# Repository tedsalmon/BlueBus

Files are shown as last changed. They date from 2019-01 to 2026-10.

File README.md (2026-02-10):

View this project on [CADLAB.io](https://cadlab.io/project/1479).

# BlueBus

BlueBus is a Bluetooth interface module for BMW vehicles equipped with the I-Bus. It emulates a CD changer on the I-Bus to provide seamless Bluetooth audio, hands-free telephony, and comfort feature integration while maintaining full compatibility with original vehicle systems.

## Supported Vehicles

BlueBus is compatible with BMW vehicles using the I-Bus architecture:

| Platform | Models | Years |
|---|---|---|
| E38 | 7 Series | 1994-2001 |
| E39 | 5 Series | 1995-2004 |
| E46 | 3 Series | 1997-2006 |
| E52 | Z8 | 2000-2003 |
| E53 | X5 | 1999-2006 |
| E83 | X3 | 2003-2010 |
| E85 | Z4 | 2003-2008 |
| E86 | Z4 | 2005-2008 |
| R50/R52/R53 | MINI | 2000-2006 |

## Features

### Bluetooth Audio
* A2DP streaming with high-quality audio output over AAC
* AVRCP metadata display (artist, title, album) on vehicle screens
* Full playback control via vehicle buttons

### Hands-Free Telephony
* HFP (Hands-Free Profile) with factory microphone integration
* Caller ID display on vehicle screen
* Answer/end calls via vehicle controls
* Telephone LED control (Red = Device Disconnected, Green = Connected)
* Voice recognition support via Siri / Google Assistant
* Emulation of OE telephone system (Minus the Menus, for now)

### Vehicle Integration
* Native DSP compatibility (analog and S/PDIF inputs)
* On-Board Computer data display (coolant temp, ambient temp, oil temp)
* GPS time synchronization for vehicles with factory Nav
* Park Distance Control integration

### Comfort Features
* Auto-lock at configurable speed threshold
* Auto-unlock on ignition off
* Comfort turn signals (Tap to signal)
* Parking lamp control

### System
* Firmware upgradable via USB
* Multi-language support (9 languages)
* Up to 8 paired Bluetooth devices

## Supported Display Units

| Unit | Description | Display |
|---|---|---|
| BMBT | Board Monitor (Navigation) | Full graphical menus |
| MID | Multi-Information Display | 24-character single line |
| CD53 | Business CD Radio | 11-character single line |
| MIR | Multi-Information Radio | Single line display |

## Hardware

### Core Components
| Component | Description |
|---|---|
| PIC24FJ1024GA606 | 16-bit MCU @ 16MHz, 1MB Flash |
| BM83 | Microchip Bluetooth 5.0 Module |
| Melexis TH3122.4 | I-Bus Transceiver |

### Audio Chain
| Component | Description |
|---|---|
| PCM5122 | Line-Level DAC, 2.1V RMS, 113 dB SNR |
| DIT4096 | S/PDIF Encoder |
| PAM8406 | 5W Class-D/Class-AB Amplifier |

### Interfaces
| Component | Description |
|---|---|
| FT231XS | USB to UART (firmware updates) |

## Configuration

Settings are stored in EEPROM and can be configured through the vehicle display menus. Categories include:

* **Audio** - DAC gain, DSP input source, volume offsets
* **Telephony** - HFP mode, microphone gain, volume
* **Comfort** - Auto-lock speed, blinker count, lighting options
* **UI** - Language, temperature units, display preferences
* **Navigation** - Auto-zoom, map display mode

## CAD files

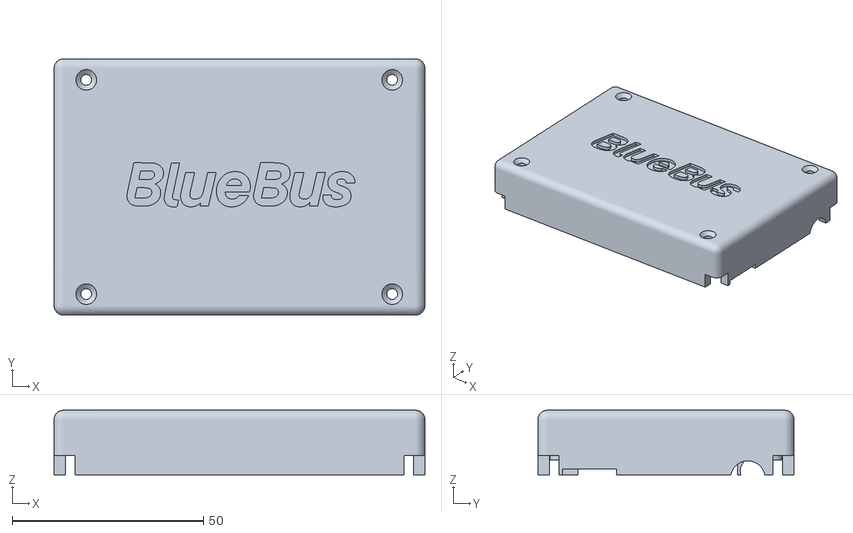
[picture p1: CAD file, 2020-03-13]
enclosure/hw1_v1/BlueBus_Top.stl
97.0 x 67.0 x 16.9

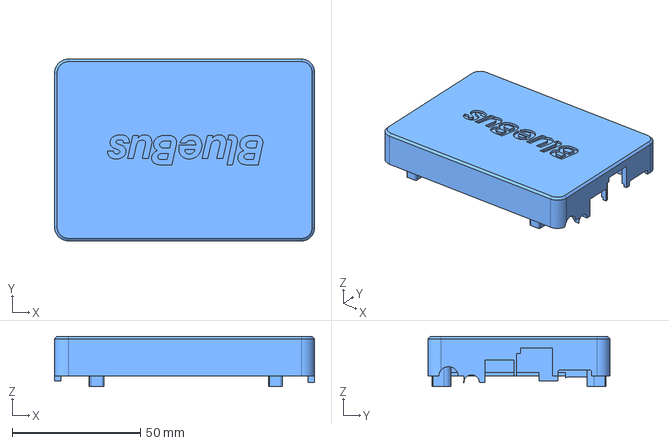
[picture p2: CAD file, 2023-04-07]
enclosure/hw2_v3/BlueBus v3 Top.step
101.5 x 71.0 x 19.7 mm

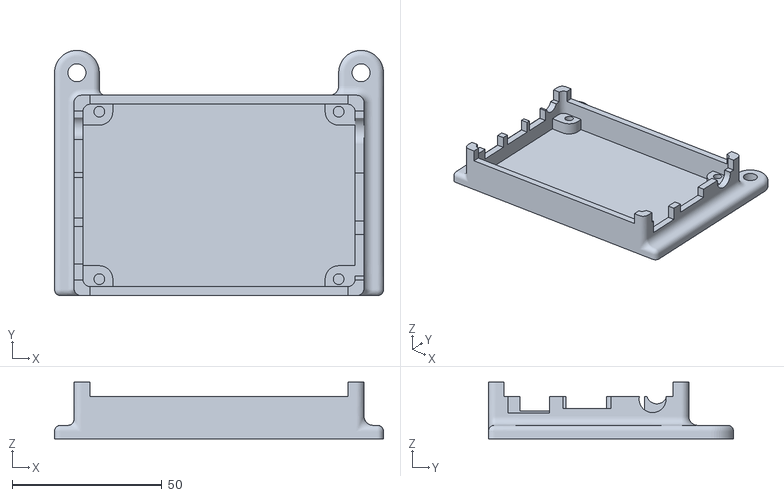
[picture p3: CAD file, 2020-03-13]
enclosure/hw1_v1/BlueBus_Bottom.stl
110.0 x 82.0 x 18.9

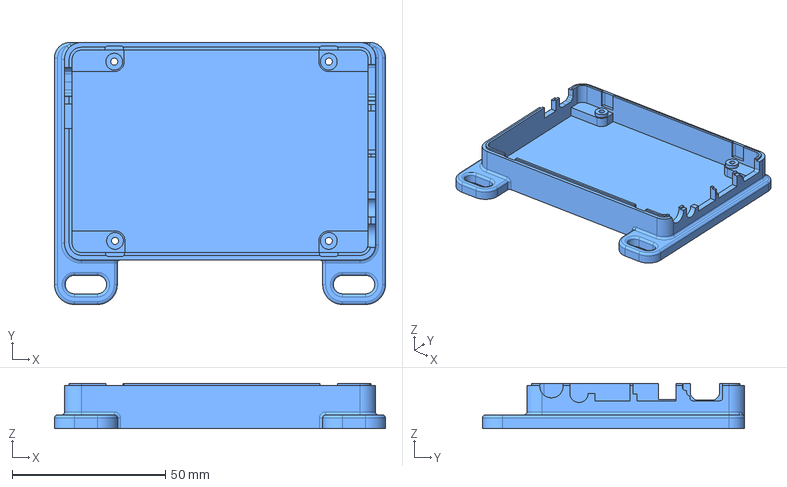
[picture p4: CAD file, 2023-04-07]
enclosure/hw2_v3/BlueBus v3 Bottom.step
108.0 x 85.5 x 14.8 mm

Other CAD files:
enclosure/hw2_v3/BlueBus v3 Bottom.stl
enclosure/hw2_v3/BlueBus v3 Top.stl

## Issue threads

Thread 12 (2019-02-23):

Clear "Track" from C43 based nav units

tedsalmon, 2019-02-23:

tedsalmon, 2019-04-02:
This was fixed in 45bc7327c35bebcffc25bb4a61e0422613abcdb5

Closed 2019-04-02.

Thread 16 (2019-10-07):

Feature Request : Door Unlock/Lock Comfort Entry

mykekfz, 2019-10-07:
Hello Ted,

How bad will power consumption be if we were to search for paired devices every 2 secs?

I'm thinking of a comfort entry feature where if the module detects a paired device, it send the message to unlock the door the opposite happens when paired devices are not within range.

let me know what you think.

Mike

harryberlin, 2019-10-07:
Did you have tried to unlock with ibus message the car, after secure lock?

tedsalmon, 2019-10-09:
Hey Mike (@mykekfz ),

Power consumption of the unit at idle is about 50mA. It could theoretically be used to lock / unlock the car, but people like myself, who have an attached garage might run into issues as the car would constantly lock/unlock as the phone comes into proximity with the vehicle.

Futhermore, the module is designed to power off with the rest of the car and wake up after the reception of the next IBus message. This is to prevent the module from flattening your battery over time.

@harryberlin ,

I'm sorry, but I haven't actually done any testing with the Unlock/Lock IBus message(s), so I can't answer your question :(

Thanks!
-Ted

mykekfz, 2019-10-10:
Hello Ted,

Will using the command "RSSI" be helpful with scaling the proximity of the connected device?
as for battery draw, i don't think it will be an issue since the draw is so minuscule doubt it will be an issue. You can always notify the user about the consequences of this feature if they were to activate it.

@harryberlin i dont see why it will not work since the command to unlock (key press from remote) its also sent through the but i could be wrong.

@Ted is there a way/command i can use to send RAW bus message for testing?

Regards,
Mike

tedsalmon, 2019-10-11:
@mykekfz (Mike),

That might work, but I feel like it may lead to some wonky results as different cars will have the BlueBus installed in different locations which will lead to different signal strengths at different distances. Still, a very good idea!

Let me digest it a bit and see what I can come up with.

I will send you a firmware that will allow you to send messages directly to the IBus

Thanks!
-Ted

ShonkyCH, 2019-10-11:
50mA is quite high for a car although may not seem like it's that much. It's certainly not "miniscule".

BMW maximum spec is 30mA. Most are in to 30-50mA range. So an extra 50mA (assuming the worst case 30mA) is 2-3x that in total.

tedsalmon, 2019-10-11:
@ShonkyCH,

You're right and I forgot to touch on that aspect. I did the math on this for an E46 a while back and the draw would flatten the battery in about a month, which is why I decided to implement "sleep" mode where the BlueBus goes to sleep 60 seconds after the last IBus message and wakes up on the next message.

Daily driven cars would have no problem with this type of drain, but any cars that sit for more than a few days may experience issues.

Thanks!
-Ted

harryberlin, 2019-10-11:
in my case (e39), the gm don't processes diagnistic actions, if the car is secure locked.

Tomcatex, 2019-12-12:
Hello Ted,

Just had an idea and I stumbled upon this thread.
About comfort locking, can you add a feature to unlock the car, if it has been previously locked, when the key is pulled out?
My E39 locks automatically when speed is about 20km/h. But it does not unlock when stopped.
Can you add something so that car unlocks (VW-group has this) when key is pulled out?

Thanks

tedsalmon, 2019-12-17:
@Tomcatex,

Sorry for the delayed response. This should be pretty easy to implement, honestly.

Since the car has just been turned off, the GM should still listen for diagnostic commands.

Thanks!
-Ted

mykekfz, 2019-12-23:
ca

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

Cant this be done via coding with NCSexpert?

tedsalmon, 2019-12-23:
@mykekfz,

Yes, on some vehicles the GM will allow you to code that. I'm not ready to code the GM via the BlueBus just yet, so having an option for it makes sense still :)

Thanks!
-Ted

mykekfz, 2019-12-23:
I was just thinking of MCU available space.

If a feature is available via simple coding, I don't see the point of it adding to the bluebus.

On the flip side not everyone knows how to use ncsexpert.

tedsalmon, 2019-12-23:
@mykekfz,

I'm not too worried about MCU space just yet -- I have 94% ROM remaining as it is :smile:

It would be nice to allow the BlueBus to simply code the option in the GM, rather than using Diagnostic commands.

harryberlin, 2019-12-23:
it is pobble to lock the car by speed from ibus. so you don't coding.
but one point there are different messages between e46 and e39, old and new models.

tedsalmon, 2019-12-23:
> it is possible to lock the car by speed from ibus. so you don't need coding.
> but one point, there are different messages between e46 and e39, old and new models.

I noticed this as well -- looks like the E46 takes `0x97 0x01` to unlock, while the E39 takes `0x00 0x0B` to unlock. Similar differences exist in terms of the LCM bulb diagnostic messages.

Tomcatex, 2020-01-15:
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

I have NCS. Is there a specific line for this? Can yo post any more info?
I tried to find it, no luck.

E39 '02 Euro 525d, LCM III.

harryberlin, 2020-01-15:
on e39 you have to log the kbus for groundmodul

tedsalmon, 2020-02-12:
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

For what it's worth, the above diagnostics messages are all that's available. In my E46, it appears that the EWS "key out"/"immobilized" message is what prevents the GM5 from processing any further messages. I have yet to test out artificially notifying the car that the EWS is no longer immobilized and then trying to run diagnostics.

tedsalmon, 2020-05-12:
FWIW, The BlueBus now supports comfort locks and unlock, but they are not done as OP requested due to limitations with diagnostic messages. I also can't perform diagnostics on the GM after the EWS has been armed (key removed), so there's that.

Thanks!
-Ted

Closed 2020-05-12.

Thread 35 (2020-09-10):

BlueBus display not redrawing

rsporsche, 2020-09-10:
I have a German delivered 1999 E39 M5 with Business Audio (tape) and MID.

I've noticed that the MID display is very quickly overwritten and the BlueBus is not redrawing.

Example: If I click the 'Settings' button for BlueBus, I see 'Settings HFP: On' displayed and the menu updates with Back, Edit, <, >, etc. But this is quickly replaced by the CD changer display and menu, i.e. 'CD 1-01' and '*1, 2, 3, 4, etc.'. My understanding is that the BlueBus would see that the display had been redrawn by the RAD or IKE and immediately redraw it's own text but that is not happening.

I have attached a log file, demonstrating this.

The firmware version is 1.1.14, I noticed that there is a 1.1.16, should I upgrade?

Note that I have also had some other issues such as BlueBus responding to button presses when it should not (e.g. when changing bass/treble/etc.) and a few times the radio has 'lost' the BlueBus and I can only select radio or tape. I don't know whether these issues are related so I will create separate issues when I have been able to captures logs.

The attached log file was created with 'bt', 'sys' and 'ibus' on but I had to unplug the USB and cycle the ignition after setting those initially and I don't know whether that would have affected these settings. I assume by the volume of ibus messages that it did not.

[[Com COM3] (2020-09-09_160349).log](https://github.com/tedsalmon/BlueBus/files/5204500/Com.COM3.2020-09-09_160349.log)

tedsalmon, 2020-09-11:
@rsporsche,

This is directly related to #2, but I will keep it open nonetheless. The issue is that the MID doesn't like how quickly the BlueBus writes the UI again, so some things are missed at times.

However, I am working on hijacking the UI by emulating the factory TEL module. The MID lends itself wholly available to the TEL and prevents other modules (DSP, RAD) from writing to it while the TEL view is active. This would allow me to ignore the tug-of-war with the RAD.

I'll have more on this soon.

Thanks!
-Ted

harryberlin, 2020-09-11:
test in my case: MID without phone option/button does not handle the phone messages.

tedsalmon, 2020-09-11:
@harryberlin,

Can you try issuing this frame on the I-Bus?

`C8 04 C0 27 02 41`

The display should blank out and accept messages from the TEL.

Thanks!
-Ted

tedsalmon, 2020-09-11:
@harryberlin,

If that doesn't work, also issue these messages:

```
C8 04 BF 02 31 40
C8 04 C0 02 30 3E
```

Then issue:
```C8 04 C0 27 02 41```

harryberlin, 2020-09-11:
will take some time. because, MID is not connected at the moment.

rsporsche, 2020-09-11:
>
> The issue is that the MID doesn't like how quickly the BlueBus writes the UI again, so some things are missed at times.
>

Based on the log file it looks as though the BlueBus isn't issuing the ibus commands to redraw the UI though?

I'm assuming that the lines marked [SELF] are commands sent by the BlueBus and the leading number on each line is uptime in milliseconds?

Btw, I have some experience in software development, also with embedded systems, and would be happy to help with this project particularly as related to the MID interface if possible. The only drawback is that the only device I have to test on is the one in my car.

tedsalmon, 2020-09-11:
@harryberlin,

No worries, I appreciate you testing. Please note that I have updated the frame as I gave the XOR checksum in decimal rather than octal :(

@rsporsche,

That happens too, because the BlueBus tries to differentiate its own menu writes from that of the RAD, which means looking at the nuances of the way the RAD writes to the screen -- another reason to move into a bespoke UI mode.

The `[SELF]` messages are frames sent by the BlueBus and you're correct about the timestamp.

Are you based in the U.S.? I have a boneyard of BlueBus prototypes and units that failed due to the recall issue, and I can definitely spare one of those :).

-Ted

rsporsche, 2020-09-11:
I wondered if it would be an option to keep track of the commands that were issued by the BlueBus to update the MID and redraw if a MID display command is seen that doesn't match that 'known' set?

Maybe the TEL idea works better though.

I'm in Germany unfortunately. I wasn't thinking so much of the BlueBus but more the radio/MID. I guess I would also need the IKE?

Is it possible to 'brick' the BlueBus?

tedsalmon, 2020-09-11:
@rsporsche,

This isn't as easy as it sounds because I have to wait until the RAD is done "speaking" in order to override the MID display again, otherwise things are liable to not write out consistently. That means "knowing" when the RAD is done speaking. This is why I want to move to bespoke UI mode :smile:

You only need a RAD/MID for a bench setup. The IKE is icing on the cake (I have a 540i IKE, but I don't use it with the MID).

It is not possible to brick the BlueBus. The bootloader lives in the first 0x1800 addresses of memory and has been protected against accidental writes. See: https://github.com/tedsalmon/BlueBus/blob/master/firmware/bootloader/lib/protocol.c#L74

tedsalmon, 2020-09-11:
@rsporsche,

Can you please try: https://t3ddftw.s3.us-east-2.amazonaws.com/BlueBus/firmware/bluebus_1_1_15_mid_tel_ui.hex

You will need to use the `Audio` button to exit the BlueBus UI. Any subsequent presses of the 1 - 6 buttons will force the MID to enter "BlueBus" mode again.

Text scrolling is still a bit off, but it should at least stay pinned to the MID.

Thanks!
-Ted

rsporsche, 2020-09-24:
Thanks Ted, just installed the new firmware today.

First impressions are that the Bluebus menu works now but it's still responding to button presses when I think it shouldn't.

Example: I press the TONE button by the tape deck and it shows me options for bass/treble/etc. but if I click one of those it immediately switch back to the BlueBus.
Same if I press the BC button on the MID and try selecting any of the options such as CONS/RANGE/etc.

I logged the output while pressing the TONE, AUDIO, and BC buttons ten times. Looks like there is a message for the BC and AUDIO buttons that could be detected but nothing that I can see for the TONE button, presumably it's part of the radio so the radio only writes to the display.

I'm wondering if it would be possible to detect when these buttons are pressed and switch out of the BlueBus menu mode until the AUDIO button is pressed again?

Also, the MODE button is effectively lost when entering the BlueBus menu. I guess this is what you mean by "You will need to use the Audio button to exist the BlueBus UI"? I think it would be possible for the BlueBus to handle the mode button press though?

tedsalmon, 2020-09-24:
@rsporsche,

This firmware should fix those issues: https://t3ddftw.s3.us-east-2.amazonaws.com/BlueBus/firmware/bluebus_1_1_15_1.hex

On the MODE button issue, it is technically possible, but ultimately difficult to emulate the MODE button press. The new firmware places the MID in TEL mode, so the RAD stops listening to commands / button presses from the MID (and the MID stops addressing the RAD). I would have to give up TEL UI mode, then emulate the MID mode button press, and this can be clumsy depending on the amount of bus traffic at the time.

Thanks!
-Ted

rsporsche, 2020-09-25:
Thanks Ted,

So far it looks like a big improvement. I think it's at a point where I could live with it pretty happily.

Come to think of it, while it would be nice to retain the MODE button, I don't use the radio or tape so it's not really a problem.

I had been thinking I could create a device to isolate the radio on a second IBUS network and selectively relay messages, but not worth the effort at this point and wouldn't work as well with the 'TEL' GUI.

tedsalmon, 2020-09-28:
@rsporsche,

I'm going to mark this as resolved :). Here's the latest binary: https://t3ddftw.s3.us-east-2.amazonaws.com/BlueBus/firmware/bluebus_1_1_15_3.hex

This was resolved in 48396c9

Thanks!
-Ted

rsporsche, 2020-10-02:
Thanks Ted, I'll check out the latest version.
I noticed that the MID display seems to switch off when ending a call now but I'll log a new bug report for that if it still happens with the latest firmware.

tedsalmon, 2020-10-02:
@rsporsche,

This isn't a bug moreso than it is a lack of a feature. I tell the car that a call is active and the MID automatically blanks out because it expects the phone system to write something about the call to the screen, and I have yet to add that.

Thanks!
-Ted

harryberlin, 2020-10-03:
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

The message is working. The others had no effect.

Closed 2020-09-28.

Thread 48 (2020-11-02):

CD43 Support

E39NLA, 2020-11-02:
Enhancement request - are there any plans to support the CD43 head unit with bluebus? This would provide an obvious upgrade path to bluebus for E32/34/36 fans I would think. I believe this the only single-DIN style head unit out there with ibus support (the C33 and C43 cassette head units are "m-bus" I believe).

tedsalmon, 2020-11-02:
@E39NLA -

Thanks! The CD43 is already supported and I have a couple customers using a BlueBus in an E36 / E36 Z3.

Thanks!
-Ted

E39NLA, 2020-11-02:
Ah. Then I might have a technical glitch here. I have a CD43 in my E34 with a late E36 CD changer harness (that is, the 3pin ibus with 6pin audio connectors) spliced in to the radio harness. The ibus wire from the 3pin connector is run directly to Pin 7 at the back of the CD43. Pressing "CD" just gives me NO DISC. Bluebus shows the green indicator light for a few minutes then seems to power down on it's own. I've already verified all wiring is good (continuity OK).

Will note I am using a "generic" CD43 (i.e. the one Rover Group made under license from BMW) but everything I've read online assures me that the non-BMW CD43's support ibus. I have bench tested it by hooking it to a spare E38 MID I have and they do talk to each other.

tedsalmon, 2020-11-02:
@E39NLA

Try the following command in the BlueBus terminal:

`set ign alwayson`

That should allow it to work :smile:
-Ted

E39NLA, 2020-11-02:
Will give that a shot! Will that have any impact on bluebus use in my E39? Right now I only have one unit which I am intending to share between my two cars.

tedsalmon, 2020-11-02:
@E39NLA,

Yes, it will make it so the BlueBus connects and starts playing any time the E39 is woken up (unlocked, door open, etc). This isn't a problem with the E34 because the CD43 doesn't come to life without the key in the ignition.

Thanks!
-Ted

E39NLA, 2020-11-02:
Ah. So I take it that the bluebus is normally looking for a "wake" message from the ibus connection, and this configuration option tells it to ignore and turn on whenever 12V is applied.

tedsalmon, 2020-11-02:
@E39NLA,

The BlueBus expects the IKE/KOMBI to broadcast the ignition status, at which point the value determines the state of the BlueBus. Since the E31/2/4/6 aren't I/K-Bus cars, this data is unavailable. Setting `ign alwayson` tells the BlueBus to broadcast the ignition on status to itself as soon as it wakes up.

 See: https://github.com/tedsalmon/BlueBus/blob/master/firmware/application/handler.c#L238

-Ted

E39NLA, 2020-11-02:
Terminal is just giving me a "Command Not Found" error when inputting SET IGN ALWAYSON. Updated the firmware to 1.1.16

tedsalmon, 2020-11-02:
@E39NLA,

Oops, try:

`set ign alwayson on`

Similarly, to toggle it back off:

`set ign alwayson off`

See: https://github.com/tedsalmon/BlueBus/blob/master/firmware/application/ui/cli.c#L472

Thanks!
-Ted

E39NLA, 2020-11-02:
Okay, getting closer. Accepted the command and when installed in my E34 it would pair to my phone. But the CD43 doesn't want to talk to it still. "NO DISC" like before.

tedsalmon, 2020-11-02:
@E39NLA.

Do you have a laptop you can plug into the unit while it's in the car? I would like to see if you're getting any I-Bus traffic when you issue the command: `set log ibus on`

Thanks!
-Ted

E39NLA, 2020-11-02:
Yes I'll give that a shot.

E39NLA, 2020-11-02:
Ok, got it all plugged into my laptop in the car. Entered the log ibus command.

tedsalmon, 2020-11-02:
> Ok, got it all plugged into my laptop in the car. Entered the log ibus command.

Can you run the command "get ibus"? It should return something...

E39NLA, 2020-11-02:
Get ibus just returns "OK"

tedsalmon, 2020-11-02:
> Get ibus just returns "OK"

You have an issue with the I-Bus, then.

Either theres a continuity issue, or you need to pull the I-Bus up to 12v through a 10k resistor.

Thanks!
-Ted

E39NLA, 2020-11-03:
Just checked the voltages at my ibus connector. Red (batt) is 11.99v, yellow (ibus or Pin 7) is 11.50v. Is the wire order correct at the connector?
![Uploading 20201102_185615.jpg…]()

tedsalmon, 2020-11-03:
@E39NLA

That looks fine, and the voltages are good. Can you run "reboot" before you run `get ibus`?

Make sure the radio is on, too.

Thanks!
-Ted

E39NLA, 2020-11-03:
Same as before. Get ibus yields only "OK." Rebooted both with and without the radio on.

tedsalmon, 2020-11-03:
@E39NLA,

And as a sanity check, everything works well in the E39 still?

Do you have an OE CD Changer to test on the E34?

Thanks!
-Ted

E39NLA, 2020-11-03:
Sadly I tossed out my E39 cd changer after I got the bluebus (it never worked anyways). May be able to borrow one from a friend in a few days.

Bluebus still works fine in the E39, no issues.

tedsalmon, 2020-11-03:
> Sadly I tossed out my E39 cd changer after I got the bluebus (it never worked anyways). May be able to borrow one from a friend in a few days.
>
> Bluebus still works fine in the E39, no issues.

With `set log ibus on`, when you issue the `get ibus` command, are you seeing the frame come back in the buffer? You should if the line is "good".

E39NLA, 2020-11-03:
Found this old cd changer simulator I used to use for aux input. Plugged it in and the CD43 would talk to it. Played off my phone just fine (3.5mm jack) with clear sound.

So I guess the ibus on the CD43 is working?

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

tedsalmon, 2020-11-03:
@E39NLA

Are you sure that's a CD43? I don't know them well enough to tell from the images, but what I do see is that your box is an M-Bus emulator, rather than I-Bus, which suggests the radio speaks with the CDC over M-Bus and not I-Bus...

Thanks!
-Ted

E39NLA, 2020-11-03:
Positive. I know the label says M-bus but that I believe is referring to the other side of the box, which is the DIN-8 connector used for Alpine CD changers. If you google the model (ABWM35) you'll see it was designed for I-bus BWM's. This box works in my E39 too, so I know it's an I-bus device.

tedsalmon, 2020-11-03:
> Positive. I know the label says M-bus but that I believe is referring to the other side of the box, which is the DIN-8 connector used for Alpine CD changers. If you google the model (ABWM35) you'll see it was designed for I-bus BWM's. This box works in my E39 too, so I know it's an I-bus device.

Are you based in the US? The only thing I can think of is that the BlueBus doesn't have enough of a pull up to 12v on the IBus line, so I can make a patch cable with a built in pull up.

Apart from that, I've got nothing, especially considering the BlueBus works fine in your E39.

-Ted

mykekfz, 2020-11-03:
OP what is the part number on the CD43?

there are 2 version of the CD43 mBUS version and IBus version.

E39NLA, 2020-11-06:
PN is 7640263342.

Ted: yes, I'm in Northern NJ.

E39NLA, 2020-11-08:
As an added test: have a donor E39 CD changer that I plugged into the CD43. Worked without issue.

tedsalmon, 2020-11-09:
@E39NLA

Do you happen to have a 10k ohm through-hole resistor laying around?

-Ted

E39NLA, 2020-11-11:
No, but I can certainly get my hands on one. How would I wire that in?

tedsalmon, 2020-11-11:
> No, but I can certainly get my hands on one. How would I wire that in?
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
E39NLA, 2020-11-12:
Couldn't I do the same by bridging the leads on the 3pin connector (I assume from iBus to ground)? I would prefer to keep modifications to car side if I can do it that way.

tedsalmon, 2020-11-12:
> Couldn't I do the same by bridging the leads on the 3pin connector (I assume from iBus to ground)? I would prefer to keep modifications to car side if I can do it that way.

Sure. You're bridging 12+ to I-Bus, btw :). This is a temporary test, too, so don't solder anything.

E39NLA, 2020-11-26:
Finally found time to try this and it seems to have done the trick! But I'm only getting a basic CD changer readout on the CD43. Am I supposed to be seeing more?

I guess I'll solder in the resister permanently on the E34 side?

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

tedsalmon, 2020-11-26:
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

Please don't solder anything! I can make you an adapter if you give me two or three weeks :).

The TH3122.4 is just a bit more sensitive to a weak pull-up on the I-Bus, it seems.

tedsalmon, 2020-11-26:
@E39NLA

I forgot to add, you will need to issue these commands to get a UI on this car. It won't be set automatically because the BlueBus expects a "full" I-Bus car so it can query the Light Module for the VIN and then determine if it needs to rethink the UI.
```
set ui 1
reboot
```

Thanks!
-Ted

E39NLA, 2020-11-26:
Gotcha. Will that cause any issues swapping from the E34 to the E39?

Will shoot you an email 👍

E39NLA, 2020-11-28:
So I've got it installed with a permanent 10kOhm bridging 12V to Ibus. Working good so far! I do however have a few minor issues:

1. Noise/interference from right channel that increases with engine rpm.

2. After entering "set ui 1" I got track readout on the CD43 but the next track/prev track became buggy (had to hit it twice in quick suggestion for it to register). Hitting the radio preset buttons doesn't seem to do anything.

3. With TTY connected im getting a lot of [DEBUG] messages. Will post log. Is this normal?

E39NLA, 2020-11-28:
[bluebus.log](https://github.com/tedsalmon/BlueBus/files/5610192/bluebus.log)

Log here. I also noticed that the bluebus appears to be on all the time (green LED). E34's don't really got to sleep like the later cars, so is there any way to specify an auto shutdown (or perhaps a new CD43-type profile that includes that? Just a thought).

tedsalmon, 2020-11-28:
@E39NLA

The BlueBus is set to go to sleep after 61 seconds with no I-Bus traffic. Since the E34 doesn't include ignition status or any other IKE traffic on the I-Bus, it is impossible to make the BlueBus sleep after some time without coding in the ability for it to shut off on you mid-drive.

I'll check the log a little later -- thanks for that!
-Ted

E39NLA, 2020-11-28:
Wouldn't it be possible to have bluebus go to sleep after 61 second of no phone paired/bluetooth communication?

LMK if you need more logs pulled with different circumstances/setup.

tedsalmon, 2020-11-29:
> Wouldn't it be possible to have bluebus go to sleep after 61 second of no phone paired/bluetooth communication?
>
> LMK if you need more logs pulled with different circumstances/setup.

@E39NLA

Sure, but I don't particularly like that idea as if there is still I-Bus traffic at the time, there's a good chance the unit won't be able to shut itself off as it is bus traffic triggered.

Can I get a log (enable I-Bus logging and sys logging, please) of you leaving the car off for two minutes?

I'd you're unfamiliar these are the logging commands you need to run:

```
set log sys on
set log ibus on
```

Thanks!
-Ted

blehn, 2022-08-28:
@E39NLA Did you ever get your BlueBus working reliably with the CD43?

tedsalmon, 2022-10-06:
@blehn I don't know about @E39NLA but I do have a few users running it on the CD43 successfully.

Closing this as I believe we should be golden.

-Ted

SecT0uch, 2024-01-23:
I have the same issue, my Bluebus won't switch off.

It seems there is still ibus traffic with the car off and key out:
```
# get pwroff
Auto-Power Off: On
OK
# set log ibus on
OK
# [450007] DEBUG: IBus: RX[6]: 18 04 FF 02 01 E0 [SELF]
[471007] DEBUG: IBus: RX[6]: 18 04 FF 02 01 E0 [SELF]
[492007] DEBUG: IBus: RX[6]: 18 04 FF 02 01 E0 [SELF]
[513007] DEBUG: IBus: RX[6]: 18 04 FF 02 01 E0 [SELF]
[534006] DEBUG: IBus: RX[6]: 18 04 FF 02 01 E0 [SELF]
[555007] DEBUG: IBus: RX[6]: 18 04 FF 02 01 E0 [SELF]
[576006] DEBUG: IBus: RX[6]: 18 04 FF 02 01 E0 [SELF]
[597007] DEBUG: IBus: RX[6]: 18 04 FF 02 01 E0 [SELF]
[618007] DEBUG: IBus: RX[6]: 18 04 FF 02 01 E0 [SELF]
[639007] DEBUG: IBus: RX[6]: 18 04 FF 02 01 E0 [SELF]
set log ibus off
OK
```

Could it be related to the alarm system ?

Z3 coupé (E36)
BMW Business CD RDS
Model: BP0273
Made by Blaupunkt

tedsalmon, 2024-01-23:
@SecT0uch

Try:

`set ign alwayson on`

SecT0uch, 2024-01-24:
Unfortunately, the Bluebus still stays on

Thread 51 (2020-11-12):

Comfort Blinkers cause dash brightness adjustment to stop

calmelb, 2020-11-12:
Whenever comfort blinkers are on (and only when those are specifically blinking) the dash brightness control and the headlight level adjustment control are no longer controllable for a period of time after the last blink.

However if the blink is only once or its set to the second detent (so fixed on) then it functions as normal.

Running 1.1.16 on an E46 Pre-LCI with the Blaupunkt Head Unit (Car has no auto-headlights and no Xenons)

piersholt, 2020-11-12:
**_Challenge accepted._**

tedsalmon, 2020-11-12:
@calmelb,

For clarity, @piersholt previously did some _serious_ refactoring of the comfort blinkers code. In that, he moved away from terminating LM diagnostics to simply shutting down all bulbs activated by diagnostics in order to avoid throwing the LM into limbo  in certain use cases. Leaving the LM in diagnostics mode is what's causing this issue. It clears up after 15 seconds as that is the timeout for diagnostics on LSZs.

Thanks!
-Ted

piersholt, 2020-11-13:
It's somewhat obfuscated unless you dive into the light module object files, but it's the inputs that are being activated, or more specifically, the voltage for the various input switches. An example of the blinker switch voltages:

```
STAT SWITCH BLK SHORT ON GROUND   0-1v
STAT SWITCH BLK LEFT ON           1-2.5v
STAT SWITCH BLK RIGHT ON          2.5-4v
STAT SWITCH BLK SERENITY          4-5v
```

Whenever a switch voltage is set, any additional input from the "real" switch will cause the switch to end up in limbo as Ted pointed out. In order to prevent this, the switch voltage needs to be reset. In this case, the blinker switch voltage is set to `0`.

There's a catch that isn't apparent in the functionality - the voltage of any potentiometers is transposed into the activation command. Given there's no "off position" (or positions, at all for that matter), if the voltage doesn't match the "real" switch voltage, then any vehicle functions controlled by potentiometers will change accordingly - manual vertical headlight aim (HVAC), automatic headlight beam throw adjustment (LWR), instrument backlighting (58G) etc...

I didn't consider the potentiometers as they are "set and forget" for me.

_I'll tinker..._

calmelb, 2020-11-13:
@tedsalmon Thanks for the explanation! Love how complex this all is

@piersholt I only happened to note as only once it reset the instrument backlighting to the lowest level and then I realised I couldn't adjust. Is also a set and forget for me but I thought I would at least file a bug. Is very fascinating how it all works (as someone who has had an interest in electronics and now a gaining interest in how cars communicate over the -BUS) to be fair

piersholt, 2020-11-13:
@calmelb

> I only happened to note as only once it reset the instrument backlighting to the lowest level and then I realised I couldn't adjust. Is also a set and forget for me but I thought I would at least file a bug.

It's certainly helpful feedback. Thanks for being constructive ☺️

> Is very fascinating how it all works (as someone who has had an interest in electronics and now a gaining interest in how cars communicate over the -BUS) to be fair

That's how it began for me, and I'd guess, for Ted too!

piersholt, 2020-12-16:
I had a chance to test this yesterday, and I was able to replicate the behaviour.

I tinkered with a possible viable solution, but I'll do some further testing.

JananasCzech, 2023-02-27:
Hi guys, i think that a have same issue like @calmelb
I will test turn off comfort blinkers when i get my car from repair shop :D
Brightness start switching from max setting to min setting 6 months ago and i cannot find whats wrong.
I try change Licht module but nothing change. Thanks for thread ! :)
I will write update when i got a time.

piersholt, 2023-03-11:
@JananasCzech this is a _very_ specific issue. You'll only encounter this if you're manually adjusting the instrument backlighting via the dial within about 20 seconds of the comfort blinkers being active.

JananasCzech, 2023-03-23:
@piersholt ok thanks for the info,
How to correctly get from this issue?
unplug battery in car? unplug blueBus?

I changed the setting for comfort blinkers to 8 and after a few days to 5 and then to 4 (originally from 3) and it seems that it is working fine right now.

so far i have seen this problem occur only once in the last 3 weeks. Anyway, an improvement.

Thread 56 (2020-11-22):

BMW Z4 Coupe - unlock rear hatch

maupineda81, 2020-11-22:
As per the title, could it be possible to also unlock the rear hatch in the BMW z4 coupe along with the side doors when powering the car off?

tabor-a, 2020-11-23:
And the E46 Touring rear window and door.

tedsalmon, 2020-11-23:
Just so no one's hearts are broken, this all depends on the EDIBAS API and the original developers thinking ahead to make a diagnostic test for these locks 😁

tedsalmon, 2020-11-23:
Alright @maupineda81 and @tabor-a

Since y'all want the feature, you're now in charge of helping to make sure that what I found is the correct command :smile:  --

`3F 00 00 0C 63 01 00`

This is listed as the `MERHK` job -> `Motor Entriegeln Heckklappe`. The door locks are currently actuated with the `MER` job, so  I suspect this is what we want.

Please follow this process: https://github.com/tedsalmon/BlueBus/wiki/Accessing-the-Terminal

Then, with the trunk locked and the ignition in position 1, run this command:

`send ibus 3F 00 00 0C 63 01 00`

Thanks!
-Ted

maupineda81, 2020-11-25:
I ted, I have run the command, all I get is an OK message

********************
~~~~~~~~~~~~~~~~~~~~~~~~~
BlueBus Firmware: 1.1.16
Try HELP or ?
~~~~~~~~~~~~~~~~~~~~~~~~~
# send ibus 3F 00 00 0C 63 01 00
OK
#
********************

but no physical change.

tedsalmon, 2020-11-25:
@maupineda81

Thanks for testing -- I wonder if BMW considers it a "tailgate".

Please try:

```
send ibus 3F 00 00 0C 95 01 00
```

Thanks!
-Ted

maupineda81, 2020-11-25:
Same result. let me see if I can find a command in Tool32

maupineda81, 2020-11-26:
Hello Ted, I was able to find the central locking command in tools32... it is under ZKE5_S12.

I am attaching two files, one that has the command definition and the run of it, where you can see the HEX instruction (Central Locking Command.txt)

I am also attaching the GM5 module table, it is in german, but I will look into the jobs available.

Let me know if this works, or is useful. Without knowing how the current implementation works, calling the central locking switch may not be ideal, as if the car was open when switching the car off, it will close the doors, so I think the right way of doing it is by calling status, and only if close, the open.
[CentralLockingCommand-Z4.txt](https://github.com/tedsalmon/BlueBus/files/5600019/CentralLockingCommand-Z4.txt)
[GM5Table-Z4.txt](https://github.com/tedsalmon/BlueBus/files/5600020/GM5Table-Z4.txt)

tedsalmon, 2020-11-26:
@maupineda81

Thanks for finding this! Try this:

```
3F 00 00 0C 03 01 00
``

In any case, I do track the central locking status. I will have a better look at all of this over the weekend.

Thanks!
-Ted

maupineda81, 2020-11-26:
it worked!!!

maupineda81, 2020-11-26:
After seeing the commands in GM5, would it be possible for the BB to fold the mirrors when turning the car off, and unfold at ignition in position 1? Just a thought.

BTW, I tried running the command from toolset32 but did not work, I may not be using the string correctly and ran out of time. I i usually do it in ISTA+ and then read the log file, that is how I found the unlocking commands.

tedsalmon, 2020-11-26:
Looks like unlocking tailgate is `3F 00 00 0C 02 01 00`, now that I look at the list of jobs again. When the BlueBus usually unlocks the doors, does the gas filler also unlock?

Mirror folding is covered in #24 ;).

Thanks!
-Ted

maupineda81, 2020-11-26:
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

Hi Ted, no, it does not, just the doors, with the command you gave me yesterday evening (3F 00 00 0C 03 01 00), it did. It unlock the hatch and the gas filler cap.

tabor-a, 2020-11-26:
> When the BlueBus usually unlocks the doors, does the gas filler also unlock?
The fuel filler door unlocks when the driver door is unlocked from the key fob and remains unlocked until the driver door is locked again.

arrdem, 2023-05-19:
Verified

```
send ibus 3F 00 00 0C 63 01 00
```

as a working trunk unlock on my e85m

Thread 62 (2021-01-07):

Static/scratching noise heard from speakers

bimmerluvr, 2021-01-07:
I recently received my Bluebus and connected it as per youtube videos. I have discovered a few issues.

First, there is a static noise present while the head unit is powered on and the source is set to "Bluetooth" and not playing audio as well as during playback. The noise is subtle while the engine is off and much louder with the engine running.

Today, I removed the rear panel again just to double-check all the connections. Everything looks good.  I noticed the ibus/power  cables were routed close to the audio/remote wire of an aftermarket amp I have installed. Thinking there may be some interference, I routed the cables away from the others. Tested again. No change.

Below are a couple of videos that show the issue while the key is in position I and II:

https://youtu.be/STgPINLZzVc

https://youtu.be/DT2ywxvu06I

Second, I opted for the TCU emulator cable. The BMW OE mic does not pick up any audio. The party on the receiving end only hears static. I really do not know how to troubleshoot here since it appears to be plug and play.

Third, I tried to upgrade the firmware on my unit and the firmware tool will not connect. I tried several times with two different USB cables with no luck.

Thank you in advance for your help!

calmelb, 2021-01-07:
With the second part, do you actually have a microphone installed in your roof (for all non convertibles)? Take a torch/ flashlight and shine it into the little grill and see if there’s something there.

Otherwise if it’s there take the panel down and look to make sure it’s properly connected in case it’s come loose.

With the third issue, you may have been unlucky with 2 cables that don’t have the data connections on it, try and find one that’s used for mobile phone syncing or similar to make sure it actually has the required data pins

tedsalmon, 2021-01-10:
@bimmerluvr

>First, there is a static noise present while the head unit is powered on and the source is set to "Bluetooth" and not playing audio as well as during playback. The noise is subtle while the engine is off and much louder with the engine running.

The noise from the video is inherent to the system. Every car using analog audio has this noise present, but it's not the BlueBus's fault -- it's the I/K-Bus bleeding impulse noise (when the line gets pulled low to transfer a byte)  into the line level audio input from the CD Changer. To verify, unplug the six pin audio connector from the BlueBus and you'll note that the noise gets way worse. I recommend you max the volume on your phone and you'll never need to crank the volume high enough to hear this. If this car has Nav, you might be able to fix it with some creative wire routing.

>Second, I opted for the TCU emulator cable. The BMW OE mic does not pick up any audio. The party on the receiving end only hears static. I really do not know how to troubleshoot here since it appears to be plug and play.

If @calmelb 's suggestion is not true and you do have a microphone, then there may a licensing issue with the BlueBus (very unusual but it's just a software issue).

In terms of not being able to update the BlueBus firmware, if you're using Windows then you may need to ensure the FTDI VCP Driver is installed and Windows is recognizing it as a COM port. It could also be that the BlueBus case is getting int he way, so you may need to crack it open slightly.

Thanks!
-Ted

bimmerluvr, 2021-01-11:
Thank you for your responses thus far.

@calmelb My car did not come equipped with a factory microphone. I purchased one on eBay as per the recommendation on the  Bluebus forum thread. Interestingly, my mic was delivered with the original pigtail still attached. The one I received only had 2 cables whereas the same connector in my car has 4 cables. If in fact there is a software issue, is there a way to overcome this?

@tedsalmon Based on your explanation, I now understand the noise is normal. I did briefly disconnect the six pin audio connector the other day and can confirm the noise got way worse. I always max the volume on the phone also. I do not have factory nav so that's that. End of discussion.

I will confirm the correct driver is installed on my laptop and open the box if necessary. I will then try to connect again.

Bluebus is a wonderful product! I love being able to add features such as the multiple turn signal flashing, it is one reasons why I made this purchase. I thought I could also "code" automatic door unlocking as well but I do not see that setting. Is that a current or future setting? I am fairly confident I read or saw it on a video somewhere!

tabor-a, 2021-01-11:
> the same connector in my car has 4 cables

Sounds like that might not be the microphone connector?  The microphone connector should be a black 3-pin connector.  Other connectors in the area could include the white HomeLink wiring connector. Take a look at this video:
https://www.youtube.com/watch?v=63ZTz_p0veA

bimmerluvr, 2021-01-11:
I still have the pigtail from the mic I received. I will compare the connectors but they both seem to be identical.

bimmerluvr, 2021-01-12:
@tabor-a I was able to confirm there are 3 leads in the connector on my car, not 4 as previously stated. The pigtail that came with the mic does have 2 leads. The connectors are similar just with different color wiring. I did dig around for additional cables and found the Homelink cable but nothing else similar that actually plugs into the microphone.

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

tedsalmon, 2021-01-12:
@bimmerluvr

Can I get the part number from the microphone? What year is your E46? Are you using the 54-pin adapter or SES adapter (One is black and the other is blue)?

> I thought I could also "code" automatic door unlocking as well but I do not see that setting. I am fairly confident I read or saw it on a video somewhere!

Yes, this is just not available through the UI yet. Please see #46 for that :).

Thanks!
-Ted

piersholt, 2021-01-12:
@bimmerluvr @tedsalmon

I'd guess this microphone is from an E38 or early E39 given there's no shield.

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

tedsalmon, 2021-01-13:
@bimmerluvr

If @piersholt is correct, and he usually is, then the part number ends in 810 (IIRC) and it does not work with the BlueBus.

Thanks!
-Ted

bimmerluvr, 2021-01-13:
@piersholt

Thank you for providing the diagram and additional information.

@tedsalmon

Sure enough, the PN for the mic I have does end in 810. Interesting because I am usually very diligent with my research and I recall reading that the mic ending in 810 was the one to get.

My car is MY 2005. I believe the connector is black (I'd have to double-check).

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

tedsalmon, 2021-01-13:
@bimmerluvr

Weird, I've never seen that part come up in the forum conversations. Here are the part numbers known to work: 84318380338, 84318380319 and 84316938762.

Thanks!
-Ted

bimmerluvr, 2021-01-13:
@tedsalmon

Thanks for your help in troubleshooting so far and confirming the part numbers. I'll report back once I get the correct one installed.

tedsalmon, 2021-01-13:
@bimmerluvr

Great! Let me know when you're good to go so I can close the ticket :smile:

Thanks!
-Ted

piersholt, 2021-01-13:
> Thank you for providing the diagram and additional information.

No problem! 😊

> I didn't know the 810 part even existed until pretty late in the game when I encountered a customer with it. That's why it was never in the forum posts.

To be fair @tedsalmon, the 810 is pretty darn obscure. I couldn't even find a vehicle with it in the parts catalogue before @bimmerluvr provided the PN! It was [US only, and limited to early E38, and E39](http://bmwfans.info/parts-catalog/84318352810).

> Here are the part numbers known to work: 84318380338, 84318380319 and 84316938762.

@tedsalmon I checked my touring and I have PN [84 31 8 374 075](http://bmwfans.info/parts-catalog/84318374075/) which is a three pin shielded greenback like it's replacement [84 31 8 380 319](http://bmwfans.info/parts-catalog/84318380319/).

Might that be another option for @bimmerluvr? (I don't think 075 has come up before? Maybe I'm the guinea pig?)

bimmerluvr, 2021-01-17:
Gentlemen,

I settled on PN 84316938762. It is the most readily available on eBay and least expensive. I Will chime in once it arrives. Thanks again!

tedsalmon, 2021-01-17:
@piersholt

If you are able to test PN 84 31 8 374 075, I would very much appreciate that! I haven't run into the part, but knowing if it's compatible is important :)

Sounds good, @bimmerluvr !

-Ted

bimmerluvr, 2021-01-24:
Update: I received the mic ending in 762 and connected it last night. It works!!!

Thank you to all who contributed to this thread and helping me reach a solution.

tedsalmon, 2021-01-24:
Great to hear, @bimmerluvr !

Closed 2021-01-24.

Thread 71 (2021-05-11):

Handsfree Speaker Connection

mbt28, 2021-05-11:
Hi,

How is the handsfree speaker which is located under the steering wheel works? Is CD53 unit driving it? Or bluebus itself drives it with and external connector?

I have standard speakers with cd53, I have handsfree speaker but waiting for retrofitting.

Thanks,

piersholt, 2021-05-12:
If you could specify which model and year the vehicle is, that would be a great help. There's a multitude of telephone configurations between years, models, options etc.

tedsalmon, 2021-05-12:
@mbt28,

I'll take a wild guess that you're talking about an early (1999 - 2001) E46, right? If so, the speaker under the steering column is directly driven by the BlueBus, and the BlueBus has an amplifier dedicated to this. The TELNF+/- signal lines route from the telephone connector to the speaker in question on these cars. The same is applicable to E38, E39, E52 and E53 models that came without DSP the amplifier, except those cars received dual cone front door speakers, one cone was driven for media audio, and the other was driven for telephony by the TCU.

In later E46, all E8x cars and DSP Amplifier equipped cars, the BlueBus pushes call audio through the same TELNF+/- line, but it is routed to the Radio or the DSP depending on chassis. From there, the respective units drive the front door speakers.

-Ted

tedsalmon, 2022-06-29:
Closing this issue due to lack of response. I think we've given all the necessary information anyways :)

mbt28, 2022-11-04:
Hi Ted,

Sorry for late response, due to some issues I had to left my car in garage for a long time.

I have this head unit: Alpine, Model CD53, Part Number 65. 12-6 919 072

The car itself from 2002/01, no phone and cd changer prewiring exist. I ordered bluetooth antenna and bluetooth bracket for behind the rear seat mounting. Does my head unit have phone input or should I use the handsfree speaker? I will do the wiring from glovebox to bluetooth unit via 54pin connector.

Closed 2022-06-29.

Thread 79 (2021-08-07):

No sound on both ends while making BT phonecall

Marb06, 2021-08-07:
Two E38s build date 1999+

One E38 with the Motorola phone system where the antenna amplifier is next to the TCU. TCU housing is plastic. Partnumber on TCU module: 84216916565
The other E38 with the (Siemens?) black ''BMW'' wired phone with UTP cable and connector. Black metal TCU module with coax connection on the side. Partnumber on TCU module: 84116911042

Connected the DB25 connector to the car and Bluebus.

Everything else seems to work fine. Calls can be answered or stopped with buttons on steeringwheel or buttons on the 16:9 or 4:3 screen.  Number/name display works.
I can hear some very light crackling/change over in the front speakers when the call is made and when the call is answered and call is ended. There is no sound at all from both ends. Also no ringing/dialing sound.

Smarthphones: Iphone 11 and Huawei Mate 20 Pro

BT music streaming no problems at all. Works like a charm.

Other question:

Telephone function via main menu does not work? (The telephone menu where you can also make an emergency call) I can't enter telephone numbers or go in the phonebook. I gave the Bluebus permission to use the contacts and contactlist from my smartphone

Edit: Both cars have DSP.

tedsalmon, 2021-08-10:
Howdy!

Some units did not receive the CVC license, which results in zero call audio on both ends.

Fortunately I have a tool for this: https://github.com/tedsalmon/BlueBus/wiki/Clear-Voice-Capture

If the tool says "Working" for more than thirty seconds, close it out and try it in the car again.

Yes, the telephone menu is largely unimplemented. Displaying your contacts on the screen is not necessarily as easy as it sounds, unfortunately.

Thanks!
-Ted

Dashdot66, 2021-08-10:
Just tried on one of the two E38 mentioned above and it now works. Noticed however that when receiving a call no ring signal indicating the incoming call is heard. The screen does show the incoming call without the phone number, once the call is accepted the name (from my address book) of the caller is displayed.

tedsalmon, 2021-08-12:
@Dashdot66

The default configuration is to play the ringtone in-band, so that's weird. Can you follow this process: https://github.com/tedsalmon/BlueBus/wiki/Accessing-the-Terminal

Then run this command: `restore`

You'll need to pair your phone and BlueBus again after that.

Thanks!
-Ted

Dashdot66, 2021-08-13:
That solved it. Not sure what combination of settings caused that.

Thanks,
André

Closed 2021-09-03.

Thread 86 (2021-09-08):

Microphone not picking up my voice

nicjansma, 2021-09-08:
This may or may not be related to https://github.com/tedsalmon/BlueBus/issues/78, but I figured I'd open a separate issue in case it's a different cause.

I have a 2002 M3 (mfr date 11/2001).

I installed BlueBus last week, and the Bluetooth functionality is working great.  I can hear music from my phone through the car audio.

When I place a call, I can hear the other end of the line, but they can't hear me.  I've tried calling my wife, as well as an "echo" telephone number that should repeat what I say.  Neither pickup my voice.

I had to purchase and install a microphone for behind the mirror.  It's part number 84318380338 from ECS tuning.  I also purchased the Bluebus SES TCU Adapter ES#4158580 from there as well.

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

I'm not sure if it's related, but one note is that the microphone connection didn't perfectly match the car's pre-wired harness.  On the microphone, it has the little "stair pattern" (on the right side):

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

On the wire harness, there's an additional "downward edge" that extended out.  It wouldn't fit in the harness because of that extra edge.  In this picture, you can see some deformed plastic on the edge where I took a knife to cut that part out.  It now fits fine.

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

I've confirmed the harness delivers power and ground.

Is there anything I can debug here?

bcagnoni, 2021-09-08:
Hello Nic,

when I first installed the BB I had an audio issue. Both myself and the other side couldn't hear anything. I followd the procedure to apply the CVC license and this made the trick.

https://github.com/tedsalmon/BlueBus/wiki/Clear-Voice-Capture

Cheers,
Battista

Sent with [ProtonMail](https://protonmail.com/) Secure Email.

‐‐‐‐‐‐‐ Original Message ‐‐‐‐‐‐‐
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

tabor-a, 2021-09-09:
> I'm not sure if it's related, but one note is that the microphone connection didn't perfectly match the car's pre-wired harness. On the microphone, it has the little "stair pattern" (on the right side):

Are you sure that's the microphone wiring and not something else?

tedsalmon, 2021-09-09:
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

Hello @nicjansma!

One important thing to note about these cars is that every connector is color matched to the harness plug and the different key-ways are used to prevent things from being plugged in incorrectly at the factory. In your case as @tabor-a suggested, you have found the homelink connector and that's why it's not working. You need to dig around for the black 3-pin connector.

Thanks,
-Ted

nicjansma, 2021-09-09:
Thank you everyone!

After a lot of searching I finally found the proper black connector microphone cable tucked further into the headliner.  It fits great!  Thanks for the tip.

Unfortunately... my voice is still not being heard by whoever I call.  I can hear the other end's voice no problem through the car speakers.

@bcagnoni mentions with their issue that _both_ sides couldn't hear any audio, so I'm not sure if my issue (where only _my_ mic doesn't work) is related to Clear-Voice-Capture, but I tried to run this: https://github.com/tedsalmon/BlueBus/wiki/Clear-Voice-Capture

It connects find, says _Serial No: NNNN_.  Then when I do run _Apply cVc_, it gets stuck on _Waiting_ and never completes.  I've tried running it multiple times, resetting the BlueBlue in between/etc.  It never seems to complete.  I'm using MacOSX and have tried multiple USB cables.

I'm able to separately terminal into the unit and can see the terminal interface OK.

Are there any debug logs I can enable to figure out if the mic is really picking up my voice?

Or is there a way to tell if CVC already works and is licensed?

tabor-a, 2021-09-09:
Just a guess, but perhaps plugging the HomeLink wiring into the microphone did it in?

tedsalmon, 2021-09-09:
@nicjansma -
> Unfortunately... my voice is still not being heard by whoever I call. I can hear the other end's voice no problem through the car speakers.
As @tabor-a mentioned it's possible that supplying 12v on the ground pin caused issues for the FETs on the microphone.

Can you share pictures of how the BlueBus is wired to the telephone connector in the car?

> Or is there a way to tell if CVC already works and is licensed?
It's unlikely that this is your issue as you're able to hear the other side. Nonetheless, you can check:

```
set log bt on
bt license
set log bt off
```

nicjansma, 2021-09-22:
Picture of the car wiring:

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

Here's the license output:

```
~~~~~~~~~~~~~~~~~~~~~~~~~
BlueBus Firmware: 1.1.18
Try HELP or ?
~~~~~~~~~~~~~~~~~~~~~~~~~
# [79555] DEBUG: IBus: RX[7]: 5B 05 80 83 00 08 55
...
set log bt on
OK
bt license
[101850] DEBUG: BT: Send Command 'LICENSE'
OK
# [101870] DEBUG: BT: APTX=
[101881] DEBUG: BT: CVC=3A6B CB90 A9BF FC81 0000
[101885] DEBUG: BT: OK
...
set log bt off
OK
```

So the car's mic cable isn't powered?  Yeah I could see how the homelink might've fried it.

If the license stuff above looks OK, I'll just order another mic.

nicjansma, 2021-10-18:
I picked up another mic from ECS, and unfortunately the other side of the call still can't hear me.

Does the above license stuff look OK?

Is there anything else I can check?  I looked at a couple fuses but didn't see anything obviously blown.

tedsalmon, 2021-11-06:
@nicjansma - Sorry for the lag! The ones in the headliner though! They are connected, though.

-Ted

nicjansma, 2021-11-10:
Thanks @tedsalmon!  As far as I can tell, there is no voltage coming from the headliner mic wires.

I'm trying to determine if that goes through a fuse that might be blown, but haven't found it yet.

tedsalmon, 2021-11-14:
@nicjansma

It should be directly wired to the BlueBus. Any change you can pull the BlueBus from the case and test voltage (with everything connected) at the two microphone pins? You'll see them labeled once you flip the PCB upside down. You should also test from the bottom side of the PCB.

Thanks!
-Ted

nicjansma, 2021-11-28:
@tedsalmon really appreciate you debugging this with me.

I pulled the case off the BlueBus and tested the voltage when everything else was plugged in.  Mic+ and Mic- read ~11V.

However, when I try to read voltage at the mic's wire in the headrest, I never see any voltage across any of the pins.

Is there anything in between the BlueBus and the mic wire in the headrest?  A fuse somewhere?  I looked at the E46 fuse list and didn't see anything about a microphone.

tedsalmon, 2021-11-28:
@nicjansma

Did you get the 54-pin adapter or the SES adapter?  The only "break" between the headliner and the BlueBus would be the SES connector, where if that's is missing it's jumper, the microphone circuit is broken.

I assume you tested with the adapter connected to the BlueBus, yeah?

-Ted

nicjansma, 2021-11-28:
I got the SES adapter https://www.ecstuning.com/b-bluebus-parts/bluebus-ses-tcu-adapter/ses-tcu-adapter~/

Correct, the SES adapter is connected, though I'll examine that end as well.

tedsalmon, 2021-11-28:
@nicjansma

Can you send pictures of how everything is connected?

Can I also have pictures of both ends of the SES cable so I can ensure the wires are routed correctly?

-Ted

nicjansma, 2022-05-16:
Sorry for the long delay in responding here, I had the car wrapped up for the winter months.

I debugged this a bit further last weekend.  To start, I ran a continuity test between the microphone's plug/wire in the headliner and the 6-wire coming out of the SES adapter.  I could not find any wires from the plug in the headliner that had continuity with any of the wires in the 6-wire from the SES adapter.

I also looked to see if there was any continuity between ground and any of the wires from the plug in the headliner (by testing against the cigarette plug, as well as against a bolt in the doorway) and could not find any.

So at this point, I'm thinking the plug in the headliner has a break in it somewhere between it and the SES adapter?  I looked at my Bentley manual but couldn't find any obvious wiring diagrams that showed any other junction points after the wire leaves the headliner.

I can get those pictures if you think it'll help, but I'm leaning towards the headliner wires just not being connected to the trunk?

Any ideas?

tedsalmon, 2022-06-29:
Closing issue due to lack of response. Shoot me an email if this is still a problem!

Closed 2022-06-29.

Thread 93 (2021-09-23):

No sound in calls, “squeaky sound with RPMs”

hribecek, 2021-09-23:
Hi,

First of all a huge thanks to Ted for making our cars a bit more contemporary with this great device. :)

I have 2 issues with BlueBus in my E39.

1) when I make a phone call neither me nor the other person hear anything, it is just silence.

2) when I listen to music, especially to some classical music which is usually recorded with a bit lower volume - and therefore I need to turn the volume in the car up - there is high pitched "squeaky noise" in the background which is intensifying with RPMs. On idle you can barely hear it, but above 3000RPM it starts to be quite annoying. If I turn the volume down, it reduces as well and it is only present when BlueBus is selected.

My car is EU (delivered new to Germany) 03/2001 530i. Delivered with wide screen MK3 navi, HiFi sound (not DSP) and handsfree for some Motorola phone with a connecter and bay in the armrest.

Before installing BlueBus I already exchanged my navi for MK4 and I had installed the BMW ULF module for Bluetooth handsfree. I also removed the armrest bay for the Motorola and since it also served as a connection unit between cables to the handsfree module in the boot and the mic in front I did connect the pins in those armrest connectors when installing the ULF. I do not remember the exact pins as I did that maybe 7 years ago, but the ULF calling worked fine (apart being a bit low volume from the speakers, which I believe is normal for cars without DSP).

Any suggestions would be very appreciated.

tedsalmon, 2021-09-24:
Hello @hribecek!

Your telephony issue sounds like you're missing the clear voice capture license. Can you follow this guide? https://github.com/tedsalmon/BlueBus/wiki/Clear-Voice-Capture

As per your RPM depends high frequency A/C voltage whine, that sounds like you'll need a ground loop isolator to overcome it. Can you shoot me an email about this? support@bluebus.dev

Thanks!
-Ted

hribecek, 2021-09-24:
Hello Ted.

thank you for your reply. I downloaded the CVC Tool and I will try it in the evening.

OK, I will write you an email in a moment.

Tomas

hribecek, 2021-09-24:
Hello Ted,

Just to let you know, the CVC tool helped, handsfree is now working! Thanks

Tomas

Closed 2021-11-14.

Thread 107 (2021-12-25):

E83 X3 - Conflict with factory(?) satellite radio

ryannoblett, 2021-12-25:
I have a 2007 X3 3.0si with factory(?) satellite radio (2006 build date). I installed the bluebus and disconnected the TCU, but I'm unable to locate a satellite radio module - it's not in the trunk area where I expected it. The bluebus sort of works, I can receive phone calls, and if I mess with the buttons for a bit, I can get into the menu (with glitches), but can't play music and only hear the satellite radio demo channel. Also, the comfort blinkers don't work, etc.

My assumption is that I need to remove or disable the satellite radio somehow. Is this correct?

If so, does anyone know where the satellite radio module is on this model? I've been unsuccessful in locating it. It's not in the driver side trunk area with the TCU and navigation DVD drive like it is on most other models. I also checked under the cargo floor area.

Thanks for your assistance.

tedsalmon, 2021-12-25:
@ryannoblett

Can you describe the menu "glitches"? This vehicle is equipped with Navigation, correct?

>My assumption is that I need to remove or disable the satellite radio somehow. Is this correct?
Not entirely. You can if you don't want it, or you could use the slave cable: https://www.ecstuning.com/b-genuine-bmw-parts/sirius-slave-cable/84110150526/?

Of course, you'd have to find the Sirius module first. I do believe it should be in the rear driver side electronics bay, along with the Navi and other modules.

Did you install the BlueBus in that area as well? Any pictures of how it's installed? Typically these cars had the CD Changer installed in the center console, which is why I'm asking.

It may also be easier to reach me by email: support@bluebus.dev

-Ted

ryannoblett, 2021-12-28:
Yes, it's got navigation. When I say glitches, sometimes the text in the bluebus menus get overwritten by other text I assume is from the satellite radio module. I wasn't able to capture that well, so I hope the description is good enough.

I did install the bluebus in the driver's side trunk area with the navigation drive and TCU. I'm attaching some pictures, and I'll link to a video trying to use the bluebus, but hearing the satellite radio instead.

Video: https://pics.deadface.org/phone/x3/bluebus/VID_20211227_194148.mp4

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

Thanks again for your help.

E39NLA, 2023-03-24:
Following this thread as I also have an E38 X3.

I think you may have the Bluebus connected wrong. According to TIS, an X3 with Sat, Nav, and DSP should use the 6-pin CD-SDARS connector. As Ted mentioned, the CD changer on these cars lived in the center console box, not the rear equipment compartment. You might find that connector there. See attached.
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

ryannoblett, 2023-03-24:
Thanks for sharing this info, turns out it's exactly what I needed. I pulled the tray out of my center console to find both an aftermarket Sirius satellite module and a Dice Mediabridge!
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
I'll get this stuff out and see what it takes to get the bluebus going.

ryannoblett, 2023-03-24:
So, partial success - the bluebus plays music perfectly when plugged into the CD changer connectors in the center console.
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
However, there is no way to connect it to the TCU adapter plug, which is in the trunk area. I think I will have to make an extension cable and run it back there to get Bluetooth calls working again. Unfortunately, even with the Sirius and dice Mediabridge disconnected, it still does not work correctly using the connectors I'm the trunk area.

ryannoblett, 2023-03-25:
Thanks Ted, switching that cable made it work in the rear and now it's fully functional.

Closed 2023-03-25.

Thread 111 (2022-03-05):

BlueBus Not Working, Undetectable by Computer

OneSwellFoop1, 2022-03-05:
I didn't drive my M3 for a couple of months as it's a weekend/summer vehicle and it was cold.  I experienced battery drain (possibly attributable to the BlueBus, but it's a 17 year old German car, so who knows) and had to remove the battery and charge it.  Upon reinstallation of the battery, my BlueBus did not work.

I attempted to connect it to my computer and neither of my computers will detect it as a USB device, despite trying two different machines and multiple USB cables.  Power light on the unit comes on.  It got quite cold in the trunk of my car during the winter, but never below mid 20's F, and there was no water intrusion or other environmental thing that might affect it.  Device was room temperature and had been for hours when I tried to connect it to a computer via USB.

tedsalmon, 2022-03-05:
Hello,

For what it’s worth, email is a better support medium for hardware issues :)

If the power light is coming on, then the unit isn’t dead. It’s likely you’re missing the drivers — can you see: https://github.com/tedsalmon/BlueBus/wiki/Accessing-the-Terminal#troubleshooting

When you plug it into the car, does the green light come on?

Did you try unplugging it and plugging it back in before fully removing it?

-Ted

tedsalmon, 2022-10-08:
Closing this due to lack of response. If it's still an issue, shoot me an email -- support@bluebus.dev

Closed 2022-10-08.

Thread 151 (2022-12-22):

Question: Best way to sniff the canbus? And contribute?

Quattro20v, 2022-12-22:
Hello, apologies if posting in the wrong spot. What is the best/easiest way to sniff the canbus? I found this article https://www.instructables.com/CAN-Bus-Sniffing-and-Broadcasting-with-Arduino/ is this the best way, or is there a better way? Would INPA be of any help?

Essentially I am new to programming with cars and would like to start off with implementing some features. For example the fog lights to turn on when I come back home at night and open the door. I've tried digging online for information on what binary value would trigger fog lights when given to LCM but did not find any documentation. So my only guess is to extract it by sniffing.

Is there anything I should be concerned in breaking on the car?

I assume the best way to develop is to just write code, compile and plug into the car to test, rinse and repeat?

Also any useful resources would be helpful, if available.

piersholt, 2022-12-23:
BlueBus does not connect to, or interface with CAN bus. BMWs of this era have multiple buses, all of which serve different purposes. BlueBus deals exclusively with the K-Bus and I-Bus (which compared to CAN, are significantly simpler.)

**Body [Karosserie] Bus (K-Bus)**
> K-Bus was added to the E38 along with the I-Bus. Models without Navigation or IKE will use the K-Bus only. Both of these bus systems are technically identical, the only difference is their use by model.

**Instrument Bus (I-Bus)**
> I-Bus was introduced on the E31 as the information bus. The E31 version of the I-Bus was used for body electronics and driver information systems. With the introduction of the E38, the I-Bus is now referred to as the instrument bus.

Based on your question, it sounds like this is a burgeoning curiosity? If that's the case, I think this project is likely to overwhelm you, and as such, probably not the best place to start.

I'd recommend starting with getting diagnostics up and running. INPA is a good place to start. I'd recommend the BMW forums to learn more about this, as it'd been covered at length.

Following that, I'd then look at [NavCoder](http://www.navcoder.com/), which will allow you to monitor bus traffic, and communicate with the modules via a UI.

Quattro20v, 2022-12-23:
Thank you for explaining this more. I think I was getting lost in all of the systems, from trying to learn online. It's a bit overwhelming learning a new subject from scratch.

I do have INPA set up, so looks like the NavCoder is the next step. I really appreciate you pointing me in the right direction, from reading about it, it looks like exactly what I was missing to be able to learn more I-bus and how all the systems work.

I do have a few years of software development experience, just nothing involving cars. I am eager to learn though, just need to put all the right pieces together to get a base (Which I think NavCoder will help immensely with!). Thanks again!

sleuth255, 2022-12-23:
You'll also need an I-Bus interface to go with NavCoder.  The software includes an electronic schematic for one that you could construct if you're handy with a soldering iron and have components laying around,  or you can purchase a usb adaptor from the author's company in Germany for ~$60.  I actually went this route myself and now have it permanently wired into my trunk.  It's 25 euros to fully unlock NavCoder and it can take a while to get your activation code back since the author doesn't check his requests very often.  The listed email addresses are also out of date.  HIs current email is jbsiegenthaler@gmail.com so you could ping him there if he doesn't see your activation request.

piersholt, 2022-12-24:
@Quattro20v Happy to help 😄

I'd also recommend searching for the following BMW documents. A few exact keyword searches should yield results on Google 😉

They'll give you an overview of the various bus systems- their purpose, how they function, how they interconnect etc. The first is more pertinent to the generation of vehicles that BlueBus applies to, but you may still like to read the second.

**1. Introduction to Bus Systems**
> 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

**2. Bus systems**
> 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

piersholt, 2022-12-24:
@Quattro20v ah! Yes @sleuth255 is quite right. A plug and play interface for I/K-Bus will be useful. However, you can still try NavCoder with your diagnostic interface. Also, unless it's since changed, you should be able to try NavCoder without a licence, it will just lack some features.

Quattro20v, 2022-12-24:
@sleuth255 Thanks, I'll order the interface so I can play around with it! From looking at it, it looks like it comes with a connector that then has ~4 wires. Is there a plug and play wire/connector option to purchase on top of that, to hook in instead of cd changer? I'd rather not do any splicing if I don't have to. Or what is the best route that you would recommend? I checked the installation documentation for the interface, but couldn't decide what the best option is for the purposes of connecting the car to a laptop

@piersholt Thanks I appreciate the resource drop, can't wait to absorb all this knowledge! 😄 It's pretty fascinating how all this works, I wish I started looking into this earlier!

sleuth255, 2022-12-24:
Yup, they also sell a harness that plugs into the CD changer if you don't want to splice that USB connector into the CD changer cable itself.  Its a bit tricky to locate so here's a link:
https://shop.ibus-app.de/i-bus-app/zubehoer/adapterkabel/196/adapter-fuer-resler-modul-zum-zwischenstecken-am-cd-wechsler/wechsler-vorbereitung

As @piersholt indicates, NavCoder will work without a license but stuff like LCM coding won't be active.

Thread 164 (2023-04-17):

Bluebus not switching off

dertimaushh, 2023-04-17:
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

Hi Ted,

I think I've found the root cause for my battery drainage. Bluebus isn't turning off.

Everything works fine expect the fact it will not switch off.

Tried FW 1.30 and 1.32 now.

Any thoughts?

Best regards,
Tim

tedsalmon, 2023-04-17:
@dertimaushh ,

Are you sure? With the keys out of the ignition and the doors closed, the LED on the BlueBus should go out within three to five minutes.

-Ted

dertimaushh, 2023-04-17:
Yes, after some days of quiescent current measurement - I can confirm it's never turning off.

tedsalmon, 2023-04-17:
@dertimaushh

But is the LED going out? How much current is it pulling?

have you tried running the restore command? Auto off is controlled by a configuration byte.

-Ted

dertimaushh, 2023-04-17:
~ 0,02-0,03A

Havn't tried any commands yet.

dertimaushh, 2023-04-17:
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

Now let's wait.

dertimaushh, 2023-04-17:
Success - restore solved the issue :-)

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

ShonkyCH, 2023-04-17:
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
If that's the total current measured (which it looks to be with the negative disconnected ie not the BlueBus alone) with the car asleep 20mA-30mA is well within spec (<40mA). For reference mine sits at about 19-20mA (with a sleeping BlueBus)

Seems like you've fixed a problem still.

Closed 2023-04-17.

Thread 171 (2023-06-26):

E39 - Can't Switch Audio Mode to Bluetooth

SmoglessPrune, 2023-06-26:
Hello,

I received my BlueBus a few weeks ago and I'm having issues getting it working with my '02 E39 M5. The car is wired for a CD changer but does not have one installed; it looks like the CD changer was forcefully removed by a previous owner because the connector on the 3 pin power was ripped off and I had to put a new end on it. My car does not have a phone so I only have the 3 pin power and 6 pin analog DSP cables connected to the BlueBus. The blue LED lights up and the radio works as normal, but when I hit the mode button I only get radio or tape, it wont switch the input to bluetooth. I tried updating firmware on the BlueBus and that was successful but the issue didn't change. Something seems to be stopping the BlueBus from communicating with the car, but I don't know if the issue is in the BlueBus, my radio, or the wiring from whatever happened to the original CD changer. Any troubleshooting advice would be much appreciated.

tedsalmon, 2023-06-26:
@SmoglessPrune,

Is the light on the unit on constantly when the ignition is on? A good test is to leave the ignition on and then check if the light is still on after 120 seconds.

P.S. Email is better for these types of support requests :smile:

-Ted

SmoglessPrune, 2023-06-26:
Thanks for the tip, I will send an email next time.

Yes, the light is on constantly with the ignition on. I left the ignition
on for 120 seconds and the light was still on solid

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

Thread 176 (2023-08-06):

Battery Drain after Bluetooth Call

jwreford, 2023-08-06:
Over the last six months or so I've experienced a few dead battery situations that seemed to have occurred since plugging in the BlueBus (replacing an Intravee). I can't say with 100% certainty yet but it seems like in some situations, after making a Bluetooth call, the BlueBus doesn't power down or is otherwise keeping the iBus active and other devices awake.  Yesterday at around midday I had received a call in the car, and today, around 5PM, my alarm went off because the battery was flat.

I'll try to reproduce the issue and use Navcoder and capture traffic. Are there any logs that I can pull off the BlueBus?

Version: 1.3.2

dertimaushh, 2023-08-06:
Try to restore the device. I had the same issue. Now all works fine.

BR,
Tim

tedsalmon, 2023-08-06:
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

That’s a decent enough edge case that I could see it causing a problem. I will double check that TEL MUTE and TEL On both get driven back to high and low respectively after ignition off.

-Ted

tedsalmon, 2023-08-06:
https://github.com/tedsalmon/BlueBus/blob/master/firmware/application/handler/handler_ibus.c#L685

So it’s definitely possible for MUTE to stay active with the ignition off given the right conditions, so I’ll just stuff another line to ensure mute is also low once the ignition off message is processed.

-Ted

jwreford, 2023-08-08:
Thank you kindly. I'll test and report back!

jwreford, 2023-08-09:
Sorry for the silly question, but the line you referenced, it's not the extra line you were going to add in is it?
Not at all trying to rush you, I'll just keep my eyes on it for when you do add it, and test then.

tedsalmon, 2023-08-09:
@jwreford - No — it would be:

`UtilsSetPinMode(UTILS_PIN_TEL_MUTE, 0);`

I’m on vacation, so it’ll be a week or so before I can add this

jwreford, 2023-08-10:
Oh! No worries, enjoy your break!
I'll have a go at building it locally and testing. Cheers!

mbt28, 2023-09-08:
I had the same issue recently, do you plan to release a new version?

tedsalmon, 2023-10-13:
Here you guys go -- try this: https://t3ddftw.s3.us-east-2.amazonaws.com/BlueBus/firmware/bluebus_1_3_3_rc27.hex

jwreford, 2023-10-28:
Thank you!! Testing now, will report back.

maarten-v, 2024-01-16:
@jwreford Did you test it? I'm still searching for a mystery problem on my car with battery drains, this could have something to do with it.

jwreford, 2024-01-16:
Sorry for the late reply. I thought I was experiencing the same issue after flashing however I think my DB connector was not fully plugged in because I reseated, resolving ann unrelated issue with the mic. That makes me think at some point during testing I loosened it.

I watched the BB logs over USB and made a few test calls, and it seemed to go to sleep correctly afterwards. I put a clamp meter over the main positive battery cable and watched the consumption drop below the sensitivity it could measure after 14 minutes (when the car goes to sleep). When I have some time I’ll also watch the ibus with navcoder to see if it goes quiet. Will report back.
But no dead battery so far.

maarten-v, 2024-01-16:
So you think a loose DB connector could have caused the drain?
What's the DB connector? Is that one of the connectors on the Bluebus?

jwreford, 2024-01-16:
The DB25 connector is the old-style phone module connector in my boot. Other cars might have that or the 54 pin. I don’t know for sure if that was the cause of my drain problem but it seems possible.
yes, BB was just me being lazy. I mean BlueBus.

Does your car go to sleep after 14 minutes (if you have an e39 or e46 at least)? One way to tell is take the key out and wait to see if the orange indicator next to the gear shifter (in the auto) goes out. If it doesn’t maybe something is keeping it awake. It might also be useful to try and watch the BlueBus logs to see what is happening.

maarten-v, 2024-01-16:
Ah ok thanks! Yes it's an E46, but it's very random. Sometimes I can leave the car for a week and it starts, next time i drive the car for an hour and the next day it's completely empty.
I'm pretty sure now with testing that if I unplug fuse 41 (for the radio, navigation, screen) I don't have a problem.
I'll try to keep an eye on the orange indicator, if I have one on the SMG.
And also pinpoint if it has anything to do with the Bluebus.

maarten-v, 2024-01-31:
My battery just randomly drained again while I had the Bluebus disconnected, so Bluebus is not to blame in my case.

jwreford, 2024-02-01:
Hey @tedsalmon, I've been testing for a few weeks and no drain issues so I think this is solved!

jwreford, 2024-03-04:
Hey again again @tedsalmon! Sorry for all the messages. The alarm went off today which happens when the battery drains low enough. I connected a jumpstarter to the battery to unlock the doors using the key to deactivate the alarm, and then disconnected the jumpstarter.

The Bluebus blue light was on, and so was the Nav. The video module was warm also so I'm guessing something was keeping the bus awake and everything powered on, which I measured previously draws about 4 amps.
I connected via USB and grabbed some logs (without rebooting) and saw messages like this, a few a second:

`[90519873] DEBUG: IBus: RX[17]: 68 0F 3B 21 62 01 40 69 76 65 72 73 61 72 79 20 6F [SELF]
[90519890] DEBUG: IBus: RX[8]: 68 06 3B A5 62 01 00 93 [SELF]
[90520372] DEBUG: IBus: RX[17]: 68 0F 3B 21 62 01 40 76 65 72 73 61 72 79 20 45 43 [SELF]
[90520389] DEBUG: IBus: RX[8]: 68 06 3B A5 62 01 00 93 [SELF]
[90520873] DEBUG: IBus: RX[17]: 68 0F 3B 21 62 01 40 65 72 73 61 72 79 20 45 64 51 [SELF]
[90520890] DEBUG: IBus: RX[8]: 68 06 3B A5 62 01 00 93 [SELF]
[90521372] DEBUG: IBus: RX[17]: 68 0F 3B 21 62 01 40 72 73 61 72 79 20 45 64 69 5D [SELF]
[90521389] DEBUG: IBus: RX[8]: 68 06 3B A5 62 01 00 93 [SELF]
[90521872] DEBUG: IBus: RX[17]: 68 0F 3B 21 62 01 40 73 61 72 79 20 45 64 69 74 5B [SELF]
[90521889] DEBUG: IBus: RX[8]: 68 06 3B A5 62 01 00 93 [SELF]
[90522373] DEBUG: IBus: RX[17]: 68 0F 3B 21 62 01 40 61 72 79 20 45 64 69 74 69 41 [SELF]
[90522390] DEBUG: IBus: RX[8]: 68 06 3B A5 62 01 00 93 [SELF]
[90522873] DEBUG: IBus: RX[17]: 68 0F 3B 21 62 01 40 72 79 20 45 64 69 74 69 6F 4F [SELF]
[90522890] DEBUG: IBus: RX[8]: 68 06 3B A5 62 01 00 93 [SELF]
[90523372] DEBUG: IBus: RX[17]: 68 0F 3B 21 62 01 40 79 20 45 64 69 74 69 6F 6E 53 [SELF]
[90523389] DEBUG: IBus: RX[8]: 68 06 3B A5 62 01 00 93 [SELF]
[90524872] DEBUG: IBus: RX[17]: 68 0F 3B 21 62 01 40 54 68 65 20 4D 61 6E 27 73 31 [SELF]
[90524889] DEBUG: IBus: RX[8]: 68 06 3B A5 62 01 00 93 [SELF]
[90527872] DEBUG: IBus: RX[17]: 68 0F 3B 21 62 01 40 68 65 20 4D 61 6E 27 73 20 45 [SELF]
[90527889] DEBUG: IBus: RX[8]: 68 06 3B A5 62 01 00 93 [SELF]
[90528373] DEBUG: IBus: RX[17]: 68 0F 3B 21 62 01 40 65 20 4D 61 6E 27 73 20 54 79 [SELF]
`

They continued for a few minutes until I rebooted. Then these more normal-looking logs:

`[0] DEBUG: PCM51XX Responded to Poll
[5] DEBUG: PCM51XX VOLL Set to 0x48
[9] DEBUG: PCM51XX VOLR Set to 0x48
[13] ERROR: UART[2]: GERR FERR
[18] ERROR: UART[1]: GERR PERR
~~~~~~~~~~~~~~~~~~~~~~~~~
BlueBus Firmware: 1.3.3
Try HELP or ?
~~~~~~~~~~~~~~~~~~~~~~~~~
# [564] DEBUG: BM83: RX: AA 00 03 30 00 00 CD
[571] DEBUG: BM83: TX: AA 00 02 14 30 BA
[577] DEBUG: BM83: TX: AA 00 03 02 00 51 AA
[584] DEBUG: BM83: TX: AA 00 03 02 00 52 A9
[606] DEBUG: BM83: RX: AA 00 03 2D 05 01 CA
[612] DEBUG: BM83: TX: AA 00 02 14 2D BD
[619] DEBUG: BM83: RX: AA 00 03 00 02 00 FB
[625] DEBUG: BM83: RX: AA 00 03 01 02 00 FA
[632] DEBUG: BM83: TX: AA 00 02 14 01 E9
[638] DEBUG: BT: Power On
[643] DEBUG: BM83: TX: AA 00 01 0E F1
[649] DEBUG: BM83: RX: AA 00 03 01 0F 00 ED
[656] DEBUG: BM83: TX: AA 00 02 14 01 E9
[662] DEBUG: BT: Standby On
[668] DEBUG: BM83: RX: AA 00 03 00 0E 00 EF
[674] DEBUG: BM83: RX: AA 00 10 1F 02 02 DB 49 E7 5B A2 90 01 A3 63 6B 7D C1 C4 C1
[684] DEBUG: BM83: TX: AA 00 02 14 1F CB
[692] DEBUG: Add PD: 1
[699] DEBUG: Handler: Not connecting to new device 0 1 0
[707] DEBUG: BT: Rewrite Pairing Profile
[714] DEBUG: Add PD: 0
[722] DEBUG: Handler: Not connecting to new device 0 1 0
[730] DEBUG: BT: Rewrite Pairing Profile
[739] DEBUG: Handler: Not connecting to new device 0 1 0
[747] DEBUG: IBus: RX[17]: 68 0F 3B A5 62 01 06 4E 6F 20 44 65 76 69 63 65 A5 [SELF]
[765] DEBUG: IBus: RX[5]: 68 03 80 01 EA [SELF]
[1014] DEBUG: IBus: RX[5]: 68 03 3B 01 51 [SELF]
[1025] DEBUG: IBus: RX[6]: 3B 04 68 02 40 15
[1034] INFO: GT Detected
[1264] DEBUG: IBus: RX[5]: 68 03 7F 01 15 [SELF]
[1275] DEBUG: IBus: RX[6]: 7F 04 68 02 40 51
[1284] INFO: NAV Detected
[1514] DEBUG: IBus: RX[5]: 68 03 C0 01 AA [SELF]
[1764] DEBUG: IBus: RX[5]: 68 03 ED 01 87 [SELF]
[1774] DEBUG: IBus: RX[6]: ED 04 68 02 00 83
[1782] INFO: VM Detected
[2014] DEBUG: IBus: RX[5]: 18 03 68 01 72 [SELF]
[2264] DEBUG: IBus: RX[5]: 80 03 D0 01 52 [SELF]
[2515] DEBUG: IBus: RX[6]: C8 04 FF 02 39 08 [SELF]
[2764] DEBUG: IBus: RX[5]: 18 03 80 10 8B [SELF]
`
Although maybe at this point the battery was so low that the nav wasn't able to start correctly and kept itself awake.

Looking at the set of logs pre-reboot with Navcoder they seem to be from RAD -> GT continuously scrolling the song title that was playing before I last turned the car off. I'm guessing this is Bluebus pretending to be the radio, sending them to the board nav's graphics driver to then display on the monitor.

Anyway, after rebooting the BB via the serial console, but not doing anything else, the song scrolling messages stopped.
Stating the obvious, but the ignition was off/key wasn't inserted, and had been since the day before.

The next time the issue happens, is there a command I can run to see what state it thinks the car is in (ignition, doors, etc)?

Hopefully that helps!
Josh.

tedsalmon, 2024-03-06:
@jwreford,

I'm sure it's not easy, but is there a chance you could grab a log while the ignition is on and then immediately after you turn it off? I'm wondering if perhaps your radio isn't sending the CD Changer "stop playing" message...

-Ted

jwreford, 2024-03-07:
Sure, no problem! Say tuned, I'll get some logs. Might take me a couple of days.

jwreford, 2024-03-07:
@tedsalmon
[iBUS-Logs-2.txt](https://github.com/tedsalmon/BlueBus/files/14522391/iBUS-Logs-2.txt)
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

Message 49072 looks like the stop message (ignore that I highlighted the wrong one in the screenshot)
I appreciate all the help you've given me so far! It's a pain troubleshooting something that only happens occasionally.

I'm going to stick a battery monitor on the battery and see if I can catch it the next time it starts dropping. Then I'll see what happens if I inject the RAD->CDC stop message myself.

dvc9mm-lgtm, 2025-08-17:
Hi all from Australia, I have been having the same issue with my E39 in regard to power draw while vehicle is switched off. I am not currently using Bluebus for telephone calls as I need to run the mic to the unit as Australian delivered E39's were not pre wired for the telephone option. I have also have to be very carefull when leaving the vehicle after turning it off as the head unit can remain on after ignition off. I checked firmware ver today which was 1.3.0 and have now updated to 1.3.4 to see if this helps at all. My main problem is my car is parked at the airport for 2 weeks at a time while I am away for work and come back to a dead battery. Bluebus was purchased in September 2022 as part of an ECS pre order from April 2022

tedsalmon, 2025-08-17:
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

Apologies for never seeing this! In this log, everything seemed to work fine -- the BlueBus works off the assumption that the radio will tell it when to stop playing (interacting), which it did at 49.207 seconds into the log. How have this fared in the past year?

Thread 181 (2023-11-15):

Whining or Ground Loop noise on calls and music

mbt28, 2023-11-15:
Hi Ted,

I have the V2 board with latest firmware. I hear the alternator noise from the speakers, I can even listen convertible servo sounds from speakers :) . This problem exists when I choose bluebus as a source, fm and others are fine.

How can I resolve this issue without attaching additional ground loop isolator? I think the board is okay but something wrong with my wiring.

Thanks

pyrophan, 2023-11-17:
Can confirm same issues with V2 on latest firmware in a 1999 e39 without DSP.

Only happens when the vehicle volume is turned up a lot. Usually turning up the Bluetooth source volume up allows use of a lower vehicle volume and avoids the issue.

tedsalmon, 2023-11-19:
@mbt28

What's the aversion to the ground loop isolator?

Typically, the root cause of this is issues with the rectifier diodes in the voltage regulator for the alternator, whence why the whine follows RPM. PWM from the throttle actuator can also introduce this noise.

In both cases, the GLI is the easiest fix :o

@pyrophan

This is pretty normal -- you're probably hearing I-Bus interference, which will sound like digital clicking noises, rather than a whine that follows RPM, right?

Thanks!
-Ted

mbt28, 2023-11-20:
Hi Ted,

But why I don't have it if I listen FM radio but only in Bluetooth mode? Even if I don't listen something I can hear the hissing noise from the speakers. I doubt I have a problem with my ground wiring. My ground is wired from chassis but there is also telephone audio input ground which is also wired to chassis on head unit stereo. Can the both ground connection from different part of the car cause the issue?

Regards,
Mehmet

StefPedro, 2023-11-24:
Hi, i have the same issue on my 1999 523i. I've had the issue on my Business CD (CD43) made by Blaupunkt, but have retrofitted original navigation with BM54 and HiFi (not DSP) and i hear clicking noises at high volumes, especially in quiet parts of songs.

tedsalmon, 2023-11-24:
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

The A/C whine is bleeding into the power input on the BlueBus, then getting piped back out the line level audio output -- this is why it doesn't exist in other audio modes. Different ground levels could cause issues, but the most likely answer is the rectifier diodes in the alternator's vreg. Can you expound on why a ground loop isolator isn't an option? It's the cheapest, easiest fix :)

tedsalmon, 2023-11-24:
> Hi, i have the same issue on my 1999 523i. I've had the issue on my Business CD (CD43) made by Blaupunkt, but have retrofitted original navigation with BM54 and HiFi (not DSP) and i hear clicking noises at high volumes, especially in quiet parts of songs.

Version 1 or Version 2 BlueBus? If you do not know, what color is the LED on the unit? Blue means it's a v2.

If it's a V1, you need to make sure that your phone volume is all the way on max while streaming.

However, what you're experiencing is normal, it just shouldn't be audible over road noise and the music itself while driving.

What you're hearing is impulsive interference from the I/K-Bus that is bleeding into the line level audio input from the CD Changer into the radio.

Thanks!
-Ted

StefPedro, 2023-11-24:
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

It is a V2. I was worried that I had something installed wrong, but if it's normal it's ok. When driving I don't hear it, only when stationary and listening loudly.

redssu, 2024-01-04:
Hey,

I also have the V2 board and I also hear the alternator whining, how can I connect a ground loop isolator to BlueBus to reduce the whining?

SecT0uch, 2024-01-29:
If anyone is interested here is how I managed to install a ground loop isolator:

I bought this model: [Europe](https://www.amazon.fr/dp/B00BBE59WS?psc=1&ref=ppx_yo2ov_dt_b_product_details)   [US](https://www.amazon.com/PAC-SNI-1-3-5-3-5-mm-Isolator/dp/B001EAQTRI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)

The case is glued together, but I managed to open it.

Do not trust the wiring color code inside, I tested with a mutimeter and here is the correct wiring:
- Yellow: Ground
- White: Right
- Red: Left

Then you can desold the wires, cut the cables of the adaper and sold them back-on the GLI.
Double check the corresponding wires with the help of this image:
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

The result should look like:
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
(Bluebus connector on the left side)

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

Manozco, 2025-08-09:
Hi guys,
Sorry to revive this (old) thread but I might need help regarding the whining issue.
I have a bluebus for a 528i E39 (1997 - EU) and it works quite well except that there is this whining noise sometimes.
I read the thread, and I bought this device on Amazon:

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

(It looks quite similar to the one shown in the previous message, except the soldering part because I have no soldering iron)

However, my issue stands with the connector on the BMW side, it looks like I have 5 cables connected in the Analog Audio part instead of 4 and I'm not sure what to do with the cable plugged on the pin 3:

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

What do you guys think of this ?

Thanks,
Manu

tedsalmon, 2025-08-09:
> What do you guys think of this ?
> Thanks, Manu

Pin 3 is a shield — I left it floating on the BlueBus, so you’re free to do the same.

Thanks!
-Ted

Manozco, 2025-08-09:
So I can just plug 1,2,4,5 and put some tape around the 3, right ?

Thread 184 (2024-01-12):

Install bootloader

leewi, 2024-01-12:
Hello,

Could somebody help me with how to install the bootloader on a just-assembled board?

Long story short, I've built a bluebus for myself :)
I've checked with USBview in windows, the device is connected and FT231X USB UART is recognized.
Tried Microchip's Unified Bootloader host app, but didn't succeed :(

I assume until the bootloader is not flashed, nothing will work, but I've run out of all my ideas on how to get it done.

Thank you in advance,
Levente

tedsalmon, 2024-01-12:
@leewi,

You need to flash it using a PICKIT and the Tag-Connect TC2030 6-pogo-pin header. You will also need to provision the BM83 Bluetooth module. https://t3ddftw.s3.us-east-2.amazonaws.com/BlueBus/BlueBus_Provisioning_1_3_2.zip

tedsalmon, 2024-01-28:
@leewi,

I believe the PIKit 3 and 4 will work fine. I do not know about the 2.

Thanks!
-Ted

pazi88, 2024-05-06:
I can confirm that PicKit2 doesn't work, even though it should work on PIC24's. PicKit3 works at least.

Chris6626, 2024-09-05:
> @leewi,
>
> You need to flash it using a PICKIT and the Tag-Connect TC2030 6-pogo-pin header. You will also need to provision the BM83 Bluetooth module. https://t3ddftw.s3.us-east-2.amazonaws.com/BlueBus/BlueBus_Provisioning_1_3_2.zip

Hi, im currently trying to set up a new BT module. How do I provision the module? Does it have to be removed and connected to the computer via UART? Or is it possible to flash it on the BlueBus while it's installed? Thanks!

Chris6626, 2024-09-06:
@tedsalmon
> You need to flash it using a PICKIT and the Tag-Connect TC2030 6-pogo-pin header. You will also need to provision the BM83 Bluetooth module. https://t3ddftw.s3.us-east-2.amazonaws.com/BlueBus/BlueBus_Provisioning_1_3_2.zip

Hi, im trying to provision my BT module, but always end up getting the Error "Failed to execute Script console_firmware_tool".

Heres what i did

-flashed bootloader with pickit3
-flashed Firmware 1.3.0.hex with Firmware Tool V1.4
-unplug USB, Switch to BOOT, Plug USB in, Led blinking
-execute bt_dfu.bat --> Error

Console communication via PuTTY is ok, but BOOTLOADER command does not set mcu to boot when switch is in APP mode.

Am i missing something here?

Thank you in advance!

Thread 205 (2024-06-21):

Screen black with e46

AdonisAAA, 2024-06-21:
Hello,
I've just built a bluebus for myself
And the BootLoader （V1.3 from GitHub） and firmware V1.3 （from Bluebus website） just successfully flashing
But the display screen of the car just turned into a black screen when Bluebus plug in
I just realized that I missed the configuration of the Bluetooth module, May I ask if this is the reason why the bluebus is not working, and if so, I just downloaded the BlueBus_Provisioning_1_3_2 form here, but I'm not sure how to flashing it in to the bluebus

tedsalmon, 2024-06-21:
Check the resistance from I/K-Bus to ground -- sounds like there's a short.

The missing Bluetooth config is not the reason for this, though.

AdonisAAA, 2024-06-23:
It's 80KΩ， looks this resistance is no problem, and the power LED lights up which means at least IBUS can turn on the power

AdonisAAA, 2024-06-23:
And I just run bt_test.bat in BlueBus_Provisioning, it gives me IBUS: ERROR, Does that mean chip TH3122 has some problem？

tedsalmon, 2024-06-23:
Does your TH3122.4 have “1936” written on it?

AdonisAAA, 2024-06-23:
I have 1935 on it

tedsalmon, 2024-06-23:
> I have 1935 on it

Right, I misremembered! Thats part of a bad batch of TH3122.4s — get an ELMOS 10026B instead. Your best bet is to desolder one from the sport steering wheel multi-function control board.

AdonisAAA, 2024-06-23:
Thank you so much, let me try to get a 10026B and try it

tedsalmon, 2024-07-23:
Closing this ticket :)

Closed 2024-07-23.

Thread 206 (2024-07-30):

Audio issues during phone call

archonauto, 2024-07-30:
Hardware 2.0 (serial 3743) Firmware 1.3.4, CD53 in 2003 Z4 (E85) with Carver audio. Mic gain set to 8db.

Having a couple of issues:

1) When call mode is set to "default", no audio plays through the speakers of the car during the call. Had this same issue on firmware 1.3.3, went away when I downgraded to 1.3.0, but returned when I updated to 1.3.4.  If I set call mode "TCU" or "No Mute", the call audio plays, but there are other issues that would prevent me from using them such as no ability to control the volume of the call audio and voice quality is terrible for the other person with many clicks and noise even when the car is parked inside a garage with the engine off. Voice quality is quite clear with no clicking noises for the other person when call mode is set to "default" but then I have no audio.
> Update to this: after tearing the car apart, tracing all the telephone wiring, and testing everything, it appears the bluebus isn’t outputting anything on the tel+ and tel- lines in default mode. Multimeter shows voltage output in “TCU” and “no mute” but reads 0 in default.

2) If call volume offset is set to 14 or 15 (in "default" call mode), the offset stays applied after the call ends and the music resumes at a much louder level. and the volume knob can't turn the volume all the way to zero because the offset is still applied. Turning the radio off and back on resets this. Doesn't seem to happen if the offset is set below 14.

3) the “3” button on the radio doesn’t seem to do anything in terms of answering calls, ending calls, or activating Siri by double-pressing it

archonauto, 2024-07-31:
After a bit of inspection on my car, it’s looking like issue 1 might not actually be a bluebus problem. I’ve been checking the wiring diagrams for the car and following the harness. The bluebus connects to the car’s 54-pin connector, which in turn feeds to the 12 pin phone prep connector in the car’s harness at the bulkhead. Looks like “tel mute”, “tel on”, “tel out +” and “tel out -“ should all run from that connector to the CD53 head unit but “tel mute” is the only one that seems to actually be at the head unit. Looks like I’ll have to run wires for the other 3 (or find the missing ones bundles somewhere in the dash?) and see what happens

tedsalmon, 2024-08-29:
@archonauto,

I think we got most of this solved over email, right? I definitely need to look at issue 3 still, though.

-Ted

archonauto, 2024-08-29:
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

Thanks Ted. I’ve been meaning to follow up with you for a while now so I just replied to the email again. The important bits (issue 1) seem to be sorted out now between the firmware you sent me and a 338 microphone. Issue 2 was still there but doesn’t actually affect me since I don’t run the volume offset high enough to trigger it. So it’s really just issue 3  and the comfort blinker glitches that still remain.

chicodorosario, 2024-12-11:
I have the same issue as mentioned above with issue 1. I installed my newly acquired OEM microphone and doing test calls and it's as mentioned above in default, TCU or even in no mute.

Please advise

tedsalmon, 2024-12-11:
> I have the same issue as mentioned above with issue 1. I installed my newly acquired OEM microphone and doing test calls and it's as mentioned above in default, TCU or even in no mute.
>
> Please advise

Can you shoot me an email, please? It's *so much* easier to keep track of issues there! It makes sense that "Default" call mode doesn't work for you though, as I recall you had the DSP amplifier in your Touring.

Thanks!
-Ted

Closed 2024-12-15.

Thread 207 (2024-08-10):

Volume button now replays the song

Water224, 2024-08-10:
I want to first say this product has been amazing and has made my e46 experience much better. I recently installed a e46 bmw sport steering wheel on my base 03 325xi. After the install, I realized that the button on the steering wheel to lower the volume will now cause the song to restart. Im not sure if this is because I installed a different steering wheel so wanted to ask if this has happened/been brought up before? Here is a link to the wheel I purchased if it helps

https://www.ebay.com/itm/186432473653?itemid=186432473653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

tedsalmon, 2024-08-29:
@Water224

Sorry for the lag! At first glance, it sounds like a problem with the MFL. Could you possibly replace the multi-function button circuitry? It's pretty easy to do once you remove the upper trim -- it's about 6 small screws if I recall correctly.

Thanks!
-Ted

tedsalmon, 2025-06-10:
Closing due to age.

Closed 2025-06-10.

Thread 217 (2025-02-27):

No sound during calls (static/crackling), microphone works.

lukagobovic, 2025-02-27:
HW Version 2.0, FW 1.3.4

2000 (Prod 1999/08/30) e39 540i with NAV MKII and DSP. Audio output works fine when playing music, google maps, youtube...... But when summoning Siri or entering a call, I have no sound, only crackling and loud static. The microphone works, and I the other end is able to hear me, but I have nothing from my end.

I have the DB25 adapter (DIY), dug around and made sure there is no SES connector. I have reflashed the firmware, performed the BM83 update, done a restore command, and changed every single setting in the call menu (Gain, Offset, TCU and No Mute). I am unsure what else I can do, except for trying to see if the adapter is bad, or if something on the board itself is fried.

I have once head a brief phone ringing tone, for a split second before it went away again.

Also want to double check, do the late '99 prod models come with the blue 26 pin connector somehow? I was almost certain it was not there but....

Any help would be greatly appreciated!

lukagobovic, 2025-02-28:
UPDATE:

Self closing this issue as I found the problem, with help of Ted through emails.

Issue 1: Pin 31 and 30 of the MCU were bridged via a solder ball, which can cause problems with MCU_TEL signals. Removed solder bridge with flux and wick.

Issue 2: Capacitor C49, which is on the output line of the DAC and the input of the telephone amplifier was partially tomb stoned, leading to an open circuit on the input line and no audio signal. Resoldering the capacitor to the board fixed the issue, now have sound output in a call.

If you're having these issues, and are capable of soldering, have a look at the schematic and look for connection problems like this on the board!

Closed 2025-02-28.

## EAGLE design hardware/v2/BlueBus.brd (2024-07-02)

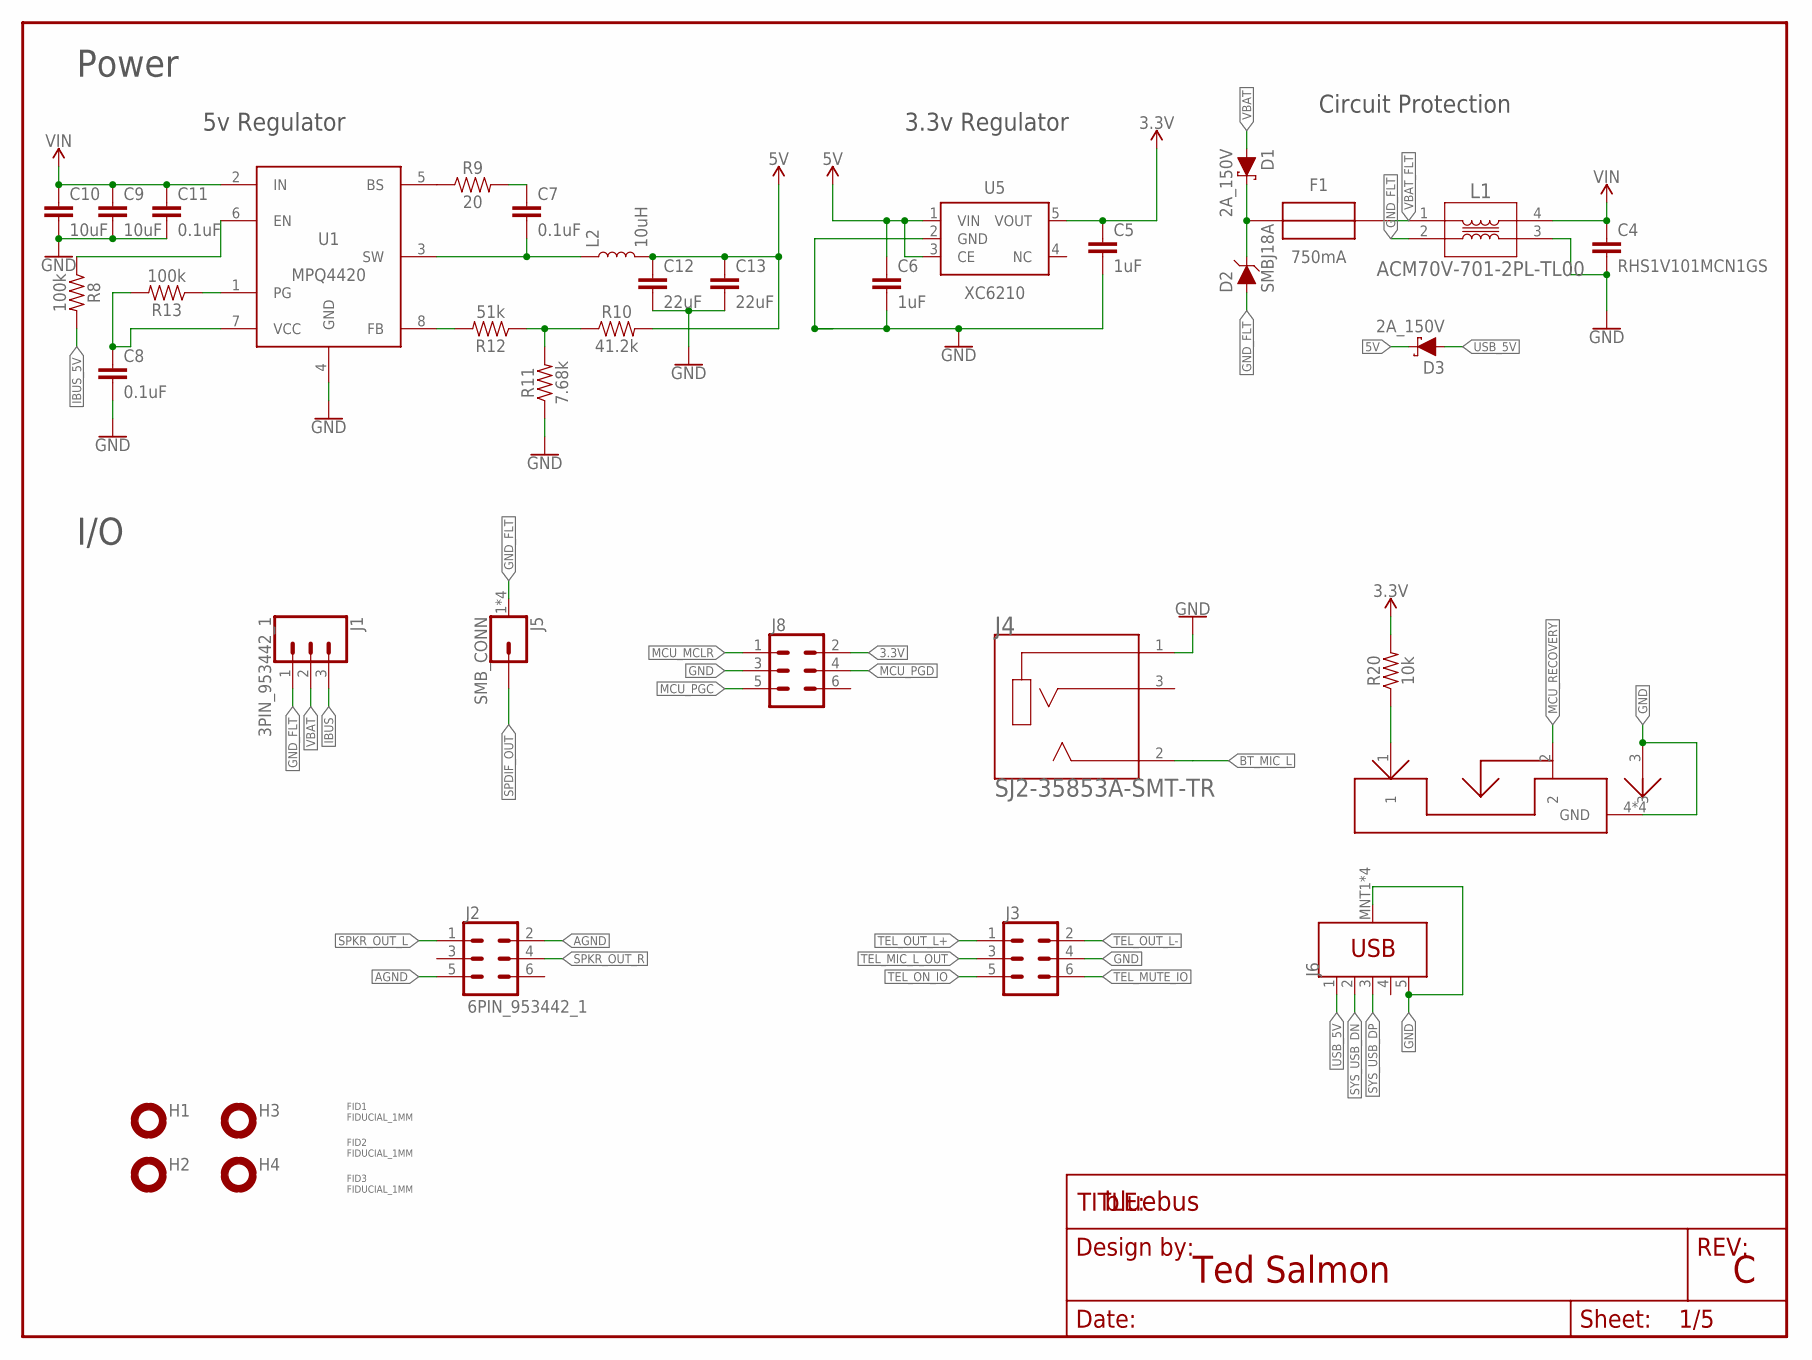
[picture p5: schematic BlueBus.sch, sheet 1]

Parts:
C4: RHS1V101MCN1GS
C5, C6: 1uF; 0603
C7, C8, C11: 0.1uF; 0603
C9, C10: 10uF; 1206
C12, C13: 22uF; 0805
D1, D3: 2A_150V; SOD123FL-2
D2: SMBJ18A; DO-214AA
F1: 750mA; LITTLEFUSE
FID1, FID2, FID3: FIDUCIAL_1MM
FRAME1: FRAME-LETTER; DUMMY
H1, H2, H3, H4: 2,5-HOLE; 2.5-HOLE
J1: 3PIN_953442_1; TE_MQS_3PIN
J2: 6PIN_953442_1; TE_MQS_6PIN
J3: 6PIN_5_103166_1; TE_AMPMODU_6_PIN
J4: SJ2-35853A-SMT-TR; CUI_SJ2_35853A_SMT_TR
J5: SMB_CONN; MOLEX_SMB
J6: USB3080-30-01-A
J7: PCM12SMTR
J8: TC2030NL; TC2030-NL
L1: ACM70V-701-2PL-TL00
L2: 10uH; MPL-SE5040
R8, R13: 100k; 0603
R9: 20; 0603
R10: 41.2k; 0603
R11: 7.68k; 0603
R12: 51k; 0603
R20: 10k; 0603
U1: MPQ4420; TSOT23-8
U5: XC6210; SOT23-5

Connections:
3.3V: C5.1, J8.2, R20.2, U5.5 (VOUT); also elsewhere on the board
5V: C6.1, C12.1, C13.1, D3.C, L2.2, R10.2, U5.1 (VIN), U5.3 (CE); also elsewhere on the board
5VREG_BS: R9.1, U1.5 (BS)
5VREG_BS_CAP: C7.1, R9.2
5VREG_EN: R8.1, U1.6 (EN)
5VREG_FB: R12.2, U1.8 (FB)
5VREG_FB_T: R10.1, R11.2, R12.1
5VREG_PG: R13.1, U1.1 (PG)
5VREG_SW: C7.2, L2.1, U1.3 (SW)
5VREG_VCC: C8.1, R13.2, U1.7 (VCC)
AGND: J2.2, J2.5; also elsewhere on the board
BT_MIC_L: J4.2 (TIP); also elsewhere on the board
GND: C4.2, C5.2, C6.2, C8.2, C9.2, C10.2, C11.2, C12.2, C13.2, J3.4, J4.1 (SLEEVE), J6.5 (GND), J6.MNT1 (SHIELD), J6.MNT2 (SHIELD), J6.MNT3 (SHIELD), J6.MNT4 (SHIELD), J7.3, J7.4 (GND), J7.5 (GND), J7.6 (GND), J7.7 (GND), J8.3, L1.3, R11.1, U1.4 (GND), U5.2 (GND); also elsewhere on the board
GND_FLT: D2.A, J1.1, J5.1 (GND), J5.2 (GND), J5.3 (GND), J5.4 (GND), L1.2
IBUS: J1.3; also elsewhere on the board
IBUS_5V: R8.2; also elsewhere on the board
MCU_MCLR: J8.1; also elsewhere on the board
MCU_PGC: J8.5; also elsewhere on the board
MCU_PGD: J8.4; also elsewhere on the board
MCU_RECOVERY: J7.2; also elsewhere on the board
RECOVERY_ON: J7.1, R20.1
SPDIF_OUT: J5.P$1 (1); also elsewhere on the board
SPKR_OUT_L: J2.1; also elsewhere on the board
SPKR_OUT_R: J2.4; also elsewhere on the board
SYS_USB_DN: J6.2 (D-); also elsewhere on the board
SYS_USB_DP: J6.3 (D+); also elsewhere on the board
TEL_MIC_L_OUT: J3.3; also elsewhere on the board
TEL_MUTE_IO: J3.6; also elsewhere on the board
TEL_ON_IO: J3.5; also elsewhere on the board
TEL_OUT_L+: J3.1; also elsewhere on the board
TEL_OUT_L-: J3.2; also elsewhere on the board
USB_5V: D3.A, J6.1 (VBUS)
VBAT: D1.A, J1.2
VBAT_DIODE: D1.C, D2.C, F1.IN (OUT)
VBAT_FLT: F1.OUT (IN), L1.1
VIN: C4.1, C9.1, C10.1, C11.1, L1.4, U1.2 (IN); also elsewhere on the board

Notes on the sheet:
Ted Salmon
Power
I/O
3.3v Regulator
5v Regulator
Circuit Protection

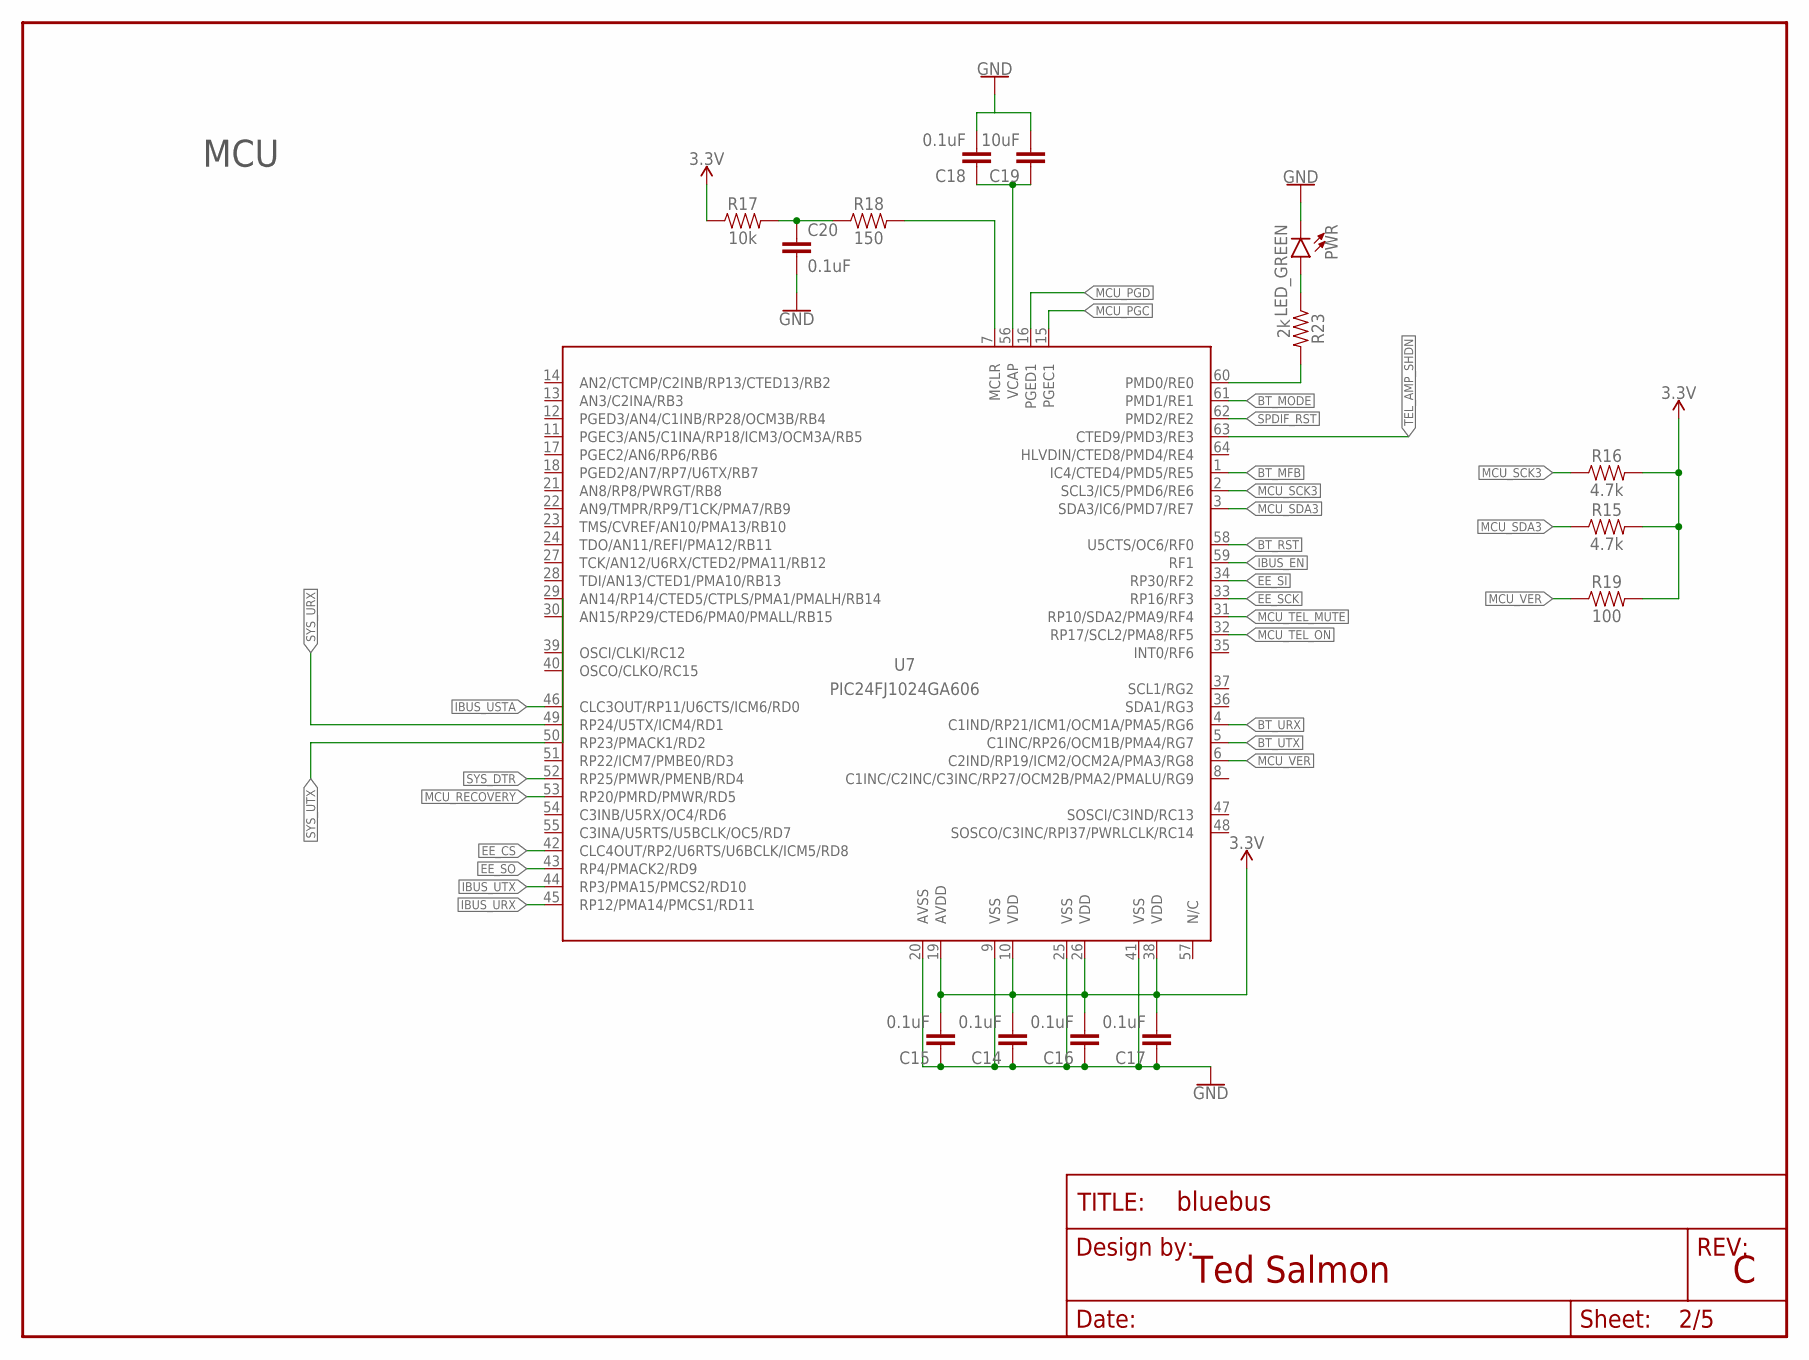
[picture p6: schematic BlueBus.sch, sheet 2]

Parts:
C14, C15, C16, C17, C18, C20: 0.1uF; 0603
C19: 10uF; 0603
FRAME2: FRAME-LETTER; DUMMY
PWR: LED_GREEN; LED-0805
R15, R16: 4.7k; 0603
R17: 10k; 0603
R18: 150; 0603
R19: 100; 0603
R23: 2k; 0603
U7: PIC24FJ1024GA606; TQFP64

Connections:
3.3V: C14.2, C15.2, C16.2, C17.2, R15.2, R16.2, R17.1, R19.2, U7.10 (VDD), U7.19 (AVDD), U7.26 (VDD), U7.38 (VDD); also elsewhere on the board
BT_MFB: U7.1 (IC4/CTED4/PMD5/RE5); also elsewhere on the board
BT_MODE: U7.61 (PMD1/RE1); also elsewhere on the board
BT_RST: U7.58 (U5CTS/OC6/RF0); also elsewhere on the board
BT_URX: U7.4 (C1IND/RP21/ICM1/OCM1A/PMA5/RG6); also elsewhere on the board
BT_UTX: U7.5 (C1INC/RP26/OCM1B/PMA4/RG7); also elsewhere on the board
EE_CS: U7.42 (CLC4OUT/RP2/U6RTS/U6BCLK/ICM5/RD8); also elsewhere on the board
EE_SCK: U7.33 (RP16/RF3); also elsewhere on the board
EE_SI: U7.34 (RP30/RF2); also elsewhere on the board
EE_SO: U7.43 (RP4/PMACK2/RD9); also elsewhere on the board
GND: C14.1, C15.1, C16.1, C17.1, C18.2, C19.2, C20.2, PWR.- (C), U7.9 (VSS), U7.20 (AVSS), U7.25 (VSS), U7.41 (VSS); also elsewhere on the board
IBUS_EN: U7.59 (RF1); also elsewhere on the board
IBUS_URX: U7.45 (RP12/PMA14/PMCS1/RD11); also elsewhere on the board
IBUS_USTA: U7.46 (CLC3OUT/RP11/U6CTS/ICM6/RD0); also elsewhere on the board
IBUS_UTX: U7.44 (RP3/PMA15/PMCS2/RD10); also elsewhere on the board
MCU_MCLR: R18.2, U7.7 (MCLR); also elsewhere on the board
MCU_MCLR_RES: C20.1, R17.2, R18.1
MCU_ON_LED: R23.2, U7.60 (PMD0/RE0)
MCU_ON_LED_RES: PWR.+ (A), R23.1
MCU_PGC: U7.15 (PGEC1); also elsewhere on the board
MCU_PGD: U7.16 (PGED1); also elsewhere on the board
MCU_RECOVERY: U7.53 (RP20/PMRD/PMWR/RD5); also elsewhere on the board
MCU_SCK3: R16.1, U7.2 (SCL3/IC5/PMD6/RE6); also elsewhere on the board
MCU_SDA3: R15.1, U7.3 (SDA3/IC6/PMD7/RE7); also elsewhere on the board
MCU_TEL_MUTE: U7.31 (RP10/SDA2/PMA9/RF4); also elsewhere on the board
MCU_TEL_ON: U7.32 (RP17/SCL2/PMA8/RF5); also elsewhere on the board
MCU_VCAP: C18.1, C19.1, U7.56 (VCAP)
MCU_VER: R19.1, U7.6 (C2IND/RP19/ICM2/OCM2A/PMA3/RG8)
SPDIF_RST: U7.62 (PMD2/RE2); also elsewhere on the board
SYS_DTR: U7.52 (RP25/PMWR/PMENB/RD4); also elsewhere on the board
SYS_URX: U7.49 (RP24/U5TX/ICM4/RD1); also elsewhere on the board
SYS_UTX: U7.50 (RP23/PMACK1/RD2); also elsewhere on the board
TEL_AMP_SHDN: U7.63 (CTED9/PMD3/RE3); also elsewhere on the board

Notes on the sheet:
Ted Salmon
MCU

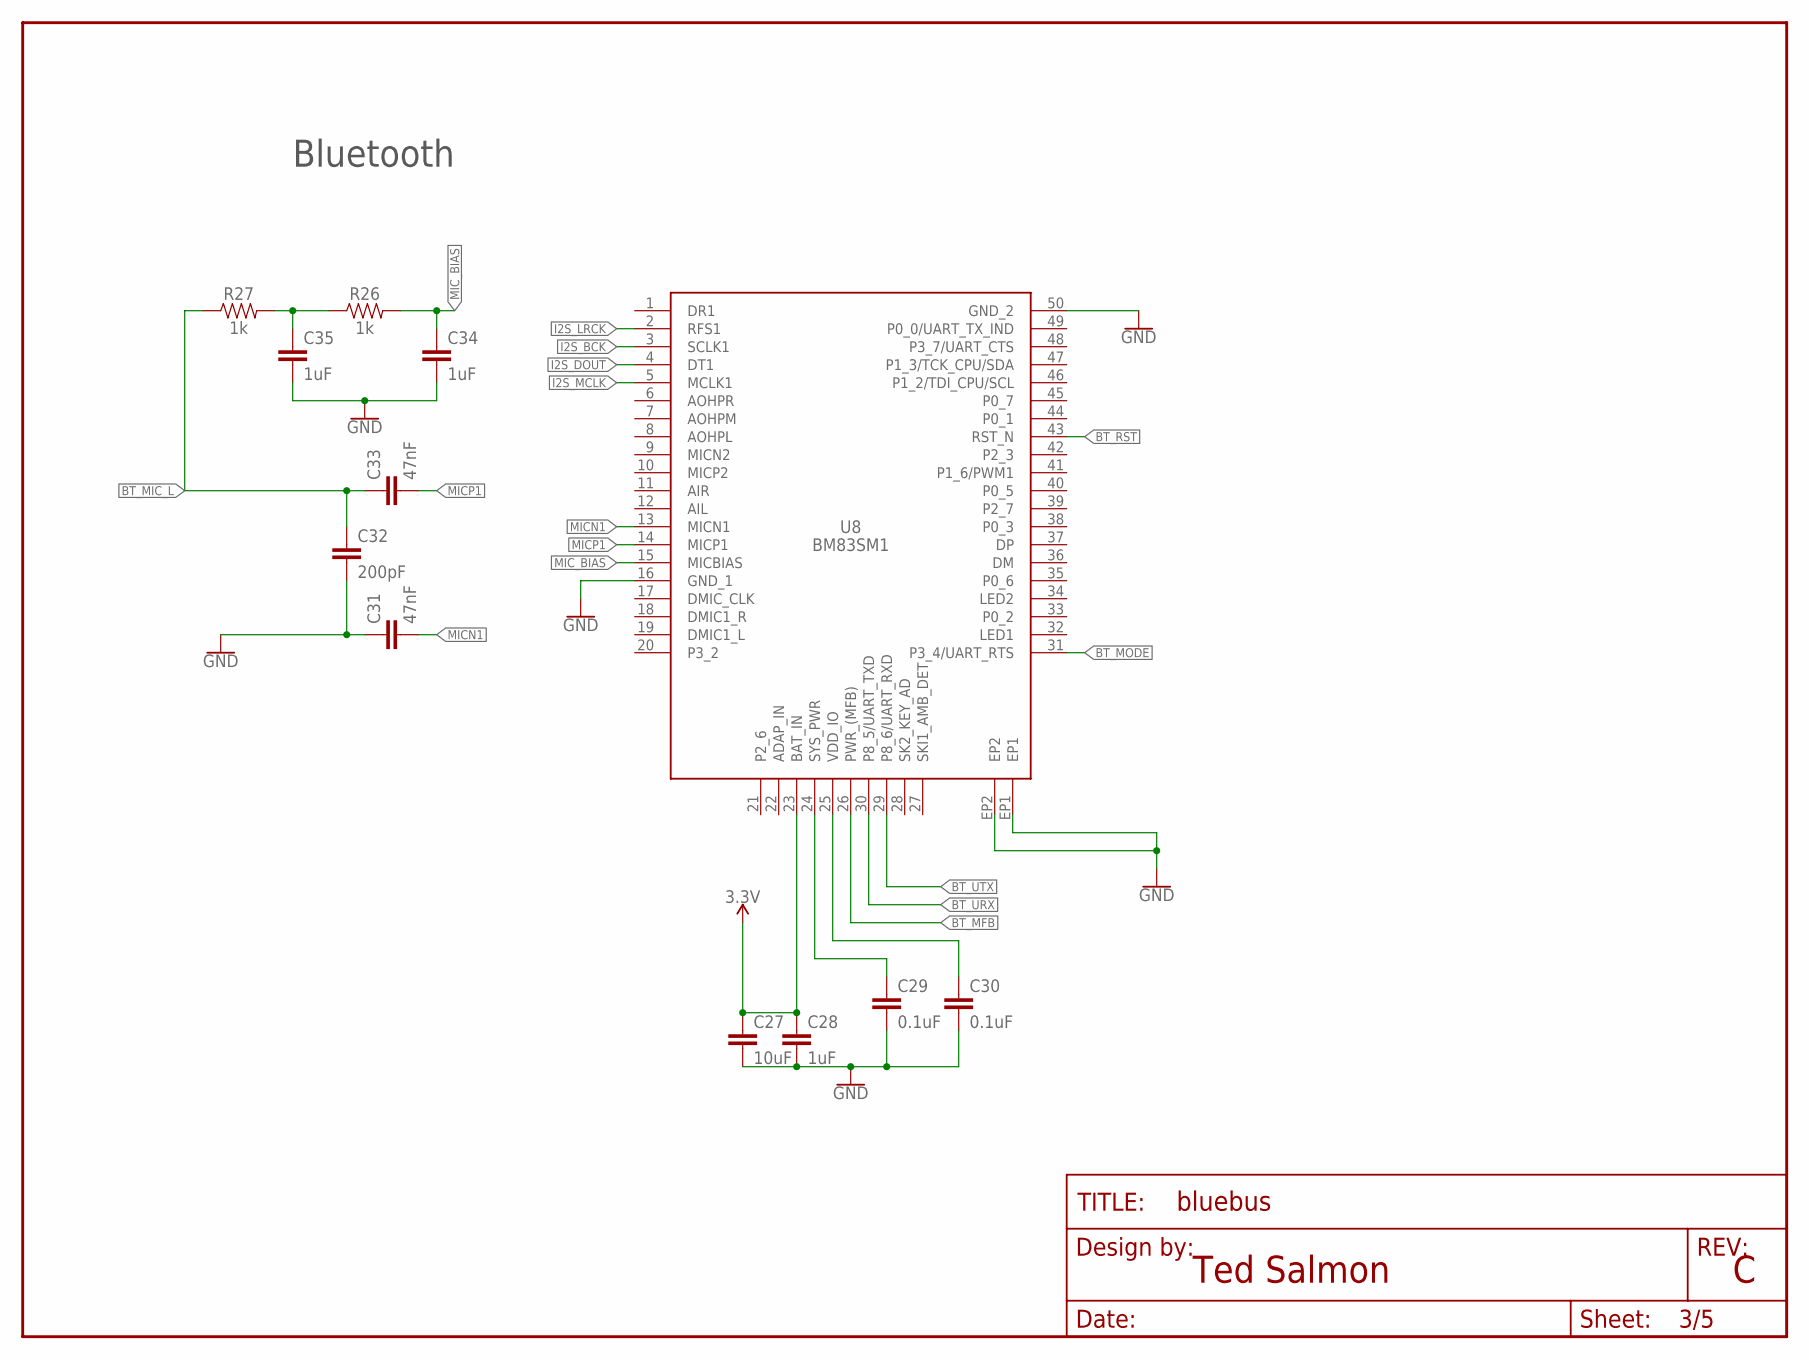
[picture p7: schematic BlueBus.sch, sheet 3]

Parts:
C27: 10uF; 0603
C28, C34, C35: 1uF; 0603
C29, C30: 0.1uF; 0603
C31, C33: 47nF; 0603
C32: 200pF; 0603
FRAME4: FRAME-LETTER; DUMMY
R26, R27: 1k; 0603
U8: BM83SM1

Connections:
3.3V: C27.1, C28.1, U8.23 (BAT_IN); also elsewhere on the board
BT_MFB: U8.26 (PWR_(MFB)); also elsewhere on the board
BT_MIC_L: C32.1, C33.1, R27.1; also elsewhere on the board
BT_MODE: U8.31 (P3_4/UART_RTS); also elsewhere on the board
BT_RST: U8.43 (RST_N); also elsewhere on the board
BT_SYS_PWR: C29.1, U8.24 (SYS_PWR)
BT_URX: U8.30 (P8_5/UART_TXD); also elsewhere on the board
BT_UTX: U8.29 (P8_6/UART_RXD); also elsewhere on the board
BT_VDD_IO: C30.1, U8.25 (VDD_IO)
GND: C27.2, C28.2, C29.2, C30.2, C31.1, C32.2, C34.2, C35.2, U8.16 (GND_1), U8.50 (GND_2), U8.EP1, U8.EP2; also elsewhere on the board
I2S_BCK: U8.3 (SCLK1); also elsewhere on the board
I2S_DOUT: U8.4 (DT1); also elsewhere on the board
I2S_LRCK: U8.2 (RFS1); also elsewhere on the board
I2S_MCLK: U8.5 (MCLK1); also elsewhere on the board
MICN1: C31.2, U8.13 (MICN1)
MICP1: C33.2, U8.14 (MICP1)
MICP1_RES: C35.1, R26.1, R27.2
MIC_BIAS: C34.1, R26.2, U8.15 (MICBIAS)

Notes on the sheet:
Bluetooth
Ted Salmon

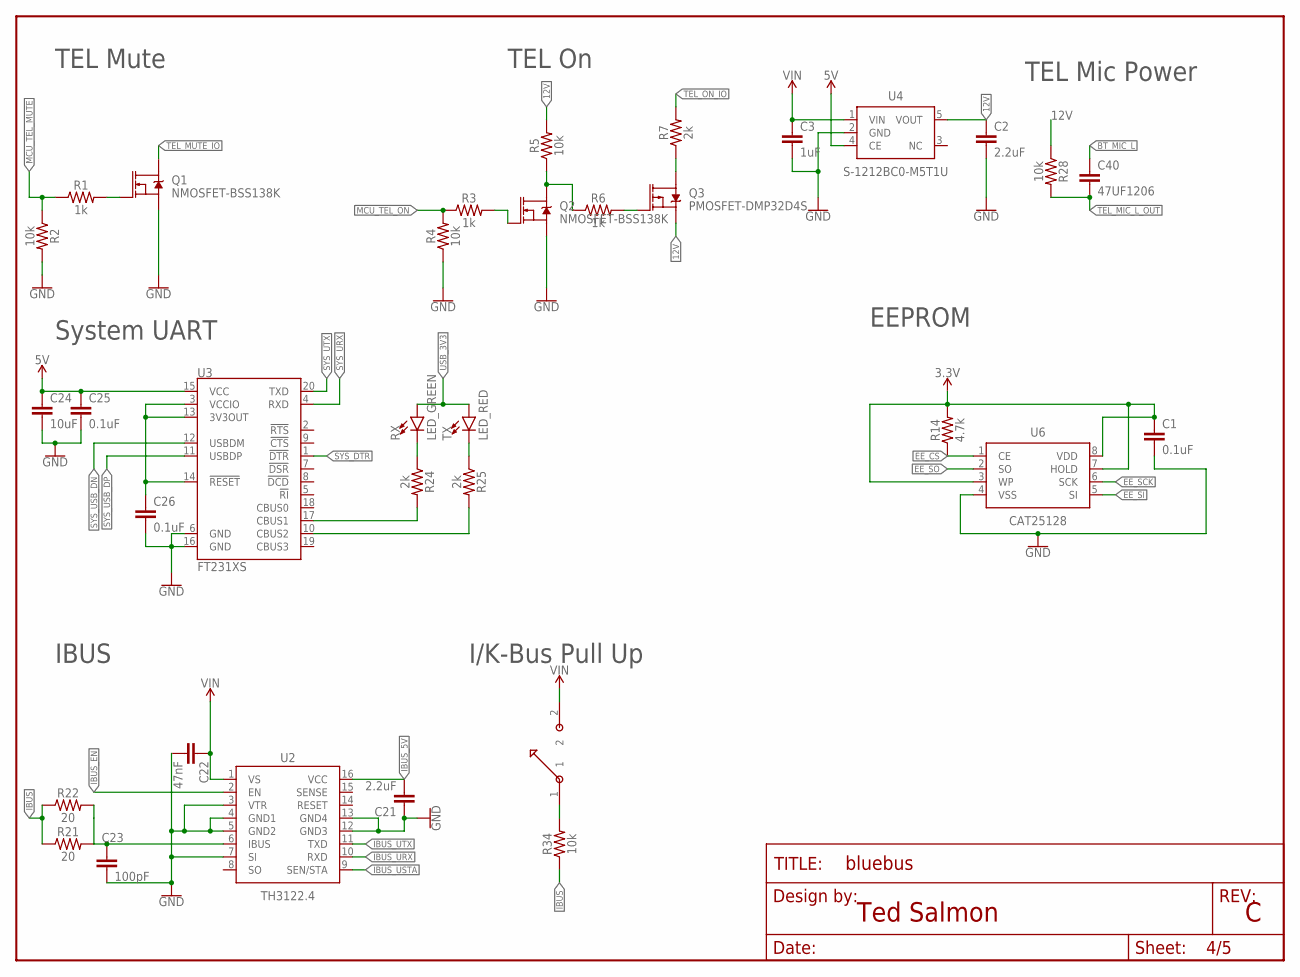
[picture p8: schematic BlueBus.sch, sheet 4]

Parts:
C1, C25, C26: 0.1uF; 0603
C2, C21: 2.2uF; 0603
C3: 1uF; 0603
C22: 47nF; 0603
C23: 100pF; 0603
C24: 10uF; 0603
C40: 47UF1206; 1206
FRAME3: FRAME-LETTER; DUMMY
Q1, Q2: NMOSFET-BSS138K; SOT-23
Q3: PMOSFET-DMP32D4S; SOT-23
R1, R3, R6: 1k; 0603
R2, R4, R5, R28, R34: 10k; 0603
R7, R24, R25: 2k; 0603
R14: 4.7k; 0603
R21, R22: 20; 0603
RX: LED_GREEN; LED-0805
SW1: CHS-01TA1
TX: LED_RED; LED-0805
U2: TH3122.4; SOIC16DF
U3: FT231XS; SSOP20_L
U4: S-1212BC0-M5T1U; SOT23-5
U6: CAT25128; TSSOP-8

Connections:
3.3V: C1.1, R14.2, U6.3 (WP), U6.7 (HOLD), U6.8 (VDD); also elsewhere on the board
5V: C24.1, C25.1, U3.15 (VCC), U4.4 (CE); also elsewhere on the board
12V: C2.1, Q3.2 (S), R5.2, R28.1, U4.5 (VOUT)
BT_MIC_L: C40.1; also elsewhere on the board
EE_CS: R14.1, U6.1 (CE); also elsewhere on the board
EE_SCK: U6.6 (SCK); also elsewhere on the board
EE_SI: U6.5 (SI); also elsewhere on the board
EE_SO: U6.2 (SO); also elsewhere on the board
GND: C1.2, C2.2, C3.2, C21.1, C22.2, C23.2, C24.2, C25.2, C26.2, Q1.2 (S), Q2.2 (S), R2.2, R4.1, U2.3 (VTR), U2.4 (GND1), U2.5 (GND2), U2.7 (SI), U2.12 (GND3), U2.13 (GND4), U3.6 (GND), U3.16 (GND), U4.2 (GND), U6.4 (VSS); also elsewhere on the board
IBUS: R21.1, R22.1, R34.1; also elsewhere on the board
IBUS_5V: C21.2, U2.16 (VCC); also elsewhere on the board
IBUS_EN: U2.2 (EN); also elsewhere on the board
IBUS_FILT: C23.1, R21.2, R22.2, U2.6 (IBUS)
IBUS_PU: R34.2, SW1.1
IBUS_URX: U2.10 (RXD); also elsewhere on the board
IBUS_USTA: U2.9 (SEN/STA); also elsewhere on the board
IBUS_UTX: U2.11 (TXD); also elsewhere on the board
MCU_TEL_MUTE: R1.1, R2.1; also elsewhere on the board
MCU_TEL_MUTE_RES: Q1.1 (G), R1.2
MCU_TEL_ON: R3.1, R4.2; also elsewhere on the board
MCU_TEL_ON_NRES: Q2.1 (G), R3.2
SYS_DTR: U3.1 (!DTR); also elsewhere on the board
SYS_RX_LED: R24.2, U3.17 (CBUS1)
SYS_RX_LED_RES: R24.1, RX.- (C)
SYS_TX_LED: R25.2, U3.10 (CBUS2)
SYS_TX_LED_RES: R25.1, TX.- (C)
SYS_URX: U3.4 (RXD); also elsewhere on the board
SYS_USB_DN: U3.12 (USBDM); also elsewhere on the board
SYS_USB_DP: U3.11 (USBDP); also elsewhere on the board
SYS_UTX: U3.20 (TXD); also elsewhere on the board
TEL_MIC_L_OUT: C40.2, R28.2; also elsewhere on the board
TEL_MUTE_IO: Q1.3 (D); also elsewhere on the board
TEL_ON: Q3.3 (D), R7.1
TEL_ON_IO: R7.2; also elsewhere on the board
TEL_ON_P: Q2.3 (D), R5.1, R6.1
TEL_ON_P_RES: Q3.1 (G), R6.2
USB_3V3: C26.1, RX.+ (A), TX.+ (A), U3.3 (VCCIO), U3.13 (3V3OUT), U3.14 (!RESET)
VIN: C3.1, C22.1, SW1.2, U2.1 (VS), U4.1 (VIN); also elsewhere on the board

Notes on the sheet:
Ted Salmon
IBUS
EEPROM
TEL On
TEL Mute
TEL Mic Power
System UART
I/K-Bus Pull Up

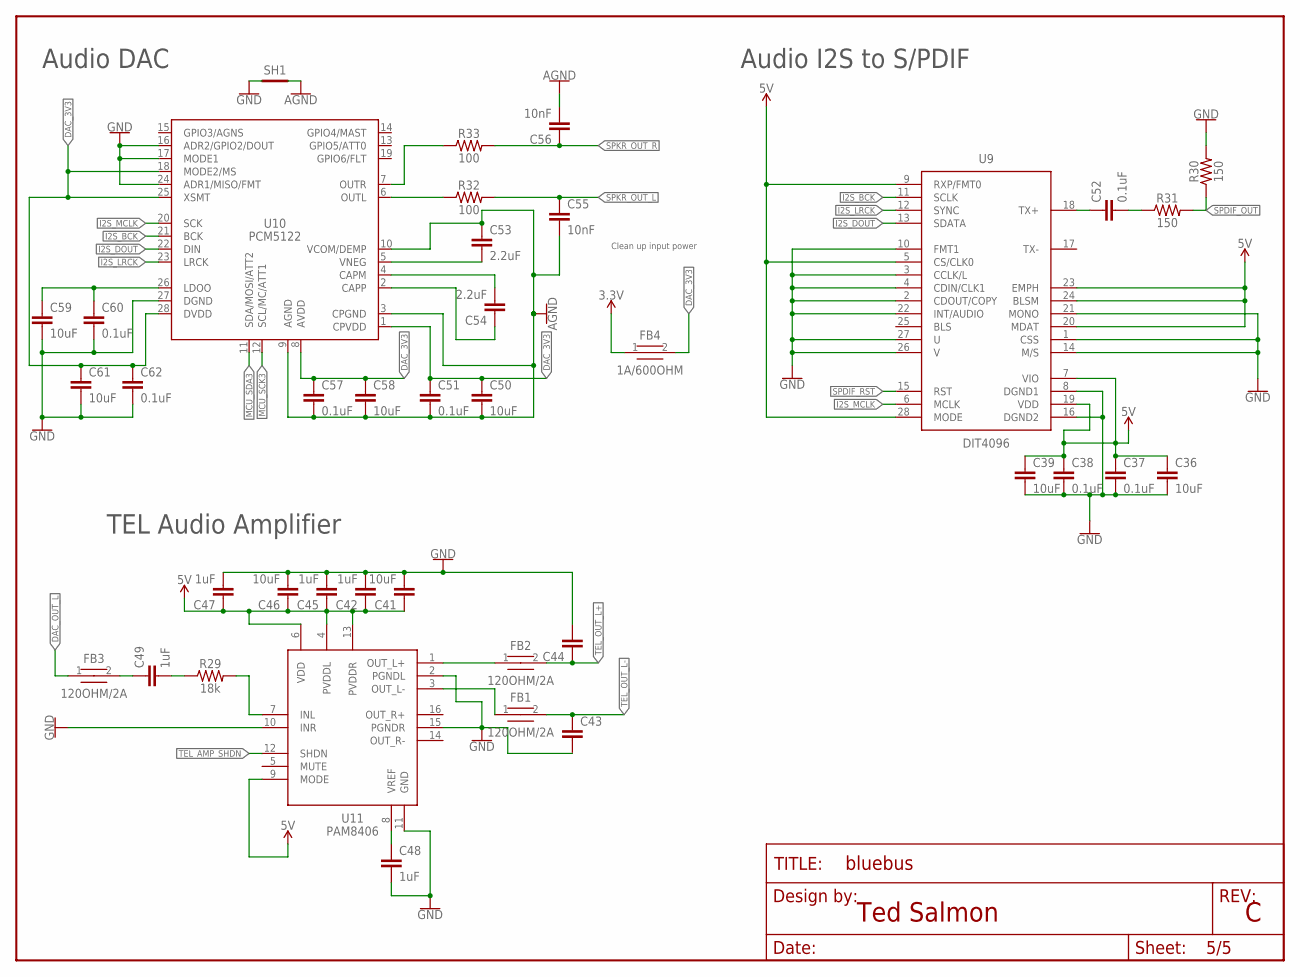
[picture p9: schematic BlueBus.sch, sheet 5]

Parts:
C36, C39, C41, C46, C50, C58, C59, C61: 10uF; 0603
C37, C38, C51, C52, C57, C60, C62: 0.1uF; 0603
C42, C45, C47, C48, C49: 1uF; 0603
C43, C44: 200pF; 0603
C53, C54: 2.2uF; 0603
C55, C56: 10nF; 0603
FB1, FB2, FB3: 120OHM/2A; 0603
FB4: 1A/600OHM; 0603
FRAME5: FRAME-LETTER; DUMMY
R29: 18k; 0603
R30, R31: 150; 0603
R32, R33: 100; 0603
SH1: SHORTT5; SHORT_TOP-50
U9: DIT4096; TSSOP28
U10: PCM5122; TSSOP28
U11: PAM8406; SOP-16

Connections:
3.3V: FB4.1; also elsewhere on the board
5V: C36.1, C37.1, C38.1, C39.1, C41.1, C42.1, C45.1, C46.1, C47.1, U9.5 (CS/CLK0), U9.7 (VIO), U9.9 (RXP/FMT0), U9.19 (VDD), U9.20 (MDAT), U9.23 (EMPH), U9.24 (BLSM), U9.28 (MODE), U11.4 (PVDDL), U11.6 (VDD), U11.9 (MODE), U11.13 (PVDDR); also elsewhere on the board
AGND: C50.2, C51.2, C53.1, C55.2, C56.2, C57.2, C58.2, SH1.2, U10.3 (CPGND), U10.9 (AGND), U10.10 (VCOM/DEMP); also elsewhere on the board
DAC_3V3: C50.1, C51.1, C57.1, C58.1, C61.1, C62.1, FB4.2, U10.1 (CPVDD), U10.8 (AVDD), U10.18 (MODE2/MS), U10.25 (XSMT), U10.28 (DVDD)
DAC_CAPM: C54.2, U10.4 (CAPM)
DAC_CAPP: C54.1, U10.2 (CAPP)
DAC_LDOO: C59.1, C60.1, U10.26 (LDOO)
DAC_OUT_L: FB3.1, R32.1, U10.6 (OUTL)
DAC_OUT_R: R33.1, U10.7 (OUTR)
DAC_VNEG: C53.2, U10.5 (VNEG)
GND: C36.2, C37.2, C38.2, C39.2, C41.2, C42.2, C43.2, C44.2, C45.2, C46.2, C47.2, C48.2, C59.2, C60.2, C61.2, C62.2, R30.2, SH1.1, U9.1 (CSS), U9.2 (CDOUT/COPY), U9.3 (CCLK/L), U9.4 (CDIN/CLK1), U9.8 (DGND1), U9.10 (FMT1), U9.14 (M/S), U9.16 (DGND2), U9.21 (MONO), U9.22 (INT/AUDIO), U9.26 (V), U9.27 (U), U10.16 (ADR2/GPIO2/DOUT), U10.17 (MODE1), U10.24 (ADR1/MISO/FMT), U10.27 (DGND), U11.2 (PGNDL), U11.10 (INR), U11.11 (GND), U11.15 (PGNDR); also elsewhere on the board
I2S_BCK: U9.11 (SCLK), U10.21 (BCK); also elsewhere on the board
I2S_DOUT: U9.13 (SDATA), U10.22 (DIN); also elsewhere on the board
I2S_LRCK: U9.12 (SYNC), U10.23 (LRCK); also elsewhere on the board
I2S_MCLK: U9.6 (MCLK), U10.20 (SCK); also elsewhere on the board
MCU_SCK3: U10.12 (SCL/MC/ATT1); also elsewhere on the board
MCU_SDA3: U10.11 (SDA/MOSI/ATT2); also elsewhere on the board
SPDIF_OUT: R30.1, R31.2; also elsewhere on the board
SPDIF_RST: U9.15 (RST); also elsewhere on the board
SPDIF_TX_FLT: C52.1, U9.18 (TX+)
SPDIF_TX_RES: C52.2, R31.1
SPKR_OUT_L: C55.1, R32.2; also elsewhere on the board
SPKR_OUT_R: C56.1, R33.2; also elsewhere on the board
TEL_AMP_IN: C49.1, FB3.2
TEL_AMP_INL: R29.2, U11.7 (INL)
TEL_AMP_INL_CAP_RES: C49.2, R29.1
TEL_AMP_OUT_L+: FB2.1, U11.1 (OUT_L+)
TEL_AMP_OUT_L-: FB1.1, U11.3 (OUT_L-)
TEL_AMP_SHDN: U11.12 (SHDN); also elsewhere on the board
TEL_AMP_VREF: C48.1, U11.8 (VREF)
TEL_OUT_L+: C44.1, FB2.2; also elsewhere on the board
TEL_OUT_L-: C43.1, FB1.2; also elsewhere on the board

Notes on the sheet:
Audio DAC
Audio I2S to S/PDIF
TEL Audio Amplifier
Ted Salmon
Clean up input power

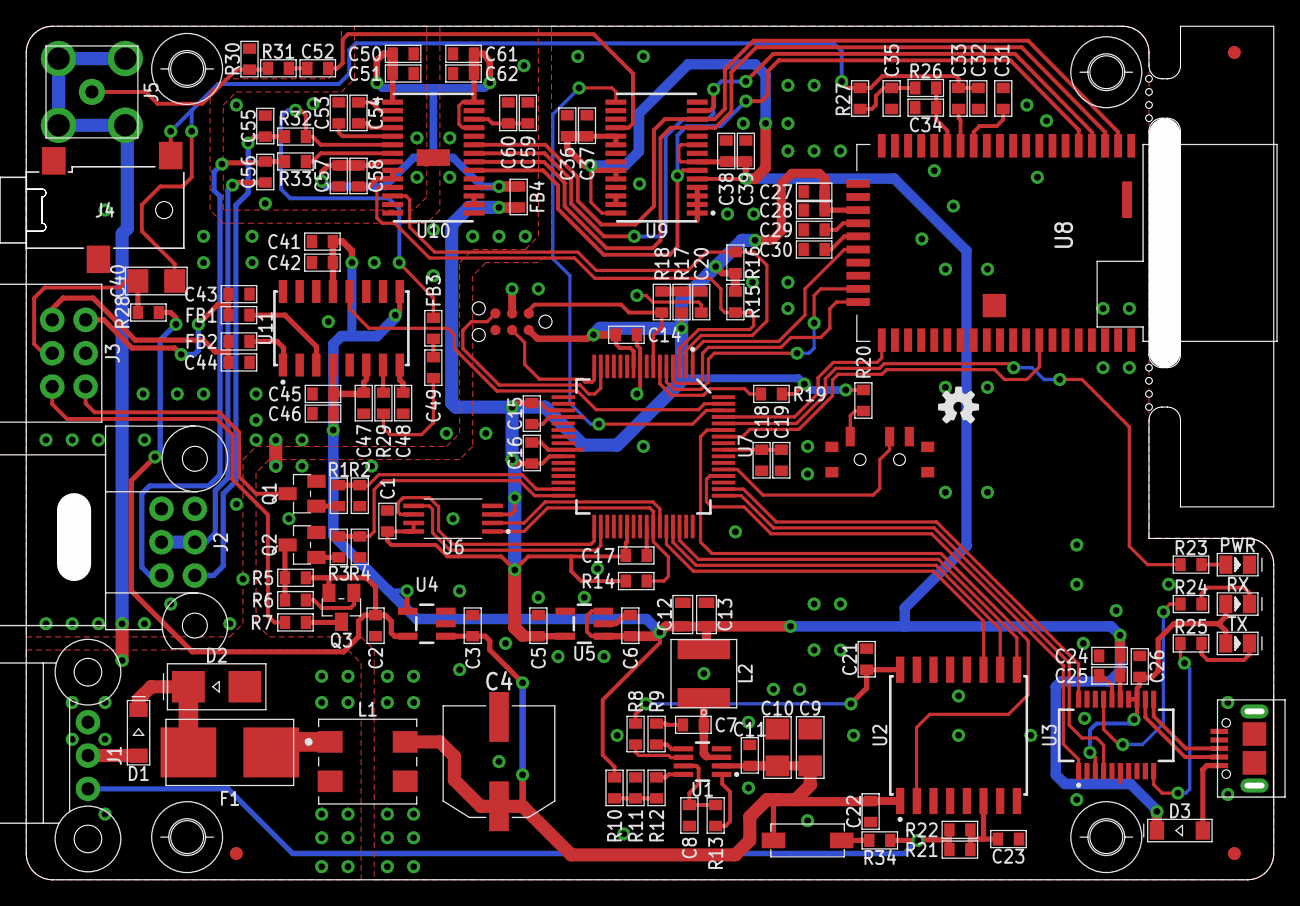
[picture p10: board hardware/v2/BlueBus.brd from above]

Board: 2 copper layers, 95.0 x 65.0 mm, 146 parts (0 on the bottom side), 101 nets.

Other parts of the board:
U$1: OSHW-LOGO-S

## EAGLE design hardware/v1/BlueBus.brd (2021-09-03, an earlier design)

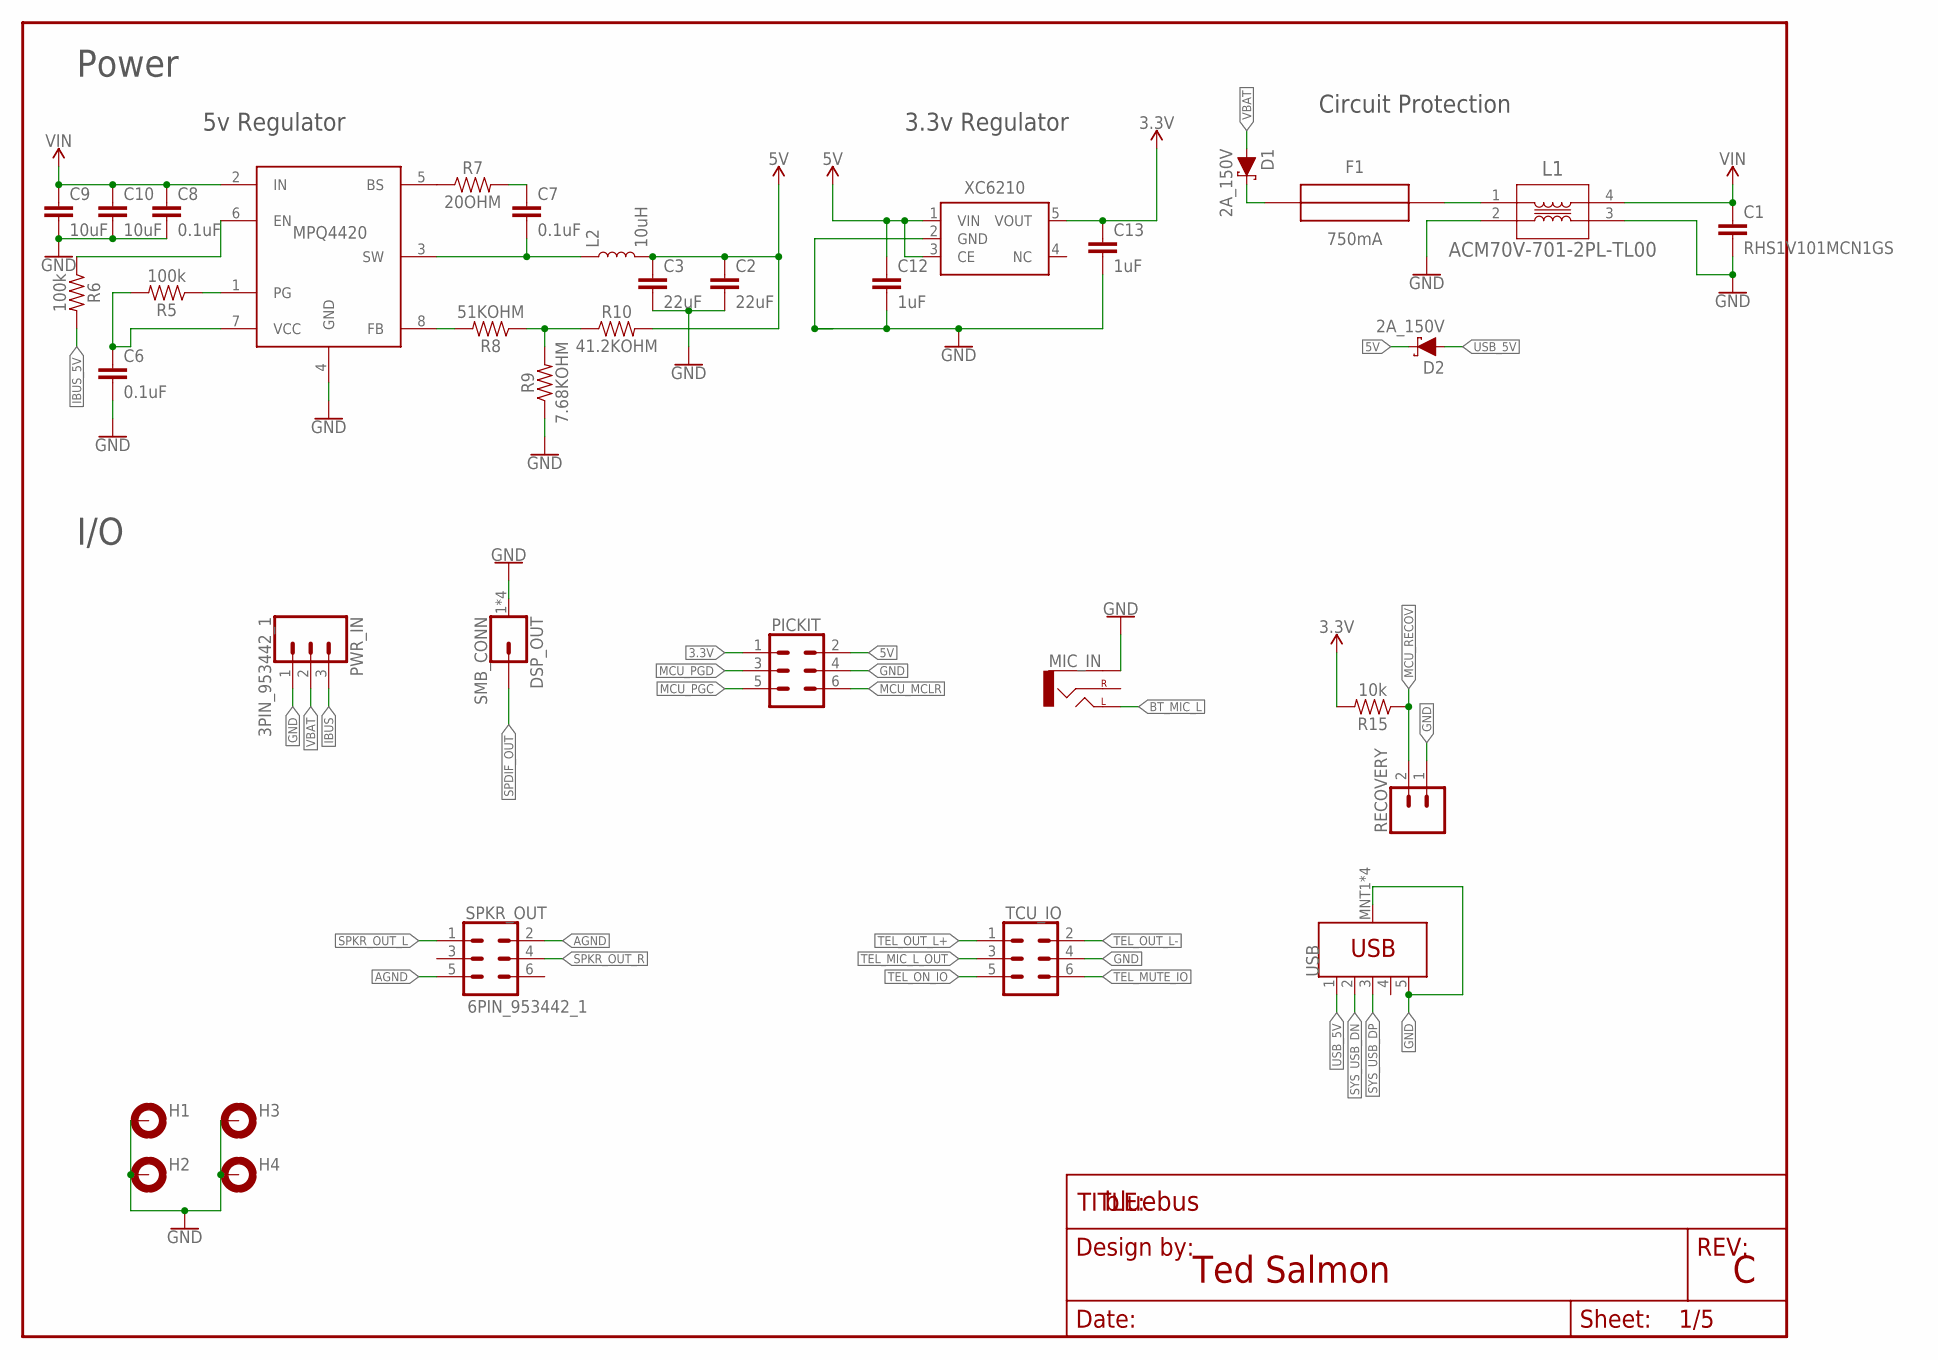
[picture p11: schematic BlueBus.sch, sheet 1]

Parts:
C1: RHS1V101MCN1GS
C2, C3: 22uF; 0805
C6, C7, C8: 0.1uF; 0805
C9, C10: 10uF; 1206
C12, C13: 1uF; 0805
D1, D2: 2A_150V; SOD123FL-2
DSP_OUT: SMB_CONN; MOLEX_SMB
F1: 750mA; LITTLEFUSE
FRAME1: FRAME-LETTER; DUMMY
H1, H2, H3, H4: 2,2-PAD; 2.2-PAD
L1: ACM70V-701-2PL-TL00
L2: 10uH; MPL-SE5040
MIC_IN: AUDIO-CUI-SJ-3523-SMT; AUDIO-CUI-SJ-352X-SMT
MPQ4420: MPQ4420; TSOT23-8
PICKIT: 6PIN_JUMPER; 2X3
PWR_IN: 3PIN_953442_1; TE_MQS_3PIN
R5, R6: 100k; 0805
R7: 20OHM; 0805
R8: 51KOHM; 0805
R9: 7.68KOHM; 0805
R10: 41.2KOHM; 0805
R15: 10k; 0805
RECOVERY: 2PIN_JUMPER; 1X02
SPKR_OUT: 6PIN_953442_1; TE_MQS_6PIN
TCU_IO: 6PIN_5_103166_1; TE_AMPMODU_6_PIN
USB: USB3080-30-01-A
XC6210: XC6210SOT25; SOT23-5

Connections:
3.3V: C13.1, PICKIT.1, R15.2, XC6210.5 (VOUT); also elsewhere on the board
5V: C2.1, C3.1, C12.1, D2.C, L2.2, PICKIT.2, R10.2, XC6210.1 (VIN), XC6210.3 (CE); also elsewhere on the board
5VREG_BS: MPQ4420.5 (BS), R7.1
5VREG_BS_CAP: C7.1, R7.2
5VREG_EN: MPQ4420.6 (EN), R6.1
5VREG_FB: MPQ4420.8 (FB), R8.2
5VREG_FB_T: R8.1, R9.2, R10.1
5VREG_PG: MPQ4420.1 (PG), R5.1
5VREG_SW: C7.2, L2.1, MPQ4420.3 (SW)
5VREG_VCC: C6.1, MPQ4420.7 (VCC), R5.2
AGND: SPKR_OUT.2, SPKR_OUT.5; also elsewhere on the board
BT_MIC_L: MIC_IN.TIP (LEFT); also elsewhere on the board
GND: C1.2, C2.2, C3.2, C6.2, C8.2, C9.2, C10.2, C12.2, C13.2, DSP_OUT.1 (GND), DSP_OUT.2 (GND), DSP_OUT.3 (GND), DSP_OUT.4 (GND), H1.B2.2, H2.B2.2, H3.B2.2, H4.B2.2, L1.2, L1.3, MIC_IN.SLEEVE, MPQ4420.4 (GND), PICKIT.4, PWR_IN.1, R9.1, RECOVERY.1, TCU_IO.4, USB.5 (GND), USB.MNT1 (SHIELD), USB.MNT2 (SHIELD), USB.MNT3 (SHIELD), USB.MNT4 (SHIELD), XC6210.2 (GND); also elsewhere on the board
IBUS: PWR_IN.3; also elsewhere on the board
IBUS_5V: R6.2; also elsewhere on the board
MCU_MCLR: PICKIT.6; also elsewhere on the board
MCU_PGC: PICKIT.5; also elsewhere on the board
MCU_PGD: PICKIT.3; also elsewhere on the board
MCU_RECOV: R15.1, RECOVERY.2; also elsewhere on the board
SPDIF_OUT: DSP_OUT.P$1 (1); also elsewhere on the board
SPKR_OUT_L: SPKR_OUT.1; also elsewhere on the board
SPKR_OUT_R: SPKR_OUT.4; also elsewhere on the board
SYS_USB_DN: USB.2 (D-); also elsewhere on the board
SYS_USB_DP: USB.3 (D+); also elsewhere on the board
TEL_MIC_L_OUT: TCU_IO.3; also elsewhere on the board
TEL_MUTE_IO: TCU_IO.6; also elsewhere on the board
TEL_ON_IO: TCU_IO.5; also elsewhere on the board
TEL_OUT_L+: TCU_IO.1; also elsewhere on the board
TEL_OUT_L-: TCU_IO.2; also elsewhere on the board
USB_5V: D2.A, USB.1 (VBUS)
VBAT: D1.A, PWR_IN.2
VBAT_DIODE: D1.C, F1.IN (OUT)
VBAT_FUSE: F1.OUT (IN), L1.1
VIN: C1.1, C8.1, C9.1, C10.1, L1.4, MPQ4420.2 (IN); also elsewhere on the board

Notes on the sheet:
Ted Salmon
Power
I/O
3.3v Regulator
5v Regulator
Circuit Protection

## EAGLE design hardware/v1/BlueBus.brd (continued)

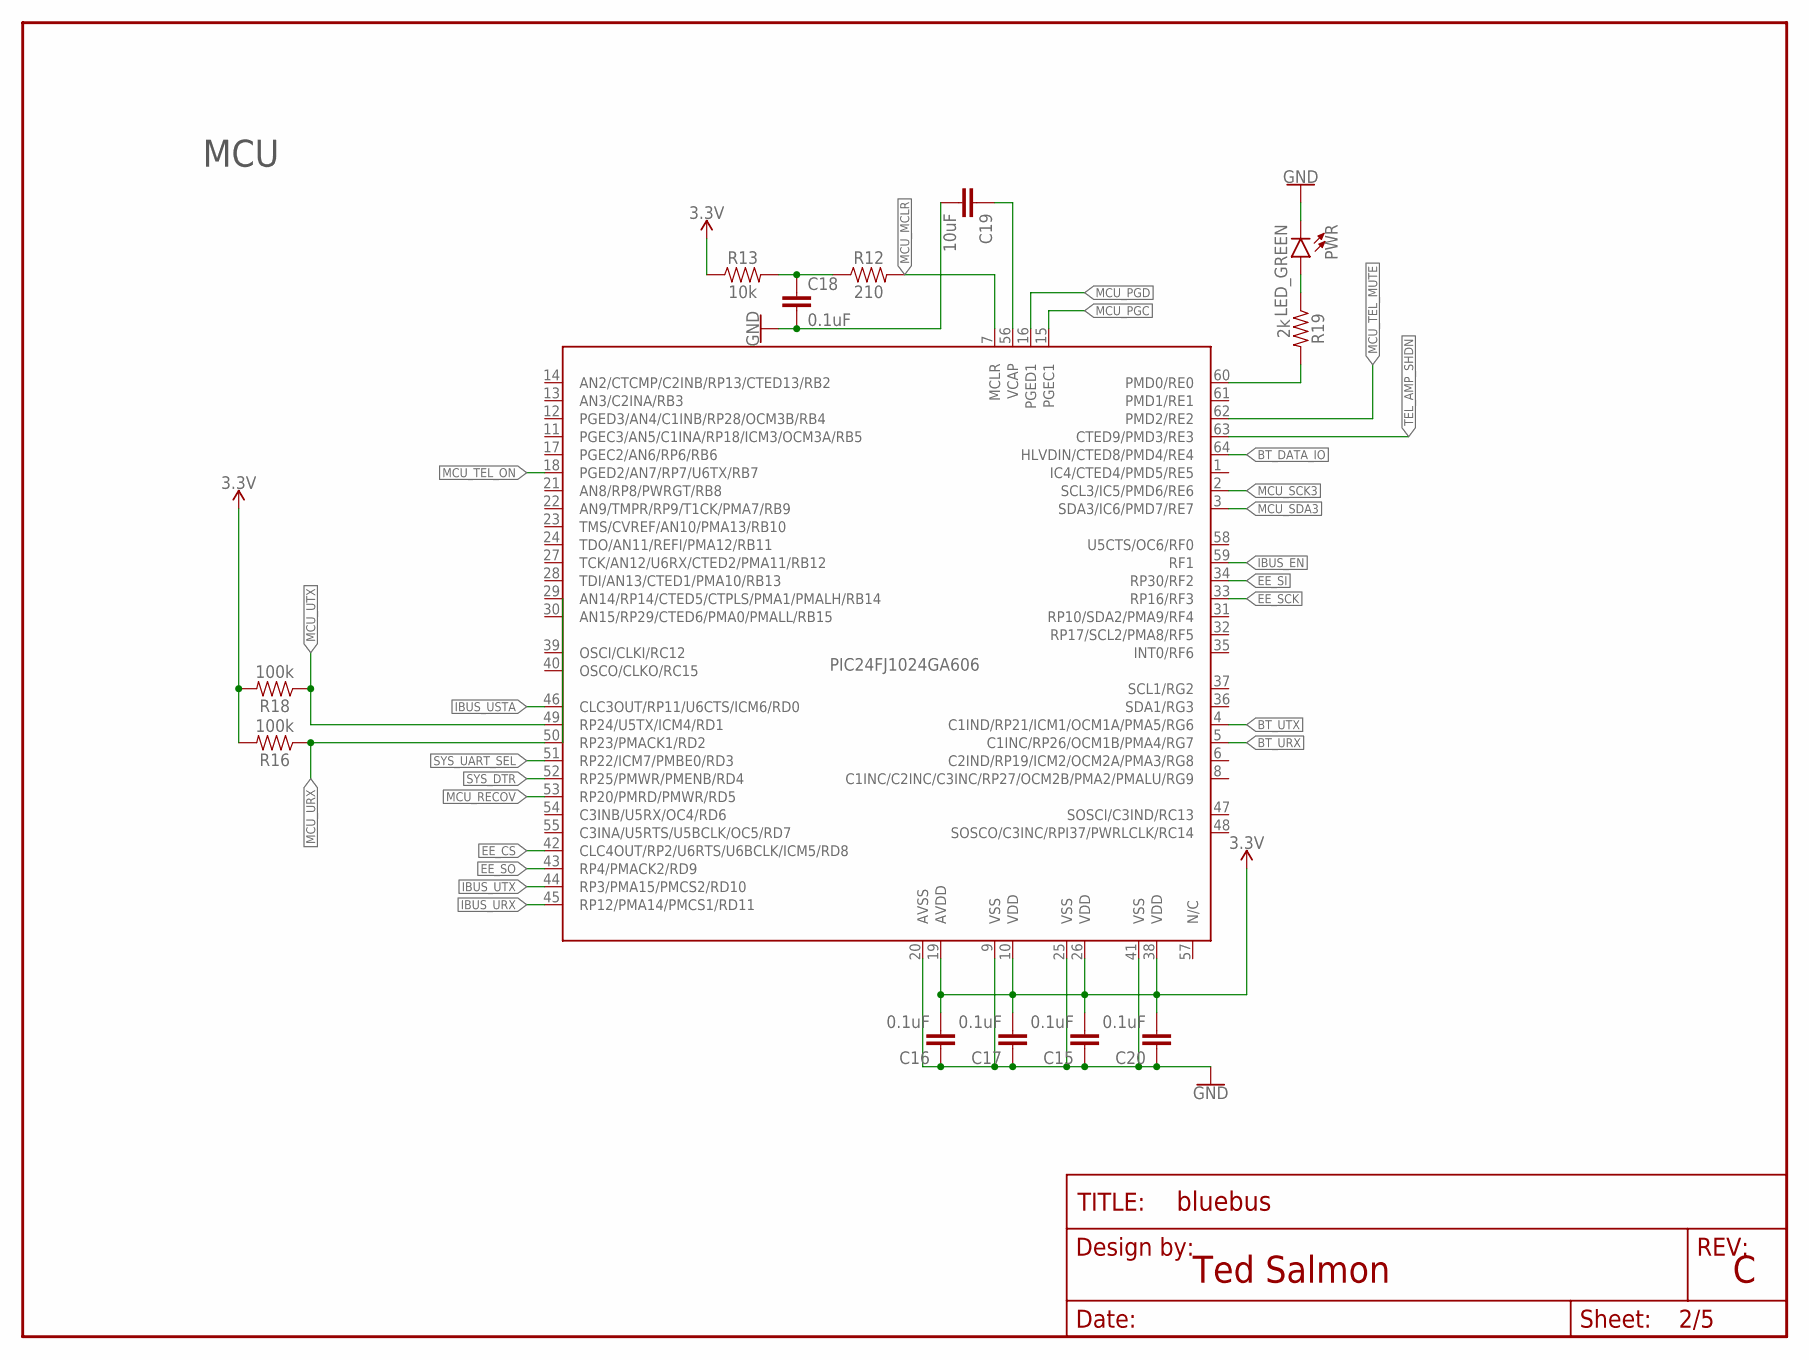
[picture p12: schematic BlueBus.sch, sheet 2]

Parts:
C15, C16, C17, C18, C20: 0.1uF; 0805
C19: 10uF; 0805
FRAME2: FRAME-LETTER; DUMMY
PIC24FJ1024GA606: PIC24FJ1024GA606; TQFP64
PWR: LED_GREEN; LED-0805
R12: 210; 0805
R13: 10k; 0805
R16, R18: 100k; 0805
R19: 2k; 0805

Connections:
3.3V: C15.2, C16.2, C17.2, C20.2, PIC24FJ1024GA606.10 (VDD), PIC24FJ1024GA606.19 (AVDD), PIC24FJ1024GA606.26 (VDD), PIC24FJ1024GA606.38 (VDD), R13.1, R16.2, R18.2; also elsewhere on the board
BT_DATA_IO: PIC24FJ1024GA606.64 (HLVDIN/CTED8/PMD4/RE4); also elsewhere on the board
BT_URX: PIC24FJ1024GA606.5 (C1INC/RP26/OCM1B/PMA4/RG7); also elsewhere on the board
BT_UTX: PIC24FJ1024GA606.4 (C1IND/RP21/ICM1/OCM1A/PMA5/RG6); also elsewhere on the board
EE_CS: PIC24FJ1024GA606.42 (CLC4OUT/RP2/U6RTS/U6BCLK/ICM5/RD8); also elsewhere on the board
EE_SCK: PIC24FJ1024GA606.33 (RP16/RF3); also elsewhere on the board
EE_SI: PIC24FJ1024GA606.34 (RP30/RF2); also elsewhere on the board
EE_SO: PIC24FJ1024GA606.43 (RP4/PMACK2/RD9); also elsewhere on the board
GND: C15.1, C16.1, C17.1, C18.2, C19.2, C20.1, PIC24FJ1024GA606.9 (VSS), PIC24FJ1024GA606.20 (AVSS), PIC24FJ1024GA606.25 (VSS), PIC24FJ1024GA606.41 (VSS), PWR.- (C); also elsewhere on the board
IBUS_EN: PIC24FJ1024GA606.59 (RF1); also elsewhere on the board
IBUS_URX: PIC24FJ1024GA606.45 (RP12/PMA14/PMCS1/RD11); also elsewhere on the board
IBUS_USTA: PIC24FJ1024GA606.46 (CLC3OUT/RP11/U6CTS/ICM6/RD0); also elsewhere on the board
IBUS_UTX: PIC24FJ1024GA606.44 (RP3/PMA15/PMCS2/RD10); also elsewhere on the board
MCU_MCLR: PIC24FJ1024GA606.7 (MCLR), R12.2; also elsewhere on the board
MCU_MCLR_RES: C18.1, R12.1, R13.2
MCU_ON_LED: PIC24FJ1024GA606.60 (PMD0/RE0), R19.2
MCU_ON_LED_RES: PWR.+ (A), R19.1
MCU_PGC: PIC24FJ1024GA606.15 (PGEC1); also elsewhere on the board
MCU_PGD: PIC24FJ1024GA606.16 (PGED1); also elsewhere on the board
MCU_RECOV: PIC24FJ1024GA606.53 (RP20/PMRD/PMWR/RD5); also elsewhere on the board
MCU_SCK3: PIC24FJ1024GA606.2 (SCL3/IC5/PMD6/RE6); also elsewhere on the board
MCU_SDA3: PIC24FJ1024GA606.3 (SDA3/IC6/PMD7/RE7); also elsewhere on the board
MCU_TEL_MUTE: PIC24FJ1024GA606.62 (PMD2/RE2); also elsewhere on the board
MCU_TEL_ON: PIC24FJ1024GA606.18 (PGED2/AN7/RP7/U6TX/RB7); also elsewhere on the board
MCU_URX: PIC24FJ1024GA606.50 (RP23/PMACK1/RD2), R16.1; also elsewhere on the board
MCU_UTX: PIC24FJ1024GA606.49 (RP24/U5TX/ICM4/RD1), R18.1; also elsewhere on the board
MCU_VCAP: C19.1, PIC24FJ1024GA606.56 (VCAP)
SYS_DTR: PIC24FJ1024GA606.52 (RP25/PMWR/PMENB/RD4); also elsewhere on the board
SYS_UART_SEL: PIC24FJ1024GA606.51 (RP22/ICM7/PMBE0/RD3); also elsewhere on the board
TEL_AMP_SHDN: PIC24FJ1024GA606.63 (CTED9/PMD3/RE3); also elsewhere on the board

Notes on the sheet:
Ted Salmon
MCU

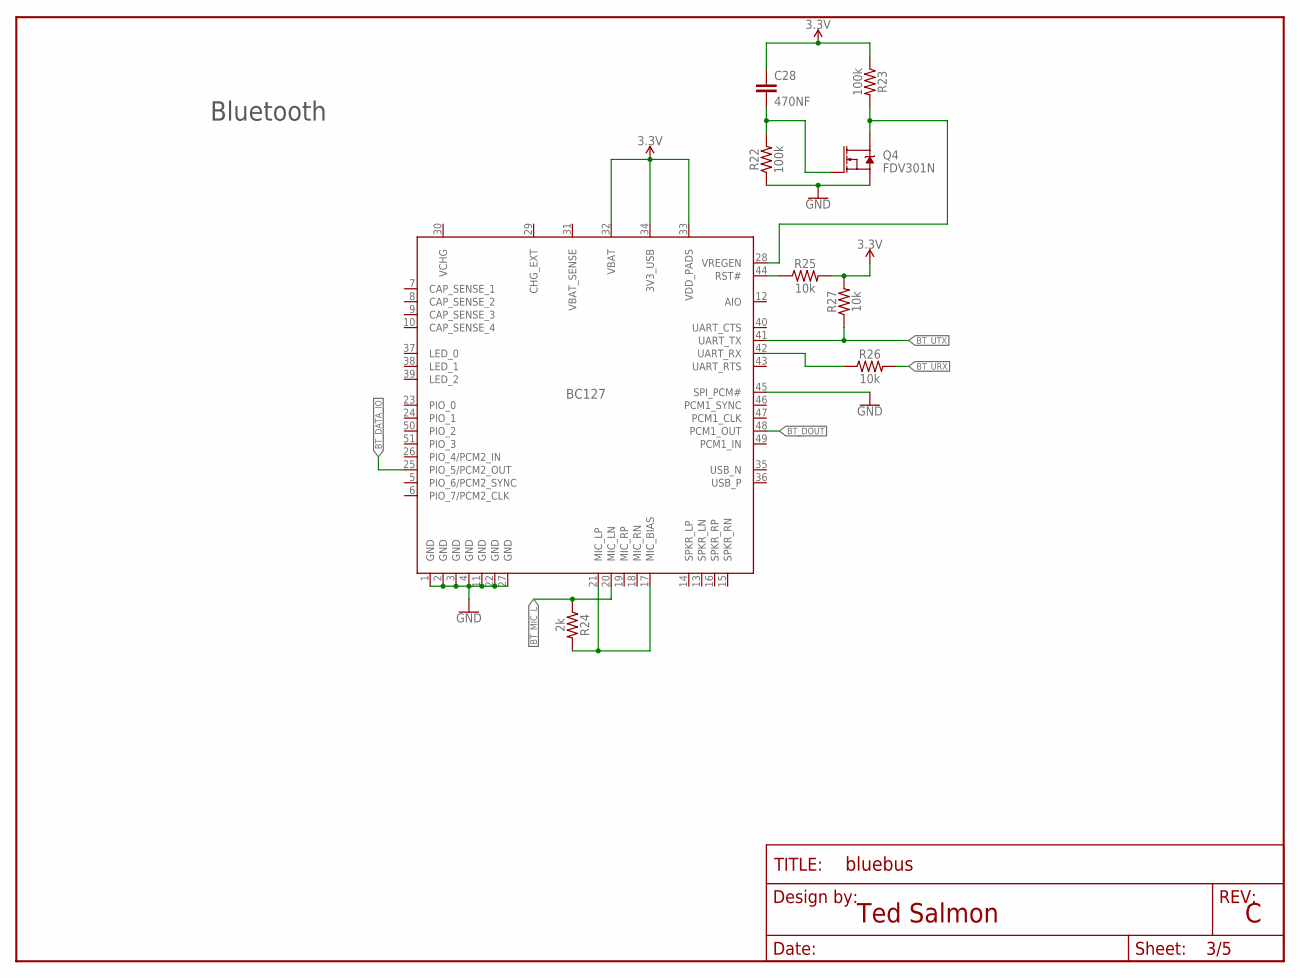
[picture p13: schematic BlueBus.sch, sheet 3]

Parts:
BC127: BC127
C28: 470NF; 0805
FRAME4: FRAME-LETTER; DUMMY
Q4: FDV301N; SOT-23
R22, R23: 100k; 0805
R24: 2k; 0805
R25, R26, R27: 10k; 0805

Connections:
3.3V: BC127.32 (VBAT), BC127.33 (VDD_PADS), BC127.34 (3V3_USB), C28.1, R23.1, R25.2, R27.2; also elsewhere on the board
BT_DATA_IO: BC127.25 (PIO_5/PCM2_OUT); also elsewhere on the board
BT_DOUT: BC127.48 (PCM1_OUT); also elsewhere on the board
BT_MIC_BIAS: BC127.17 (MIC_BIAS), BC127.21 (MIC_LP), R24.2
BT_MIC_L: BC127.20 (MIC_LN), R24.1; also elsewhere on the board
BT_RST: BC127.44 (RST#), R25.1
BT_URX: R26.2; also elsewhere on the board
BT_URX_RES: BC127.42 (UART_RX), R26.1
BT_UTX: BC127.41 (UART_TX), R27.1; also elsewhere on the board
BT_VREGEN: BC127.28 (VREGEN), Q4.3 (D), R23.2
BT_VREGEN_CAP_GATE: C28.2, Q4.1 (G), R22.2
CHG_EXT: BC127.29 (CHG_EXT)
GND: BC127.1 (GND), BC127.2 (GND), BC127.3 (GND), BC127.4 (GND), BC127.11 (GND), BC127.22 (GND), BC127.27 (GND), BC127.45 (SPI_PCM#), Q4.2 (S), R22.1; also elsewhere on the board
VBAT_SENSE: BC127.31 (VBAT_SENSE)
VCHG: BC127.30 (VCHG)

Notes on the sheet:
Bluetooth
Ted Salmon

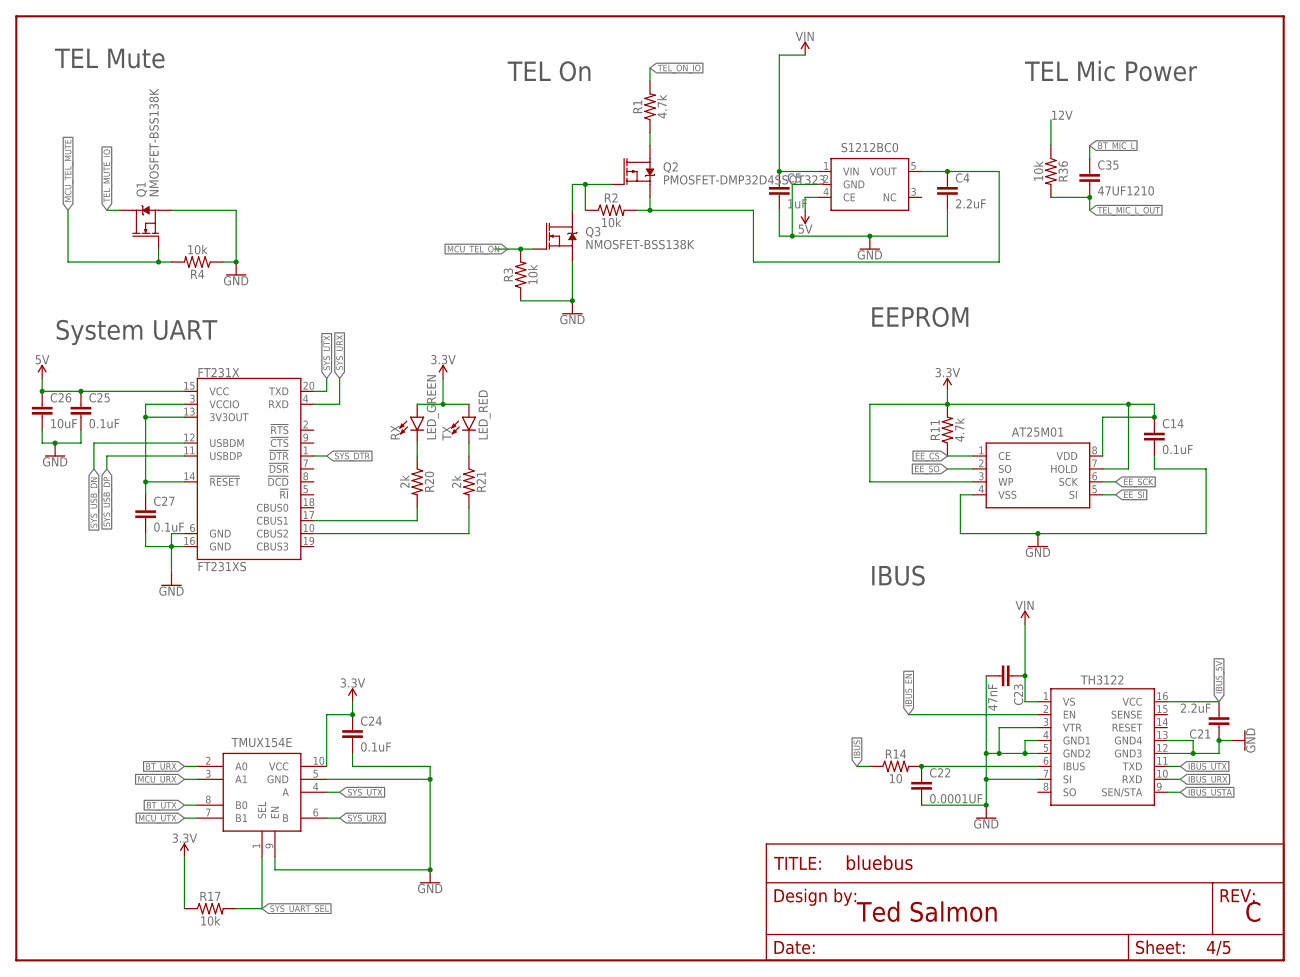
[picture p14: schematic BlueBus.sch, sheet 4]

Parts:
AT25M01: AT25M01-SHM; SOIJ-8
C4, C21: 2.2uF; 0805
C5: 1uF; 0805
C14, C24, C25, C27: 0.1uF; 0805
C22: 0.0001UF; 0805
C23: 47nF; 0805
C26: 10uF; 0805
C35: 47UF1210; 1210
FRAME3: FRAME-LETTER; DUMMY
FT231X: FT231XS; SSOP20_L
Q1, Q3: NMOSFET-BSS138K; SOT-23
Q2: PMOSFET-DMP32D4SSOT323; SOT323
R1, R11: 4.7k; 0805
R2, R3, R4, R17, R36: 10k; 0805
R14: 10; 0805
R20, R21: 2k; 0805
RX: LED_GREEN; LED-0805
S1212BC0: S-1212BC0-M5T1U; SOT23-5
TH3122: TH3122.4; SOIC16DF
TMUX154E: TMUX154E; VSSOP10
TX: LED_RED; LED-0805

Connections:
3.3V: AT25M01.3 (WP), AT25M01.7 (HOLD), AT25M01.8 (VDD), C14.1, C24.1, R11.2, R17.1, RX.+ (A), TMUX154E.10 (VCC), TX.+ (A); also elsewhere on the board
5V: C25.1, C26.1, FT231X.15 (VCC), S1212BC0.4 (CE); also elsewhere on the board
12V: C4.1, Q2.2 (S), R2.2, R36.1, S1212BC0.5 (VOUT)
BT_MIC_L: C35.1; also elsewhere on the board
BT_URX: TMUX154E.2 (A0); also elsewhere on the board
BT_UTX: TMUX154E.8 (B0); also elsewhere on the board
EE_CS: AT25M01.1 (CE), R11.1; also elsewhere on the board
EE_SCK: AT25M01.6 (SCK); also elsewhere on the board
EE_SI: AT25M01.5 (SI); also elsewhere on the board
EE_SO: AT25M01.2 (SO); also elsewhere on the board
GND: AT25M01.4 (VSS), C4.2, C5.2, C14.2, C21.1, C22.2, C23.2, C24.2, C25.2, C26.2, C27.2, FT231X.6 (GND), FT231X.16 (GND), Q1.2 (S), Q3.2 (S), R3.1, R4.1, S1212BC0.2 (GND), TH3122.3 (VTR), TH3122.4 (GND1), TH3122.5 (GND2), TH3122.7 (SI), TH3122.12 (GND3), TH3122.13 (GND4), TMUX154E.5 (GND), TMUX154E.9 (EN); also elsewhere on the board
IBUS: R14.1; also elsewhere on the board
IBUS_5V: C21.2, TH3122.16 (VCC); also elsewhere on the board
IBUS_EN: TH3122.2 (EN); also elsewhere on the board
IBUS_FILT: C22.1, R14.2, TH3122.6 (IBUS)
IBUS_URX: TH3122.10 (RXD); also elsewhere on the board
IBUS_USTA: TH3122.9 (SEN/STA); also elsewhere on the board
IBUS_UTX: TH3122.11 (TXD); also elsewhere on the board
MCU_TEL_MUTE: Q1.1 (G), R4.2; also elsewhere on the board
MCU_TEL_ON: Q3.1 (G), R3.2; also elsewhere on the board
MCU_URX: TMUX154E.3 (A1); also elsewhere on the board
MCU_UTX: TMUX154E.7 (B1); also elsewhere on the board
SYS_DTR: FT231X.1 (!DTR); also elsewhere on the board
SYS_RX_LED: FT231X.17 (CBUS1), R20.2
SYS_RX_LED_RES: R20.1, RX.- (C)
SYS_TX_LED: FT231X.10 (CBUS2), R21.2
SYS_TX_LED_RES: R21.1, TX.- (C)
SYS_UART_SEL: R17.2, TMUX154E.1 (SEL); also elsewhere on the board
SYS_URX: FT231X.4 (RXD), TMUX154E.6 (B)
SYS_USB_DN: FT231X.12 (USBDM); also elsewhere on the board
SYS_USB_DP: FT231X.11 (USBDP); also elsewhere on the board
SYS_UTX: FT231X.20 (TXD), TMUX154E.4 (A)
TEL_MIC_L_OUT: C35.2, R36.2; also elsewhere on the board
TEL_MUTE_IO: Q1.3 (D); also elsewhere on the board
TEL_ON: Q2.3 (D), R1.1
TEL_ON_EN: Q2.1 (G), Q3.3 (D), R2.1
TEL_ON_IO: R1.2; also elsewhere on the board
USB_3V3: C27.1, FT231X.3 (VCCIO), FT231X.13 (3V3OUT), FT231X.14 (!RESET)
VIN: C5.1, C23.1, S1212BC0.1 (VIN), TH3122.1 (VS); also elsewhere on the board

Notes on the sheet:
Ted Salmon
IBUS
EEPROM
TEL On
TEL Mute
TEL Mic Power
System UART

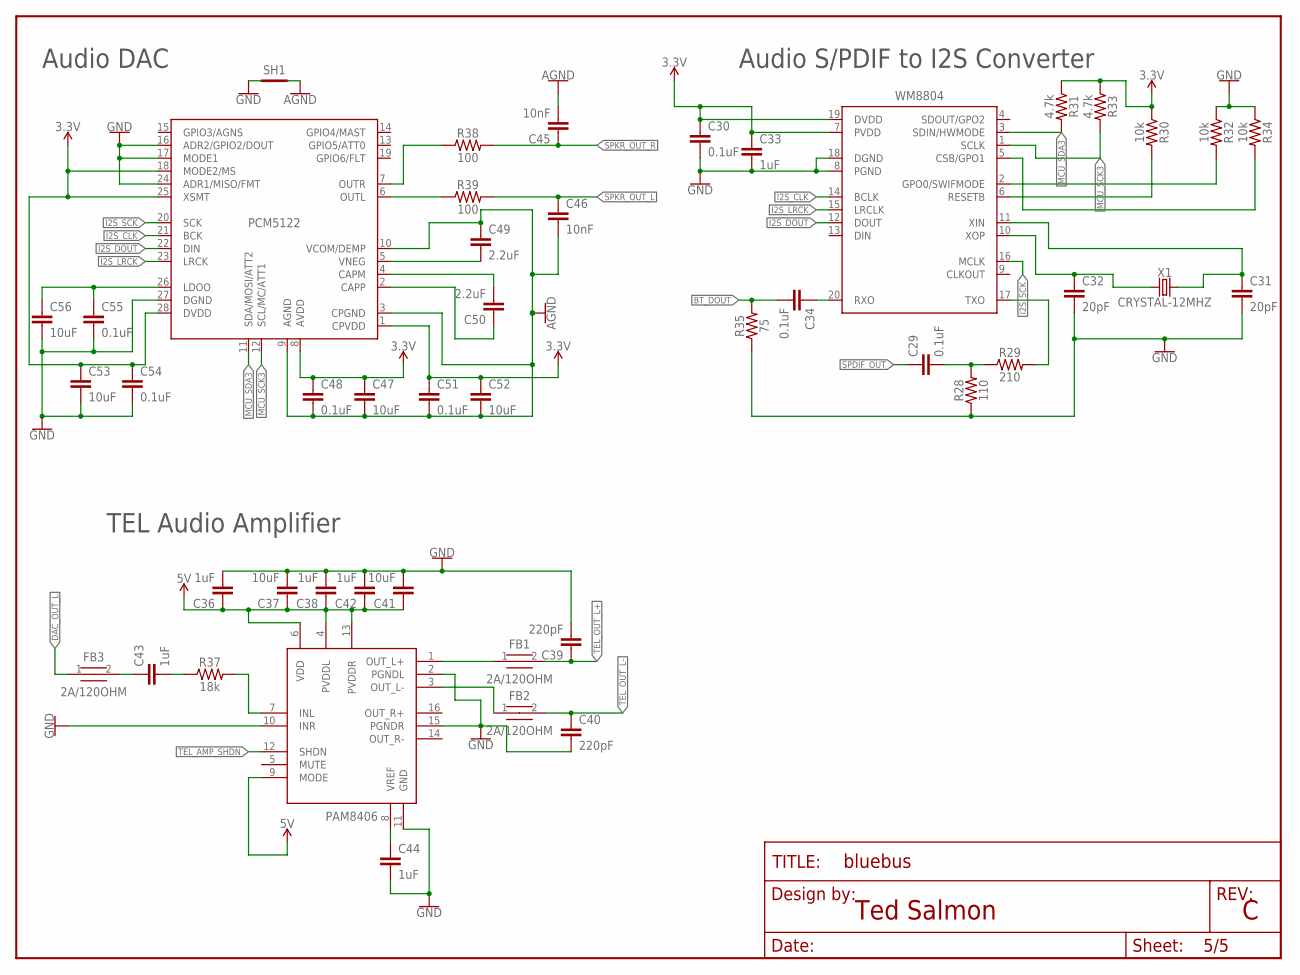
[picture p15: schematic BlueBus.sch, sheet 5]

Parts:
C29, C30, C34, C48, C51, C54, C55: 0.1uF; 0805
C31, C32: 20pF; 0805
C33, C36, C38, C42, C43, C44: 1uF; 0805
C37, C41, C47, C52, C53, C56: 10uF; 0805
C39, C40: 220pF; 0805
C45, C46: 10nF; 0805
C49, C50: 2.2uF; 0805
FB1, FB2, FB3: 2A/120OHM; 0805
FRAME5: FRAME-LETTER; DUMMY
PAM8406: PAM8406; SOP-16
PCM5122: PCM5122; TSSOP28
R28: 110; 0805
R29: 210; 0805
R30, R32, R34: 10k; 0805
R31, R33: 4.7k; 0805
R35: 75; 0805
R37: 18k; 0805
R38, R39: 100; 0805
SH1: SHORTT5; SHORT_TOP-50
WM8804: WM8804; SSOP20
X1: CRYSTAL-12MHZ; HC49

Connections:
3.3V: C30.1, C33.1, C47.1, C48.1, C51.1, C52.1, C53.1, C54.1, PCM5122.1 (CPVDD), PCM5122.8 (AVDD), PCM5122.18 (MODE2/MS), PCM5122.25 (XSMT), PCM5122.28 (DVDD), R30.1, R31.1, R33.1, WM8804.7 (PVDD), WM8804.19 (DVDD); also elsewhere on the board
5V: C36.1, C37.1, C38.1, C41.1, C42.1, PAM8406.4 (PVDDL), PAM8406.6 (VDD), PAM8406.9 (MODE), PAM8406.13 (PVDDR); also elsewhere on the board
AGND: C45.2, C46.2, C47.2, C48.2, C49.1, C51.2, C52.2, PCM5122.3 (CPGND), PCM5122.9 (AGND), PCM5122.10 (VCOM/DEMP), SH1.2; also elsewhere on the board
BT_DOUT: C34.2, R35.2; also elsewhere on the board
DAC_CAPM: C50.2, PCM5122.4 (CAPM)
DAC_CAPP: C50.1, PCM5122.2 (CAPP)
DAC_LDOO: C55.1, C56.1, PCM5122.26 (LDOO)
DAC_OUT_L: FB3.1, PCM5122.6 (OUTL), R39.1
DAC_OUT_R: PCM5122.7 (OUTR), R38.1
DAC_VNEG: C49.2, PCM5122.5 (VNEG)
GND: C30.2, C31.2, C32.2, C33.2, C36.2, C37.2, C38.2, C39.2, C40.2, C41.2, C42.2, C44.2, C53.2, C54.2, C55.2, C56.2, PAM8406.2 (PGNDL), PAM8406.10 (INR), PAM8406.11 (GND), PAM8406.15 (PGNDR), PCM5122.16 (ADR2/GPIO2/DOUT), PCM5122.17 (MODE1), PCM5122.24 (ADR1/MISO/FMT), PCM5122.27 (DGND), R28.1, R32.1, R34.1, R35.1, SH1.1, WM8804.8 (PGND), WM8804.18 (DGND); also elsewhere on the board
I2S_CLK: PCM5122.21 (BCK), WM8804.14 (BCLK)
I2S_DOUT: PCM5122.22 (DIN), WM8804.12 (DOUT)
I2S_LRCK: PCM5122.23 (LRCK), WM8804.15 (LRCLK)
I2S_SCK: PCM5122.20 (SCK), WM8804.16 (MCLK)
MCU_SCK3: PCM5122.12 (SCL/MC/ATT1), R33.2, WM8804.1 (SCLK); also elsewhere on the board
MCU_SDA3: PCM5122.11 (SDA/MOSI/ATT2), R31.2, WM8804.3 (SDIN/HWMODE); also elsewhere on the board
SPDIF_OUT: C29.1; also elsewhere on the board
SPDIF_RX: C34.1, WM8804.20 (RXO)
SPKR_OUT_L: C46.1, R39.2; also elsewhere on the board
SPKR_OUT_R: C45.1, R38.2; also elsewhere on the board
TEL_AMP_IN: C43.1, FB3.2
TEL_AMP_INL: PAM8406.7 (INL), R37.2
TEL_AMP_INL_CAP_RES: C43.2, R37.1
TEL_AMP_OUT_L+: FB1.1, PAM8406.1 (OUT_L+)
TEL_AMP_OUT_L-: FB2.1, PAM8406.3 (OUT_L-)
TEL_AMP_SHDN: PAM8406.12 (SHDN); also elsewhere on the board
TEL_AMP_VREF: C44.1, PAM8406.8 (VREF)
TEL_OUT_L+: C39.1, FB1.2; also elsewhere on the board
TEL_OUT_L-: C40.1, FB2.2; also elsewhere on the board
WM_CSB: R34.2, WM8804.5 (CSB/GPO1)
WM_GPO0: R32.2, WM8804.2 (GPO0/SWIFMODE)
WM_RESETB: R30.2, WM8804.6 (RESETB)
WM_SPDIF_TX_RES: R29.2, WM8804.17 (TXO)
WM_SPDIF_TX_RES2: C29.2, R28.2, R29.1
WM_XIN: C31.1, WM8804.11 (XIN), X1.2
WM_XOP: C32.1, WM8804.10 (XOP), X1.1

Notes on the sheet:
Audio DAC
Audio S/PDIF to I2S Converter
TEL Audio Amplifier
Ted Salmon

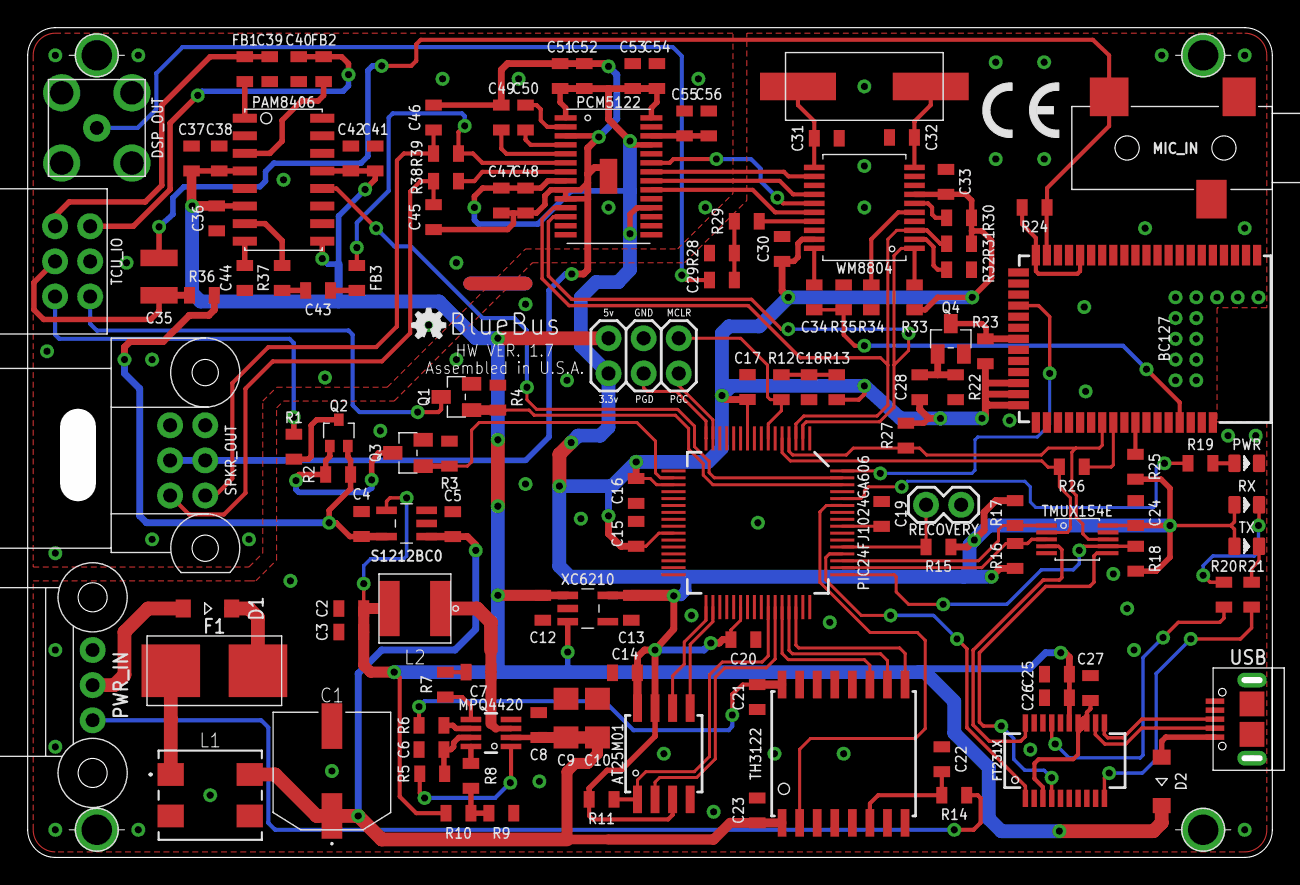
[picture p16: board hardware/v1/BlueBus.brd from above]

Board: 2 copper layers, 90.0 x 60.0 mm, 142 parts (0 on the bottom side), 99 nets.

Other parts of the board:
CE: CE-4MM
OSHW: OSHW-LOGO-MINI

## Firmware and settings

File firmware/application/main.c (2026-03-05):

/*
 * File: main.c
 * Author: Ted Salmon <tass2001@gmail.com>
 * Description:
 *     The main loop for our PIC24FJ
 */
#include <xc.h>
#include "sysconfig.h"
#include "handler.h"
#include "mappings.h"
#include "upgrade.h"
#include "lib/bt.h"
#include "lib/config.h"
#include "lib/eeprom.h"
#include "lib/log.h"
#include "lib/i2c.h"
#include "lib/ibus.h"
#include "lib/pcm51xx.h"
#include "lib/timer.h"
#include "lib/uart.h"
#include "lib/utils.h"
#include "lib/wm88xx.h"
#include "ui/cli.h"

int main(void)
{
    // Set the IVT mode
    IVT_MODE = IVT_MODE_APP;

    // Set all ports to digital mode
    ANSB = 0;
    ANSC = 0;
    ANSD = 0;
    ANSE = 0;
    ANSF = 0;
    ANSG = 0;

    // Set all ports as outputs
    TRISB = 0;
    TRISC = 0;
    TRISD = 0;
    TRISE = 0;
    TRISF = 0;
    TRISG = 0;

    // Drive all ports to logic low
    LATB = 0;
    LATC = 0;
    LATD = 0;
    LATE = 0;
    LATF = 0;
    LATG = 0;

    // Set the I/O ports to outputs
    BT_MFB_MODE = 0;
    BT_RST_MODE = 0;
    BT_DATA_SEL_MODE = 0;
    IBUS_EN_MODE = 0;
    ON_LED_MODE = 0;
    PAM_SHDN_MODE = 0;
    SPDIF_RST_MODE = 0;
    TEL_ON_MODE_V1 = 0;
    TEL_ON_MODE_V2 = 0;
    TEL_MUTE_MODE_V1 = 0;
    TEL_MUTE_MODE_V2 = 0;
    UART_SEL_MODE = 0;

    // Set the RX / input pins to inputs
    BOARD_VERSION_MODE = 1;
    BT_BOOT_TYPE_MODE = 1;
    BT_UART_RX_PIN_MODE = 1;
    EEPROM_SDI_PIN_MODE = 1;
    IBUS_UART_RX_PIN_MODE = 1;
    IBUS_UART_STATUS_MODE = 1;
    SYSTEM_UART_RX_PIN_MODE = 1;
    SYS_DTR_MODE = 1;

    // Enable the pull-down on the board version pin
    BOARD_VERSION_PD = 1;
    // Set the UART mode to MCU for the remainder of this application code
    UART_SEL = UART_SEL_MCU;
    // Enable the IBus Regulator
    IBUS_EN = 1;
    // Turn the PAM8406 off until it's required
    PAM_SHDN = 0;
    // Pull the DIT4096 low (Shared pin with HW1.x)
    SPDIF_RST = 0;
    // Keep the vehicle unmuted and telephone on disengaged
    UtilsSetPinMode(UTILS_PIN_TEL_MUTE, 0);
    UtilsSetPinMode(UTILS_PIN_TEL_ON, 0);
    // Keep the BC127 out of data mode
    BT_DATA_SEL = 0;
    // Set the BM83 up for boot
    BT_MFB = 0;
    BT_RST = 0;

    // Initialize the system UART first, since we needed it for debug
    struct UART_t systemUart = UARTInit(
        SYSTEM_UART_MODULE,
        SYSTEM_UART_RX_RPIN,
        SYSTEM_UART_TX_RPIN,
        SYSTEM_UART_RX_PRIORITY,
        SYSTEM_UART_TX_PRIORITY,
        UART_BAUD_115200,
        UART_PARITY_NONE
    );
    // Grab the hardware version
    uint8_t boardVersion = UtilsGetBoardVersion();

    // All UART handler registrations need to be done at
    // this level to maintain a global scope
    UARTAddModuleHandler(&systemUart);
    LogMessage("", "**** BlueBus ****");

    // Initialize low level modules
    EEPROMInit();
    UtilsCheckRCON();
    TimerInit();
    I2CInit();

    struct BT_t bt = BTInit();
    UARTAddModuleHandler(&bt.uart);

    struct IBus_t ibus = IBusInit();
    UARTAddModuleHandler(&ibus.uart);

    // WM8804 and PCM5122 must be initialized after the I2C Bus
    if (boardVersion == BOARD_VERSION_ONE) {
        WM88XXInit();
    }
    PCM51XXInit();

    // SPDIF_RST is reused from version one where it was TEL_MUTE
    // Do not alter its state on v1.x boards
    if (boardVersion == BOARD_VERSION_TWO) {
        // Enable the SPDIF Transmitter (after being low for >= 500ns)
        SPDIF_RST = 1;
    }

    ON_LED = 1;
    // Initialize handlers
    HandlerInit(&bt, &ibus);
    // Initialize the CLI
    CLIInit(&systemUart, &bt, &ibus);
    // Run any applicable updates
    UpgradeProcess(&bt, &ibus);
    // Run the PCM51XX Start-up process
    PCM51XXStartup();
    // Reset the Boot flag in the EEPROM to indicate a valid boot
    ConfigSetBootloaderMode(0x00);

    // Process events
    while (1) {
        BTProcess(&bt);
        IBusProcess(&ibus);
        TimerProcessScheduledTasks();
        CLIProcess();
    }

    return 0;
}

// Trap Catches
void TrapWait()
{
    ON_LED = 0;
    // Wait five seconds before resetting
    uint32_t sleepCount = 0;
    while (sleepCount <= 50000) {
        TimerDelayMicroseconds(1000);
        sleepCount++;
    }
    UtilsReset();
}

void __attribute__ ((__interrupt__, auto_psv)) _AltOscillatorFail()
{
    // Clear the trap flag
    INTCON1bits.OSCFAIL = 0;
    ConfigSetTrapIncrement(CONFIG_TRAP_OSC);
    TrapWait();
}

void __attribute__ ((__interrupt__, auto_psv)) _AltAddressError()
{
    // Clear the trap flag
    INTCON1bits.ADDRERR = 0;
    ConfigSetTrapIncrement(CONFIG_TRAP_ADDR);
    TrapWait();
}

void __attribute__ ((__interrupt__, auto_psv)) _AltStackError()
{
    // Clear the trap flag
    INTCON1bits.STKERR = 0;
    ConfigSetTrapIncrement(CONFIG_TRAP_STACK);
    TrapWait();
}

void __attribute__ ((__interrupt__, auto_psv)) _AltMathError()
{
    // Clear the trap flag
    INTCON1bits.MATHERR = 0;
    ConfigSetTrapIncrement(CONFIG_TRAP_MATH);
    TrapWait();
}

void __attribute__ ((__interrupt__, auto_psv)) _AltNVMError()
{
    ConfigSetTrapIncrement(CONFIG_TRAP_NVM);
    TrapWait();
}

void __attribute__ ((__interrupt__, auto_psv)) _AltGeneralError()
{
    ConfigSetTrapIncrement(CONFIG_TRAP_GEN);
    TrapWait();
}

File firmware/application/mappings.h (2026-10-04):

/*
 * IO Mappings for the PIC24
 */
#ifndef IO_MAPPINGS_H
#define IO_MAPPINGS_H
#define IBUS_UART_MODULE 1
#define IBUS_UART_RX_PRIORITY 7
#define IBUS_UART_TX_PRIORITY 5
#define IBUS_UART_RX_PIN_MODE TRISDbits.TRISD11
#define IBUS_UART_RX_PIN LATDbits.LATD11
#define IBUS_UART_RX_RPIN 12
#define IBUS_UART_TX_PIN_MODE TRISDbits.TRISD10
#define IBUS_UART_TX_PIN LATDbits.LATD10
#define IBUS_UART_TX_RPIN 3
#define IBUS_UART_STATUS_MODE TRISDbits.TRISD0
#define IBUS_UART_STATUS PORTDbits.RD0


#define BT_UART_MODULE 2
#define BT_UART_RX_PRIORITY 6
#define BT_UART_TX_PRIORITY 5
#define BT_UART_RX_PIN_MODE TRISGbits.TRISG6
#define BT_UART_RX_PIN LATGbits.LATG6
#define BT_UART_RX_RPIN 21
#define BT_UART_TX_PIN_MODE TRISGbits.TRISG7
#define BT_UART_TX_PIN LATGbits.LATG7
#define BT_UART_TX_RPIN 26

#define SYSTEM_UART_MODULE 3
#define SYSTEM_UART_RX_PRIORITY 3
#define SYSTEM_UART_TX_PRIORITY 4
#define SYSTEM_UART_RX_PIN_MODE TRISDbits.TRISD2
#define SYSTEM_UART_RX_PIN LATDbits.LATD2
#define SYSTEM_UART_RX_RPIN 23
#define SYSTEM_UART_TX_PIN_MODE TRISDbits.TRISD1
#define SYSTEM_UART_TX_PIN LATDbits.LATD1
#define SYSTEM_UART_TX_RPIN 24

#define EEPROM_SPI_MODULE 1
#define EEPROM_CS_PIN PORTDbits.RD8
#define EEPROM_CS_IO_MODE TRISDbits.TRISD8
#define EEPROM_SCK_RPIN 16
#define EEPROM_SDI_PIN_MODE TRISDbits.TRISD9
#define EEPROM_SDI_RPIN 4
#define EEPROM_SDO_RPIN 30

#define BOARD_VERSION_ONE 0
#define BOARD_VERSION_TWO 1

#define BOARD_VERSION_MODE TRISGbits.TRISG8
#define BOARD_VERSION_STATUS PORTGbits.RG8
#define BOARD_VERSION_PD IOCPDGbits.IOCPDG8

#define BT_BOOT_TYPE_MODE TRISEbits.TRISE1
#define BT_BOOT_TYPE LATEbits.LATE1

#define BT_DATA_SEL_MODE TRISEbits.TRISE4
#define BT_DATA_SEL LATEbits.LATE4

#define BT_MFB_MODE TRISEbits.TRISE5
#define BT_MFB LATEbits.LATE5

#define BT_RST_MODE TRISFbits.TRISF0
#define BT_RST LATFbits.LATF0

#define I2C3_SDA_MODE TRISEbits.TRISE7
#define I2C3_SDA LATEbits.LATE7
#define I2C3_SDA_STATUS PORTEbits.RE7

#define I2C3_SCL_MODE TRISEbits.TRISE6
#define I2C3_SCL LATEbits.LATE6
#define I2C3_SCL_STATUS PORTEbits.RE6

#define ON_LED_MODE TRISEbits.TRISE0
#define ON_LED LATEbits.LATE0

#define UART_SEL_BT 0
#define UART_SEL_MCU 1
#define UART_SEL_MODE TRISDbits.TRISD3
#define UART_SEL LATDbits.LATD3

#define IVT_MODE INTCON2bits.AIVTEN
#define IVT_MODE_APP 1
#define IVT_MODE_BOOT 0

#define IBUS_EN_MODE TRISFbits.TRISF1
#define IBUS_EN_STATUS PORTFbits.RF1
#define IBUS_EN LATFbits.LATF1

#define PAM_SHDN_MODE TRISEbits.TRISE3
#define PAM_SHDN LATEbits.LATE3

#define SPDIF_RST_MODE TRISEbits.TRISE2
#define SPDIF_RST LATEbits.LATE2

#define SYS_DTR_MODE TRISDbits.TRISD4
#define SYS_DTR_STATUS PORTDbits.RD4

#define TEL_ON_MODE_V1 TRISBbits.TRISB7
#define TEL_ON_V1 LATBbits.LATB7

#define TEL_MUTE_MODE_V1 TRISEbits.TRISE2
#define TEL_MUTE_V1 LATEbits.LATE2

#define TEL_ON_MODE_V2 TRISFbits.TRISF5
#define TEL_ON_V2 LATFbits.LATF5

#define TEL_MUTE_MODE_V2 TRISFbits.TRISF4
#define TEL_MUTE_V2 LATFbits.LATF4

// UI Events
#define UI_EVENT_INITIATE_CONNECTION 96
#define UI_EVENT_CLOSE_CONNECTION 97
#define UI_EVENT_MAIN_DISPLAY_UPDATE 98
#define UI_EVENT_CLI_WRITE_BEFORE 99
#define UI_EVENT_CLI_WRITE_COMPLETE 100

#define FIRMWARE_VERSION_MAJOR 1
#define FIRMWARE_VERSION_MINOR 4
#define FIRMWARE_VERSION_PATCH 43

void TrapWait();
#endif /* IO_MAPPINGS_H */

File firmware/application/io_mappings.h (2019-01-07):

/*
 * IO Mappings for the PIC24
 */
#ifndef IO_MAPPINGS_H
#define IO_MAPPINGS_H
#define IBUS_UART_MODULE 1
#define IBUS_UART_RX_PRIORITY 7
#define IBUS_UART_TX_PRIORITY 5
#define IBUS_UART_RX_PIN 12
#define IBUS_UART_TX_PIN 3
#define IBUS_UART_STATUS PORTDbits.RD3

#define BC127_UART_MODULE 2
#define BC127_UART_RX_PRIORITY 6
#define BC127_UART_TX_PRIORITY 5
#define BC127_UART_RX_PIN 21
#define BC127_UART_TX_PIN 26

#define SYSTEM_UART_MODULE 3
#define SYSTEM_UART_RX_PRIORITY 3
#define SYSTEM_UART_TX_PRIORITY 4
#define SYSTEM_UART_RX_PIN 24
#define SYSTEM_UART_TX_PIN 23

#define EEPROM_SPI_MODULE 1
#define EEPROM_CS_PIN PORTDbits.RD8
#define EEPROM_CS_IO_MODE TRISDbits.TRISD8
#define EEPROM_SCK_PIN 16
#define EEPROM_SDI_PIN 4
#define EEPROM_SDO_PIN 30

#define ON_LED_MODE TRISEbits.TRISE0
#define ON_LED LATEbits.LATE0
#endif /* IO_MAPPINGS_H */

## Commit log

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2018-06-26 [IMP] firmware: Stability and usability improvements to the core * Fix UART Issue causing BT UART TX to not work due to chosen pin * Change UART functionality to be more congruent * Remove frivolous 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
    [io_mappings.h, main.c]
2018-06-29 [IMP] firmware: General improvements and begin IBus support * Fix va args for logging messages * Improve BC127 support and logging * Begin IBus implementation * Begin Timer implementation
    [io_mappings.h, main.c]
2018-07-05 [IMP] firmware: Continue improving and building framework * Begin implementing IBus * Emulate CD Changer * Continue BC127 API implementation * Fix off-by-one bugs and other stack overflows
    [main.c]
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2018-07-11 [IMP] firmware: Enhance BT / IBus connectivity * Pause / Request data based on state changes * Remove useless "struct" declarations * Resolve bug with scheduled tasks * Use pointers instead of copyin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
    [main.c]
2018-07-19 [IMP] firmware: Many bugfixes and improvements to the IBus handling code * Add XOR checksum verification of IBus messages * Abstract BT connections * Add debugging for frame/pairity errors on UART * 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
    [io_mappings.h, main.c]
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2018-08-08 [IMP] firmware: Refactor connected BT device handling * Disallow more than a single BT connection at a time * Automatically scan for all devices in the BC127 pairing list and use those to populate se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
    [bmbt.h]
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2018-08-19 [IMP] firmware: Massive BMBT and BC127 fixes * BC127 Improvements: * Disable auto-connect and automatically select first device that we find on ignition on * Handle Device Resets Gracefully * Handle 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
    [bmbt.h]
2018-08-21 [IMP] firmware: IBus improvements to lower messages transmitted * Use update command to refresh screen back to previous state instead of writing the entire screen back out * Resolve bug where CDC mod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
    [bmbt.h]
2018-08-22 [FIX] firmware: Refactor BMBT Menus and resolve CDC AWOL Bug * Refactor and condense BMBT Menus * Remove frivolous calls to redraw the menu items * Add timer that will preemptively supply the RAD wit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
    [bmbt.h]
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2018-09-03 [IMP] firmware: BM53/54 Improvements * Add menu enable / disable message * Correctly report number of discs in changer to get rid of "No Disc" error * Move UI elements around so they make more sense 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
    [bmbt.h]
2018-09-05 [IMP] firmware: IBus / BM53/54 Improvements * Move Menu Writing to a scheduled task to avoid glitchy menus * Report 1 disc loaded to ensure that the radio does not fade out momentarily while switchin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
    [bmbt.h]
2018-09-06 [IMP] firmware: IBus / BM53/54 Improvements * Resolve issue with Glitchy Menus * Remove useless screen refreshes so that we can move away from the timer based menu writing system
    [bmbt.h]
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2018-09-08 [FIX] firmware: BMBT Menu Improvements * Do not assume we're playing so when the vehicle starts we perform the right actions * Push out all TX buffers at the same time to prevent the radio from over-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
    [bmbt.h]
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2018-09-25 [IMP] firmware: BC127 /BMBT Fixes * Alter UART RX ISR to perform quicker and thus not leave bytes in the RX buffer * Add Timer to write the BMBT Menu after a given timeout if it has not already been 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
    [bmbt.h]
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2018-10-09 [IMP] hardware: Add Diode to 5V USB Input * Add diode to prevent voltage oopsies in case someone plugs > 5VDC to the rail
    [BlueBus.brd, BlueBus.sch]
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2018-10-26 [ADD] hardware: BlueBus v4 Board Changes * Remove BC127 LEDs * Enlarge all IC pads to make SMD assembly easier * Rewire 3.3v Rail into a star topology to do away with potential issues from dasiy chai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
    [BlueBus.brd]
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2018-10-30 [ADD] hardware: Minor board changes * Add mounting holes * Fix uneven pitch of crystal caps * Replace wide through-hole pins with standard sized ones * Update name of TPA6017A2 IC * Update trace widt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
    [BlueBus.brd, BlueBus.sch]
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2018-11-06 [ADD] hardware: BlueBus Board rev. 5 * Add primary 8MHz oscillator * Wire EEPROM signals to compatible pins * Rewire all capacitors so they are not inline with the power rail (Mostly on MCU) * Update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
    [BlueBus.brd, BlueBus.sch]
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2018-11-08 [ADD] hardware: BlueBus v5 updates * Remove external crystals * Add pull up resistors to MCLR -- Bug in existing boards causing unstable operation * Rewire BC127 UART lines to MCU
    [BlueBus.brd, BlueBus.sch]
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2018-11-11 [ADD] hardware: BlueBus v6 * Version bump for new PCB run * Remove passives from IBus line causing I/O issues * Rewire gain settings on TPA6017A2 to 10dB gain, rather than 15.7dB * Ensure all vias ar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
    [BlueBus.brd, BlueBus.sch]
2018-11-13 [ADD] hardware: Update PWP * Correctly add tStop/bStop layer to TPA6017A2 to remove silkscreen from thermal pad
    [BlueBus.brd, BlueBus.sch]
2018-11-13 [ADD] firmware: Begin Bootloader * Add Build config for application / bootloader * Add Application/Bootloader Linker Scripts (Default for now). * Remove gitignore for Makefiles for each configuration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
    [main.c]
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2018-11-16 [IMP] firmware_bootloader: Add RX Queue timeout * Add 1 second timeout to RX queue to prevent bytes from becoming stuck
    [main.c]
2018-11-19 [FIX] firmware_bootloader: Fixes to allow flash writing * Fix protocol decoding issues * Fix issues sending legitimate messages to the host * Fix issues writing data to flash * Document codebase
    [main.c]
2018-11-21 [FIX] firmware_bootloader: Fixes for firmware writing * Enlarge bootloader to 0x1000 bytes * Call application code via void pointer, rather than ASM * Add logic to erase FLASH memory prior to writing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
    [main.c, mappings.h]
2018-11-21 [FIX] firmware_application: Minor updates * Add ISRs for NVMError and GeneralError traps * Move application code to 0x1800 to allow for larger bootloader * Single partition mode set explicitly
    [main.c]
2018-11-23 [IMP] firmware_bootloader: Allow BC127 management * Add code to manage (including FW upgrades) the BC127 module via the system UART * Decrease Bootloader timeout to 5 seconds * Decrease bootloader me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
    [main.c, mappings.h]
2018-11-30 [FIX] firmware_application: Minor Fixes * Fix IO Mappings for EEPROM * Pull up BT Reset pin on boot to ensure no ambiguity * Resize Application Space to start at 0x1000 * Update code to set RPOR Mode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
    [io_mappings.h, main.c]
2018-11-30 [FIX] hardware: BlueBus v7 * Update Silkscreen for Speaker outputs * Rewire Speaker negative outputs to support single ended operation without overheating * Place 10uF cap for TPA6017A2 near input of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
    [BlueBus.brd, BlueBus.sch]
2018-12-20 [IMP] hardware: BlueBus Rev A * Remove TPA6017A2 in favor of PCM5102A Line Level DAC which will fix quality issues * Completely new layout of board and schematic * Update Silkscreen to use vector fon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
    [BlueBus.brd, BlueBus.sch]
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2019-01-15 [IMP] hardware: PCM5102AQ1 fixes * Remove +3.3 from LDOO caps * Wire XSMT & FMT back to +3.3 * Rewire feedback pin of +5v switching regulator
    [BlueBus.brd, BlueBus.sch]
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2019-02-03 [IMP] hardware: BlueBus Rev A v4 * Add quad tri-state buffer to make system UART selectable between the MCU and BT module * Replace MCP2221A with FT232RQ in order to be able to use even parity UART f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
    [BlueBus.brd, BlueBus.sch]
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2019-02-14 [IMP] firmware: Improve Bootloader and move to v 1.1 * Use EEPROM to store bootloader lock mode * Write Reset Vector immediately after erasing 0x00 in NVM * Remove useless functionality * Update Plat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
    [main.c, mappings.h]
2019-02-18 [FIX] firmware: Bugfixes to the application code - v1.0.1 * Correctly respond to "Random Mode" * Correctly respond to "Seek" mode * Add ability to disable Metadata scrolling on CD53 * Implement AVRCP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
    [main.c]
2019-02-19 [FIX] firmware: Bugfixes to the application code - v1.0.2 * Correctly initiate an AVRCP Rewind * Effectively disable Metadata scrolling on CD53 without killing the menus * Improve Bluetooth connectio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
    [main.c]
2019-02-21 [FIX] firmware: Enhancements to the application code * Refactor logging code * Add ability to disable logs from different systems * Improve auto-connection code * Improve BMBT code * Add BC127 comman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
    [bmbt.h, main.c]
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2019-03-19 [FIX] hardware: Reb B PCB * Add TS5A22364 switch to ground L/R while not playing * Add TMUX154E in place of tri-state buffer as a UART switch * Replace FT232RQ with FT232L which will be easier to sol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
    [BlueBus.brd, BlueBus.sch]
2019-03-21 [FIX] hardware: Reb B PCB Silkscreen * Update Silkscreen names so they are not covered by pads * Update a couple of small traces
    [BlueBus.brd]
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2019-03-21 [IMP] firmware: Application v 1.0.5 * Adjust EEPROM memory layout into chunks for different uses * Add ability to autoplay music on connect * Add ability to chose between chunked or party style scrol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
    [bmbt.h, main.c]
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2019-04-02 [IMP] firmware: Bootloader v 1.2 * Resolve packet issues by utilizing lower error baud rate of 111000 * Add BC127 support so that firmware updates can happen OTA via BT * Begin utilizing AIVT for app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
    [main.c, mappings.h]
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2019-07-11 [IMP] hardware: BlueBus Rev C * Add MOSFETs to handle TCU ON / Mute Signaling * Add PAM8406 for call audio output * Add WM8804 for S/PDIF to I2S conversion so that both S/PDIF and I2S can be availabl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
    [BlueBus.brd, BlueBus.sch]
2019-08-03 [IMP] hardware: Rev C * Add TL064A to reduce IBus noise and attenuate the gain of the DAC * Add WM8804 to convert S/PDIF to I2S * Add circuitry to emulate factory Telephone * Add connector for factor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
    [BlueBus.brd, BlueBus.sch]
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2019-08-13 [IMP] application: v1.0.8 improvements * Add trap counter * Fix issues with BC127 notification parsing * Fix I2C issues * Fix issues with WM8804 & PCM5102A * Add code to power unit off after given ti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
    [main.c, mappings.h]
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2019-09-04 [IMP] hardware: Minor Rev C updates * Route TX/RX LED signals to correct LED * 25LC1024 swap * Align OSHW / BlueBus Logo correctly
    [BlueBus.brd, BlueBus.sch]
2019-09-11 [IMP] aplication: 1.0.9 * Improved the CD Changer emulation code * Resolved issues with the CD53 display being cleared and not re-written sometimes * Resolved issues with dimmer status not being corr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
    [bmbt.h]
2019-09-25 [IMP] firmware: Application 1.0.9.3
    * Enhance C43 support
    * Resolve issues with flickering UI for Navigation setups
    * Add Mic gain setting in CLI
    * Fully support MKI/MKII/MKII older UI
    * Add code to handle power off failures
    [bmbt.h, mappings.h]
2019-09-28 [IMP] hardware: Rev C Updates
    * Ground Shields for USB and S/PDIF
    * Wire S/PDIF directly to WM8804 output
    * Replace Microphone resistor with 2kohm
    * Replace output load impedance resistors on Audio with 110ohm
    [BlueBus.brd, BlueBus.sch]
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2019-11-05 [FIX] application: 1.0.9.11
    * Fix UI Flicker issues on BMBT
    * Fix issues with device connectivity in UI
    * Add code to handle DTR signal
    * Add PCM5122 support
    * Fix issues with large metadata crashing unit due to stack overflow
    * Add a timer to trap catches before resetting
    [bmbt.h, cli.c, main.c]
2019-11-10 [IMP] firmware: Application 1.0.9.14
    * R/T button on the steering wheel inconsistently pause/plays. I fixed this by instead using the talking head button for Pause / Play (only when not on a call).
    * The CD Changer status is now sent out any time the BlueBus sees the "ignition status" message. This is to hopefully prevent certain buggy Navigation radios from "forgetting" that it should be in CD Changer mode when you start the car.
    * The telephone button on the BoardMonitor now works like the "talking head" button on the steering wheel. Long pressing it will also activate Siri/Google Assistant.
    * The "3" button on the Business CD can now be used like the "talking head" button. Pressing it twi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
    [cli.c]
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2019-11-17 [IMP] firmware: Application 1.0.9.15 * Add Volume & Mic Gain to BMBT UI * Fix debug ignition setting * Initialize the PCM5122 on boot * Fix the MID UI not re-drawing the menu when the radio overwrite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
    [bmbt.h, cli.c, main.c]
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2019-12-10 [IMP] hardware: Production V1 * Add Fiducials * Fix bugs with PCM5122 DGND being floating and VCOM not being tied to AGND * Adjust routing so that all traces intersect at 90 degree angles on differen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
    [BlueBus.brd, BlueBus.sch]
2019-12-23 [IMP] hardware: Production V1 * Fix issue with silkscreen names * Add ground VIA
    [BlueBus.brd, BlueBus.sch]
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2020-01-27 [IMP] application: Firmware 1.0.9.29
    * Telephone Status LEDs are now used to indicate if a phone is connected to the BlueBus or not (MID / Navigation users only)
    * Telephone status is sent to the system, so the "TEL" button the MID and "Telephone" option in the Navigation menu will now appear and populate a menu. None of those options work, though!
    * The Telephone "Overlay" is now displayed when on a call on the Navigation screen. The "Phone" button that gets display doesn't do anything yet, though.
    * Improved Vehicle Auto Detection
    * The Number "4" on the Navigation Monitor now activate the Microphone Bias generator -- Do not use this if you don't know what that means -- it's probably alrea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
    [bmbt.h, cli.c, main.c]
2020-02-08 [IMP] application: Firmware 1.0.9.40
    * Improve support for Comfort Locks
    * Improve UI Auto-detection
    * Create functionality to switch UIs without a reboot
    * Create bit-map structs to reduce memory footprint
    * Identify cluster type (low / high)
    * Improve BMBT Menus
    [bmbt.h, cli.c, mappings.h]
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2020-04-04 [IMP] bootloader: Serial Number and Build Date * Add Commands to read and write the serial and build date to the bootloader * Fix bug with commands not making it back from the BL when switching the U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
    [mappings.h]
2020-04-05 [IMP] appliocation: Production Improvements (1.1.5) * Fix bug with setting mic gain * Add Upgrade script * Fix TCU Mode Changes in CD53 UI * Fix UI Fallback to CD53 * Fix MID UI Detection * Add Build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
    [bmbt.h, cli.c, main.c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]
2020-05-07 [IMP] application: Production Improvements (1.1.8) * Telephony ** Install cVc License (Clear Voice Capture for Echo / Noise Cancellation) ** Use cVc by default ** Track in-call volume and allow its a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
    [bmbt.h, cli.c, mappings.h]
2020-05-18 [IMP] application: Firmware 1.1.9 * Add Ability to set comfort features via CLI * Add ability to control call volume via volume knob * Fix issues with static layout writing long strings missing a cha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
    [cli.c, mappings.h]
2020-06-04 [IMP] application: Version 1.1.11 * Call volume does not cause music volume to go sky-high anymore * Call volume is adjusted as the user adjusts the volume regularly so that the same audio level can 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
    [bmbt.h, mappings.h]
2020-06-04 [IMP] hardware: V 1.1 * Reroute 3.3v rail under the PIC24 to prevent ground returns on the second layer from having to take a longer route * Bring 5v rail to top layer for a short run in order to ope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
    [BlueBus.brd, BlueBus.sch]
2020-06-27 [IMP] bootloader: Bootloader improvements for v1.4 * Shutdown unused ports * Correctly manage the BC127 PIO pin
    [main.c, mappings.h]
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2020-07-05 [IMP] application: Version 1.1.14 * Shutdown all unused I/O ports * Rename IO Port defines so they are consistent * Ignore values for coolant temperature that are outside of usual ranges * Resolve is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
    [bmbt.h, cli.c, main.c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]
2020-08-22 [IMP] hardware: V 1.2 * Power PAM8406 PVDDR and add bypass caps * Rework layout for PAM8406 and its passives * Connect floating VIAs to ground
    [BlueBus.brd, BlueBus.sch]
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2020-08-23 [IMP] application: v1.1.15 * Allow CD53 users to adjust in-call volume by not setting active call state * Unify the CD53 text length into a define * Fix auto-poweroff code not working
    [cli.c, mappings.h]
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2020-09-28 [IMP] firmware: Application Improvements * Add caller ID support * Add caller ID to Navigation Incoming Call screen * Improve VIN recognition logging * Improve LM Identification * Fix I2C implementat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
    [main.c]
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2020-10-23 [IMP] firmware: Application 1.1.16 [Handler] * Fix bug where volume changes outside of a call impacted the call volume offset * Set maximum volume offset for calls to 30 steps * Fix bug where call st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
    [cli.c, mappings.h]
2020-10-23 [IMP] hardware: v1.5 High Voltage improvements * Remove XRP6759 * Remove Old Tantalum C1 * Remove V1 * Remove L1 * Add common mode choke at input (L1) to filter out A/C * Add new Aluminum Polymer inp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
    [BlueBus.brd, BlueBus.sch]
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2020-11-15 [IMP] firmware: Application pre-1.1.17 improvements * Support Digital audio for calls when coax cable is used * Clean up telephony volume handling code * Set max volume offset to 12 steps * Add BLE/M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
    [bmbt.h]
2020-11-15 [IMP] firmware: Application Localization Support
    * Extended ASCII symbols support fix.
    * Device name normalization fixed.
    * UtilsNormalizeText method refactoring.
    * Friendly device name size increased.
    * Defines wording update.
    * Utils char maping table updated according russified BMW Navigation firmware.
    * Exclude not used chars and no-break space char from the supported ranged.
    * Cyrillic chars support for russified BMW navigation firmware.
    * Russian localization added.
    * Additional unicode characters support added.
    * Settings UI menu refresh on language selection.
    [bmbt.h, mappings.h]
2020-11-17 [IMP] firmware: Application Localization Improvements * Rename `local` to `locale` * Alphabetize `locale` in build scripts * Remove Apply option for Language in favor of keeping all languages in the 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
    [bmbt.h]
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2020-11-24 [IMP] firmware: Application 1.1.17 * I18n improvements * Catch for BC127 boot failure. Red TEL LED is now blinked to signify a fault * Added Config "Values" rather than "Settings" * Fix "Main Menu" S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
    [cli.c]
2020-12-09 [IMP] hardware: v1.1.6 * Re-wire BC127 power input for use with fixed regulated voltage, rather than battery power
    [BlueBus.brd, BlueBus.sch]
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2020-12-16 [IMP] hardware: v1.5 Updates * Replace ETQ-P4M100KFN 10uH inductor with MPL-SE5040 * Remove 100nF cap from 5v vreg output * Renumber Capacitors * Add 22uF caps to 3v3 vreg input and output for better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
    [BlueBus.brd, BlueBus.sch]
2020-12-16 [IMP] hardware: v1.6 Updates * Rewire BC127 UART * Configure BC127 power supply for fixed voltage * Add circuit for 5ms delay to VREG_EN pin of BC127
    [BlueBus.brd, BlueBus.sch]
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2021-08-30 [IMP] application: 1.1.18 Comfort: * Add ability to turn on parking lights (Angel Eyes on E39) * Add volume management feature to automatically set the phone volume to max * Add code to lower volume 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
    [bmbt.h, cli.c, main.c]
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2021-08-31 [FIX] firmware: Application 1.1.18 * Align buffer sizes across the application to ensure memory safety * Correctly utilize snprintf() and strncpy() to ensure we are not leaving memory on the table, o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
    [bmbt.h, cli.c]
2021-09-03 [IMP] hardware: v1.7 * Replace unavailable components * FT232RL -> FT231X * 25LC1024 -> AT25M01 * XC6710 -> S-1212BC0-M5T1U
    [BlueBus.brd, BlueBus.sch]
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2021-11-09 [IMP] firmware: Application 1.1.18 Increment updates General Enhancements: * Allow Users to override DSP Amp input source * Emulate MFL to allow volume scaling for CD53 vehicles * Fix issues with PDC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
    CD53:
    * Allow Bluetooth usage when vehicle is off but radio is manually turned on
    * Add additional settings [Comfort Unlock, Telephone volume offset, Lower Volume on Reverse]
    * Only show values when editing a setting
    * Enhance verbiage of settings
    MID:
    * Add additional settings [DSP, Comfort Unlock, Telephone volume offset, Lower Volume on Reverse]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
    [cli.c]
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2021-11-09 [IMP] firmware: Application 1.1.8 Improvements * Refactor Temperature code around BMBT UI * Store multiple configuration values in one byte for temperature settings * Add missing locale strings * Add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
    [bmbt.h]
2021-11-11 [IMP] firmware: Application 1.1.18 Release CLI * Wait for 15ms before rebooting into bootloader so that the debug message is not cut off CD53 / MID * Display setting until value is changed
    [cli.c]
2021-12-08 [IMP] firmware: Application Temperature Display Fixes
    * Fix Dashboard OBC redraw, small visual changes, use IKE formatted value when present
    * Fix Oil Temp Calculation
    * Request formatted temperature from OBC when it's not available
    * Add "Snowflake" to risky ambient temperatures in UI
    [bmbt.h]
2021-12-20 [IMP] firmware: Application Bug Fixes * Stop reading memory out of bounds for the CD53/MID Display text * Refresh the BMBT UI to the correct layout when the radio tries to change the layout
    [bmbt.h]
2022-01-25 [IMP] firmware: Application CD5x improvements * Account for CD54 display reset commands * Fix bug that causes CD5x UI to crash
    [bmbt.h, main.c]
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2022-03-30 [IMP] hardware: V2 Improvements * Increase the footprint for C1 and fix the name location * Remove PU/PD resistors from DIT4096 * Rewire I2S lines * Fix ground pour polygon dimensions * Replace 10ohm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
    [BlueBus.brd, BlueBus.sch]
2022-04-08 [IMP] hardware: V2 Bugfixes and improvements Bug fixes: * Wire floating S/PDIF reset pin to MCU * Add pull up to MCU pin 64 for board identification Improvements: * Added a 0.3mm isolation of the gro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
    [BlueBus.brd, BlueBus.sch]
2022-04-10 [IMP] hardware: V2 wiring and names * Update GND_FLT trace routing away from board cutout * Fix >NAME for some parts
    [BlueBus.brd]
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2022-04-24 [IMP] hardware: V2 silkscreen * Add fiducial markings * Fix issues with silkscreen
    [BlueBus.brd, BlueBus.sch]
2022-04-24 [IMP] hardware: V2 System UART Fix * Swap URX/UTX pins to maintain the same mapping as 1.x boards
    [BlueBus.brd, BlueBus.sch]
2022-04-28 [IMP] hardware: v2 Bugfixes * Swap BT UART lines * Move MCU_VER to pin 6 of PIC24 as pin 65 was used in 1.x * Swap MCLK and BCLK on DIT4096 * Add Cutout to board edge for panelization * Add diagonal 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
    [BlueBus.brd, BlueBus.sch]
2022-05-03 [IMP] hardware: v2 Bugfixes * Add missing ground plane for GND_FLT on bottom layer * Point all cathodes in the same directory for the three LEDs
    [BlueBus.brd, BlueBus.sch]
2022-05-17 [IMP] hardware: v2 Bugfixes * Ensure 100nF caps are closest to pins instead of 10uF/1uF * Fix bottom silkscreen * Fix recovery slider silkscreen * Renumber passives per convention (counter-clockwise)
    [BlueBus.brd, BlueBus.sch]
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2022-05-18 [IMP] hardware: v2 Bugfixes * Re-number capacitors per convention and ensure proper placement
    [BlueBus.brd, BlueBus.sch]
2022-05-19 [IMP] utility: Bootloader Protocol Updates * Add BT DFU mode * Add progress bar to console firmware tool * Replace "BC127" with "BT" * Add support for Bootloader 2.0
    [console_firmware_tool.py, gui_firmware_tool.py]
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2022-06-20 [IMP] hardware: v2 Hardware updates for manufacture * Remove USB cutout * Swap PTH holes to simple holes * Add tCream to USB mount holes
    [BlueBus.brd, BlueBus.sch]
2022-08-12 [IMP] firmware: Bootloader v2 * Use ISRs for UART * Add support for 128kB EEPROM * Rework protocol packet handling * Add catch for Application failing to boot * Add UART passthrough for BM83 updates 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
    [main.c, mappings.h]
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2022-08-13 [IMP] firmware: Application v1.2.1 Main Code * Add new defines for HW V2 Pins * Configure new HW V2 pins * Correctly Boot BM83 and DIT4096 ICs * Add flag for successful boot
    [main.c, mappings.h]
2022-08-15 [IMP] harcware: Hardware version 2.1 * Swap U4/S-1212BC0 for SOT23-5 package * Update resistor value for R19 to resolve bug with board version identification
    [BlueBus.brd, BlueBus.sch]
2022-08-16 [IMP] utility: console_firmware_tool * Update switch for Serial Number Burning to --writesn for consistency
    [console_firmware_tool.py]
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2022-08-22 [IMP] firmware: Application BC127 Improvements * Resolve issue with BM83 handler being errantly executed in BC127 mode * Fix bug with HFP being closed repeatedly * Add in BC127 CLI commands again
    [cli.c]
2022-08-23 [IMP] firmware: Application Bug fixes * Call API for `Play` when returning from a call * Fix issue with incorrect pin being set for TEL_MUTE
    [main.c]
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

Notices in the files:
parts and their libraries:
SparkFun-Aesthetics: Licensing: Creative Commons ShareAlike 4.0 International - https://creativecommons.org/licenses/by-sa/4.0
